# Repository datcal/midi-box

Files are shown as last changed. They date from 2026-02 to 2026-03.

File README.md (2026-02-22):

# MIDI Box

A DIY MIDI router and patchbay built on a Raspberry Pi 4. It connects all your synths, samplers, and sequencers — USB and DIN — and lets you control the routing from your phone or laptop via a web UI. You can also plug it into your Mac and Logic Pro sees every device as its own named MIDI port.

The whole thing runs headless in a box. A 5" touchscreen on the front shows a QR code to connect and a live routing overview.

---

## What it does

- **Routes MIDI** between up to 10 devices (6 USB + 4 five-pin DIN) with any-to-any routing
- **Web UI** — control routing, manage presets, monitor MIDI traffic, all from a browser
- **DAW mode** — plug into a Mac via USB-C and Logic Pro sees each synth as a named port
- **Standalone mode** — Pi handles everything internally, no Mac needed
- **Presets** — save and recall full routing configurations instantly
- **Clip launcher** — Ableton-style session view for triggering MIDI clips, quantized to the beat
- **MIDI file player** — play .mid files to any destination with tempo/loop control
- **MIDI monitor** — live scrolling view of all MIDI messages across all ports
- **Hotplug** — devices coming and going are detected automatically
- **WiFi hotspot** — Pi broadcasts its own network, no router needed

---

## Hardware

| # | Device | Type | Connection |
|---|---|---|---|
| 1 | Arturia KeyLab 88 MK2 | Controller | USB |
| 2 | Arturia KeyStep | Sequencer | USB |
| 3 | Behringer Model D | Mono synth | USB |
| 4 | Roland JP-08 | Polysynth | USB |
| 5 | Arturia MicroBrute | Mono synth | USB |
| 6 | Roland SP-404 MK2 | Sampler | USB |
| 7 | Korg MS-20 Mini | Mono synth | 5-Pin DIN |
| 8 | Korg Volca #1 | Synth | 5-Pin DIN |
| 9 | Korg Volca #2 | Synth | 5-Pin DIN |
| 10 | Korg Volca #3 | Synth | 5-Pin DIN |

**Pi hardware:**
- Raspberry Pi 4 (4GB)
- 5" DSI touchscreen (kiosk UI)
- 2× Waveshare powered USB hubs
- Custom MIDI I/O board (Pi native UARTs → 5-Pin DIN OUT)
- 5V 5A power supply (powers everything)

See [hardware/bom.md](hardware/bom.md) for the full bill of materials and [hardware/schematics/](hardware/schematics/) for circuit diagrams.

---

## How it's built

Two processes communicate over IPC:

```
Process 1 — MIDI Engine (src/main.py)
  Owns all hardware: USB MIDI via ALSA/rtmidi, Pi UARTs for DIN OUT, USB gadget
  Core routing loop: poll inputs → apply filters → send to outputs
  Handles commands from Flask via a shared queue

Process 2 — Web UI (src/ui_web.py)
  Flask app serving the browser UI and REST API
  Reads engine state every 200ms, sends commands via queue
  Never touches MIDI objects directly
```

The engine runs at ~1ms polling. The web UI refreshes at ~5Hz. They stay decoupled so a slow browser request never touches the MIDI loop.

Full architecture notes in [docs/software-arch.md](docs/software-arch.md).

---

## Running on a Mac (dev mode)

No hardware needed — runs with mock MIDI ports.

```bash
cd software
python3 -m venv .venv && source .venv/bin/activate
pip install -r requirements.txt
python3 src/main.py --mode standalone --platform mac --mock -v
```

Open [http://localhost:8080](http://localhost:8080).

Useful flags:
```
--list-devices     show detected MIDI ports
--list-presets     show saved presets
--preset NAME      load a preset on startup
--port PORT        change web UI port (default 8080)
```

---

## Deploying to a Raspberry Pi

Clone the repo onto the Pi and run the setup script once:

```bash
git clone https://github.com/datcal/midi-box ~/midi-box
cd ~/midi-box
sudo bash scripts/pi_setup.sh
```

This installs dependencies, sets up the systemd service, configures the WiFi hotspot, and adds the UART overlays for hardware MIDI. Reboot when it's done.

After reboot:
- WiFi network **MIDI-BOX** appears (password: `midibox123` — change it in Settings)
- Web UI at `http://192.168.4.1:8080`
- QR code on the touchscreen takes you straight there

The service starts on boot and restarts automatically if it crashes.

**Mac + Pi hybrid (DAW mode):**
Connect the Pi to your Mac via USB-C. The Pi's USB gadget presents each synth as a named MIDI port in Logic Pro. Change modes via the web UI or restart with `--mode daw`.

Software updates can be triggered from Settings → Software Update without SSHing in.

---

## Routing

Routes are point-to-point with optional per-route filters:

```json
{
  "from": "KeyLab 88 MK2",
  "to": "MS-20 Mini",
  "filter": {
    "channels": [1, 2],
    "message_types": ["note", "pitchwheel"],
    "velocity_min": 20,
    "remap_channel": 3
  }
}
```

Filter options: `channels`, `remap_channel`, `message_types` (`note`, `cc`, `program_change`, `pitchwheel`, `aftertouch`, `clock`, `sysex`), `velocity_min/max`, `cc_numbers`, `block_clock`, `block_sysex`.

Save any routing setup as a named preset and recall it instantly.

---

## Project layout

```
midi-box/
├── software/
│   ├── src/              Python source (14 modules)
│   ├── config/           App settings, device registry
│   ├── presets/          Saved routing presets (JSON)
│   └── web_ui/           Flask templates + vanilla JS/CSS
├── hardware/
│   ├── bom.md            Bill of materials
│   └── schematics/       MIDI I/O board circuit
├── docs/
│   ├── software-arch.md  Architecture decisions and latency notes
│   ├── gear-inventory.md MIDI specs for all 10 devices
│   └── build-phases.md   Build log
└── scripts/
    ├── pi_setup.sh       One-command Pi installer
    └── update.sh         OTA update helper (used by web UI)
```

---

## License

MIT — see [LICENSE](LICENSE).

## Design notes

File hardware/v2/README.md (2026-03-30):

# MIDI Box v2 — Integrated PCB Design

## Overview

Single custom PCB that replaces all discrete modules from v1 (Pi 4 + 2× Waveshare USB hubs + perfboard MIDI circuits + jumper wires). Everything on one board, designed in KiCad, manufactured and assembled in China (JLCPCB / PCBWay).

## What Changed from v1

| Aspect | v1 (Current) | v2 (This Design) |
|---|---|---|
| Compute | Raspberry Pi 4 full board | **CM4 module** on carrier (this PCB) |
| USB Hub | 2× Waveshare 4-port hubs | **On-board USB2514B** hub ICs (8 ports) |
| Power Input | 5V 5A barrel jack | **USB-C with PD** (STUSB4500 negotiates 5V/3A+) |
| MIDI OUT | Perfboard + jumper wires | **SMD resistors on PCB** + through-hole DIN-5 |
| Wiring | Dupont jumpers, USB cables | **PCB traces** — zero internal cables |
| Enclosure | 3D printed box for loose modules | 3D printed or CNC case **around single PCB** |

## Design Goals

1. **Single board** — CM4 carrier + USB hub + MIDI OUT + power, all on one PCB
2. **USB-C PD power** — standard charger input, no proprietary barrel jack
3. **8× USB-A downstream** — enough for 6 MIDI devices + 2 spare
4. **4× DIN-5 MIDI OUT** — same Pi UART-driven circuits as v1
5. **DSI connector** — 5" touchscreen ribbon passthrough
6. **DAW mode USB-C** — second USB-C port for CM4 USB gadget (Pi → Mac)
7. **Manufacturable** — 4-layer PCB, JLCPCB SMT assembly for SMD parts, hand-solder through-hole connectors
8. **CM4 + CM5 compatible** — same SO-DIMM connector pinout (verify mechanicals)

## Subsystems

| Subsystem | Key Components | Doc |
|---|---|-----|
| Compute | CM4 + Hirose DF40C-100DS connectors | [schematics.md](schematics.md) |
| USB Hub | 2× USB2514B (cascaded, 8 downstream) | [schematics.md](schematics.md) |
| USB-PD Power | STUSB4500 + USB-C connector | [power.md](power.md) |
| MIDI OUT | 4× UART → 220Ω → DIN-5 | [schematics.md](schematics.md) |
| All Components | Full BOM with LCSC part numbers | [bom.md](bom.md) |
| PCB Manufacturing | Layer stackup, fab specs, assembly notes | [pcb-spec.md](pcb-spec.md) |

## Board Size Estimate

~120mm × 100mm (4-layer, 1.6mm thickness). Final size depends on USB-A connector placement — 8 connectors in a row need ~110mm edge length.

## Software Compatibility

**No software changes needed.** The CM4 exposes the same GPIO, UART, USB, and DSI interfaces as the Pi 4. Same device tree overlays, same `/dev/ttyAMA*` paths, same ALSA MIDI stack. The `devices.yaml` and `midi_box.yaml` configs work as-is.

Only change: CM4 Lite (no eMMC) boots from SD card like Pi 4. CM4 with eMMC needs `rpiboot` to flash — update `scripts/inject_sdcard.sh` if using eMMC variant.

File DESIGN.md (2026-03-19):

# MIDI Box — AI Design Prompt

Use the prompt below to generate a new frontend design for this project. Copy-paste it into your AI design tool (v0, Bolt, Lovable, ChatGPT, etc.) and iterate from there.

---

## The Prompt

```
Design a modern, dark-themed web UI for a hardware MIDI router/patchbay called "MIDI Box".
This runs on a Raspberry Pi 4 and is accessed from a phone or laptop over WiFi.
The UI controls MIDI routing between 10 connected instruments (6 USB + 4 hardware DIN).

The design must be a single-page application with a sidebar navigation and a main content area.
Use vanilla HTML + CSS + JS (no frameworks, no build step).
Monospace font family (SF Mono / Fira Code / Consolas fallback).
Dark theme only — this is used in dim studios and on stage.

─────────────────────────────────────────
LAYOUT
─────────────────────────────────────────

Two-column layout:
- LEFT: Fixed sidebar (220px desktop, collapses to 60px icon-only on mobile)
- RIGHT: Scrollable main content area with page-based views

SIDEBAR contains:
- "MIDI BOX" branding header with accent color
- Mode badge (STANDALONE / DAW) — small pill, uppercase
- Live status row: pulsing dot animation + clock label (INT/EXT) + BPM display
- Warning banner when external MIDI clock is lost (yellow/orange)
- Navigation menu (11 items, icons + labels):
  1. Dashboard
  2. Routing
  3. Launcher
  4. Presets
  5. Record
  6. Player
  7. MIDI Monitor
  8. Logs
  9. USB Share
  10. System
  11. Settings
- Footer: large red PANIC button (sends all-notes-off) + device count

─────────────────────────────────────────
COLOR SYSTEM
─────────────────────────────────────────

Use CSS custom properties. Suggested palette (feel free to improve):

  --bg-primary:     deep dark navy      (main background)
  --bg-secondary:   slightly lighter     (sidebar, secondary panels)
  --bg-card:        card surfaces        (elevated cards)
  --bg-hover:       hover/active states
  --text-primary:   light gray           (#e0e0e0 range)
  --text-secondary: medium gray          (labels, hints)
  --text-muted:     dim gray             (disabled, timestamps)
  --accent:         teal/cyan            (primary action color — buttons, links, active states)
  --danger:         red                  (destructive actions, recording indicator)
  --warning:        orange/amber         (queued states, alerts)
  --success:        green                (connected, playing, success)
  --midi-in:        blue                 (MIDI input direction)
  --midi-out:       orange               (MIDI output direction)
  --midi-routed:    purple               (routed messages)
  --border:         subtle dark blue     (card borders, dividers)

─────────────────────────────────────────
PAGE 1: DASHBOARD
─────────────────────────────────────────

Header row with stat chips: device count, route count, total MIDI messages.

Clock widget (2-column card grid):
  - Clock Source card: INT/EXT badge + dropdown to select source device
  - Tempo card: large BPM number input (50px+ font) with −/+ stepper buttons

Connected Devices section:
  - "Rescan Devices" button
  - Warning banner if unconfigured devices detected
  - Responsive grid of device cards (min 240px each), each showing:
    - Device name (bold)
    - Port type badge (USB / DIN)
    - Direction badge (IN / OUT / BOTH)
    - Device type (Controller / Synth / Sampler)
    - Activity indicator dots: blue dot for IN, orange dot for OUT (with glow animation when active)
    - Message count (IN: X / OUT: Y)
    - "Configure" button opening a modal

─────────────────────────────────────────
PAGE 2: ROUTING (Patchbay)
─────────────────────────────────────────

This is the most important and visually striking page.

Mode tabs at top: "Perform" (keyboards → synths only) vs "Advanced" (all devices both sides).
Exclusive mode toggle (pill switch): one source connects to only one destination at a time.

Two-column patchbay layout:
  - LEFT column: Source devices (MIDI senders) — clickable boxes
  - RIGHT column: Destination devices (MIDI receivers) — clickable boxes
  - SVG overlay layer draws bezier curve connection lines between connected pairs
    - Active route: accent/teal colored line with arrow marker
    - Disabled route: gray dashed line
    - Hover preview: green line (will connect) or red line (will disconnect)

Device boxes:
  - Default: card background, subtle border
  - Selected (source): accent border + glow + accent background tint
  - Connected (destination): green border + subtle green background
  - Hover to connect: green border preview
  - Hover to disconnect: red border preview
  - Shows route count badge
  - Shows inline "Filter / Ch" button for connected routes

Below patchbay: Active Routes List
  - Each row: Source → Destination, filter summary text, action buttons (Filter, Enable/Disable toggle, Remove)

─────────────────────────────────────────
PAGE 3: LAUNCHER (Clip Session View)
─────────────────────────────────────────

Inspired by Ableton Live's session view.

Clock bar at top:
  - Clock source selector (Internal / device names)
  - BPM ± buttons and input (disabled when synced to external clock)
  - Quantum selector dropdown (Beat, Bar, 2 Bars, 4 Bars)
  - Time signature selector (4/4, 3/4, 6/8)
  - Beat visualization: "BAR N" label + 4 beat dots (12px circles that light up on active beat, glow animation)
  - Transport: green START button, red STOP button

Layer grid (horizontal rows):
  - Each row = one layer with: layer name, destination device, MIDI channel override
  - Clip slots in columns: 80×56px buttons with rounded corners
    - Empty: dashed border, dim "+" icon
    - Stopped: solid border, clip name label
    - Queued: pulsing orange border + background, warning color
    - Playing: glowing teal border + background, accent color
    - Hover reveals: × remove button (top-right), ↓ start-point marker (bottom-left)

Scene row at bottom: column-wide play buttons to trigger all clips in a column simultaneously.

Controls: Add Layer button, Upload .mid button, Stop All button.

─────────────────────────────────────────
PAGE 4: PRESETS
─────────────────────────────────────────

Simple list/grid of saved routing presets.
  - Each preset: name, click to load
  - Active preset: accent left border + tinted background
  - "Save Current" button opens a save dialog (text input for name)

─────────────────────────────────────────
PAGE 5: RECORD (Quick Recorder)
─────────────────────────────────────────

Clock bar: BPM display (read-only), quantize selector (Free, 1/16, 1/8, 1/4, Bar, 2 Bars, 4 Bars), beat dots.

Transport card:
  - State badge that changes color per state:
    - IDLE (muted), COUNT IN (purple, blinking), ● REC (red, blinking), ▶ PLAYING (green), STOPPED (gray)
  - Elapsed time display
  - Auto-play toggle
  - Buttons: RECORD (red, large), Stop, Play, Clear
  - Stats: event count, loop duration

Live Note Feed (scrollable, monospace):
  - Real-time list of captured MIDI events
  - Columns: Time, Source, Note (green), Velocity, Channel
  - Auto-scrolls during recording

Save section: text input for filename + "Save as .mid" button.

Saved recordings list: rows with name, duration, event count, Play/Download/Delete buttons.

─────────────────────────────────────────
PAGE 6: MIDI MONITOR
─────────────────────────────────────────

Controls: Pause/Resume, Clear, filter checkboxes (hide Clock, hide Active Sensing), message count.

Table with sticky header, 8 columns:
  - Time (HH:MM:SS.mmm)
  - Direction (color-coded: IN=blue, OUT=orange, ROUTED=purple)
  - Source device
  - Destination device
  - Message type (color-coded: NOTE=green, CC=orange, CLOCK=muted)
  - Channel
  - Data (velocity, CC value, etc.)
  - Raw hex bytes

Fast-scrolling, 500 message ring buffer. New messages appear at top.

─────────────────────────────────────────
PAGE 7: PLAYER (MIDI File Playback)
─────────────────────────────────────────

Clock bar: BPM ± and input, destination selector, loop toggle (pill switch), status badge, stop button.

Upload zone:
  - Large dashed-border drop area
  - Icon + "Drop .mid files here or tap to browse"
  - Progress bar overlay during upload

File browser:
  - Breadcrumb navigation for folders
  - Create Folder button
  - File list: folders (icon + name + item count), files (play button + name + duration + tracks)
  - Currently playing file highlighted with accent left border

─────────────────────────────────────────
PAGE 8: LOGS
─────────────────────────────────────────

Simple log viewer card.
  - Clear button
  - Scrollable monospace log area
  - Each entry: timestamp, log level (color-coded: INFO=blue, WARNING=orange, ERROR=red), logger, message

─────────────────────────────────────────
PAGE 9: SYSTEM
─────────────────────────────────────────

Stat cards (3-column grid):
  - CPU: percentage + animated progress bar
  - RAM: percentage + animated progress bar (color changes orange→red at thresholds)
  - Disk: percentage + animated progress bar

Info cards (3-column grid):
  - Temperature (°C)
  - Uptime (formatted)
  - Platform (Raspberry Pi / macOS)

Service control:
  - Status badge (RUNNING = green)
  - Red "Restart Service" button
  - Reconnection status during restart

─────────────────────────────────────────
PAGE 10: SETTINGS
─────────────────────────────────────────

Sections:
  1. Performance Mode toggle
  2. Network MIDI (RTP-MIDI): status badge, session list, rescan button
  3. Software Update: current version, latest version, check/install buttons, update log
  4. WiFi: two QR codes (WiFi join + URL), credentials display, change WiFi form (SSID + password)
  5. Export/Import: download state JSON, upload state JSON
  6. Reset to Defaults (red danger button)

─────────────────────────────────────────
PAGE 11: USB SHARE
─────────────────────────────────────────

  - VirtualHere server status badge + start/stop buttons
  - Warning banner when active (devices pause MIDI routing)
  - Connection instructions with numbered steps
  - Install section with setup button + log output
  - Server log viewer

─────────────────────────────────────────
SHARED COMPONENTS
─────────────────────────────────────────

Cards:
  - Background: card surface color, 1px border, 8px radius, subtle shadow
  - Card header: flex row, space-between, bold title + action buttons

Buttons:
  - Default: subtle border, transparent background, hover highlights
  - Accent: teal/cyan filled, white text
  - Danger: red-tinted background, red border, red text, fills red on hover
  - Small variant for inline actions

Badges/Pills:
  - Small uppercase labels with colored background tint + matching text + thin border
  - Used for: mode (STANDALONE), status (RUNNING), direction (IN/OUT), port type (USB/DIN)

Form inputs:
  - Dark background, subtle border, rounded corners
  - Select dropdowns styled consistently
  - Number inputs with stepper buttons where relevant

Modals:
  - Centered overlay with dark semi-transparent backdrop
  - Card-style modal box (400-500px width)
  - Form rows with labels

Info popovers:
  - Triggered by small circular "ⓘ" buttons
  - Two-section content: "Musician" (friendly) and "Developer" (technical)
  - Positioned within viewport, close on outside click

Toggle switches:
  - Pill-shaped toggle (34×19px track with sliding circle)
  - Off: gray track, On: accent colored track

─────────────────────────────────────────
RESPONSIVE DESIGN
─────────────────────────────────────────

Breakpoints:
  - Desktop (>768px): full sidebar, multi-column grids
  - Tablet/Mobile (≤768px): sidebar collapses to 60px icon-only, grids become single column, patchbay SVG lines hidden

Touch optimization (@media pointer: coarse):
  - Larger buttons (44px+ tap targets)
  - Increased padding on inputs and interactive elements
  - Larger beat dots (16px), clip slots (100px wide, 68px tall)
  - Bigger font sizes for BPM inputs and controls

─────────────────────────────────────────
ANIMATIONS
─────────────────────────────────────────

  - Live pulse: sidebar status dot pulses with scale + opacity (1.5s infinite)
  - Activity glow: device IN/OUT dots glow when receiving MIDI data
  - Clip queued: pulsing border animation (0.8s)
  - Recording blink: red badge blinks during recording (1s), faster during count-in (0.6s)
  - Progress bars: smooth width transitions (0.4s ease)
  - Beat dots: light up sequentially on each beat with subtle glow

─────────────────────────────────────────
DESIGN GOALS
─────────────────────────────────────────

  - Professional music production aesthetic — think Ableton Live, Native Instruments, or DAW plugin UIs
  - High contrast for readability in dark environments (studios, stages)
  - Information-dense but not cluttered — every pixel should serve a purpose
  - The routing patchbay should feel tactile and visual — it's the hero page
  - Real-time feel: activity dots, beat visualization, and state badges should feel alive
  - Touch-friendly: used on phone and Raspberry Pi 5" touchscreen
  - No external dependencies: no CDN fonts, no icon libraries, no CSS frameworks
  - Unicode characters for icons (or inline SVG)

─────────────────────────────────────────
TECHNICAL CONSTRAINTS
─────────────────────────────────────────

  - Output: single HTML file with embedded <style> and <script>, OR separate .html + .css + .js files
  - No build step, no npm, no framework — vanilla only
  - All pages are <div> sections toggled by JS (SPA, hash-based routing)
  - CSS custom properties for theming
  - Must work on: Chrome (desktop + Android), Safari (iOS), Chromium (Pi kiosk)
```

---

## How to Use This Prompt

1. **Copy** everything inside the code fence above
2. **Paste** into your AI design tool (v0.dev, Bolt.new, Lovable, ChatGPT Canvas, etc.)
3. **Iterate** — ask the AI to focus on specific pages ("now redesign just the routing patchbay")
4. **Extract** the HTML/CSS/JS and drop it into `software/web_ui/`

## Tips for Good Results

- Start with one page at a time rather than all 11 at once
- Ask for the **Routing patchbay** first — it's the most complex and visually important
- Then **Dashboard** + **Launcher** — the other two hero pages
- Ask for **just the CSS** if you want to keep the existing HTML structure
- Tell the AI which specific element you want changed ("make the sidebar more minimal", "redesign the device cards")

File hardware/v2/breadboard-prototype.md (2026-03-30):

# MIDI Box v2 — Breadboard Prototype (Same Components)

Test the v2 design on breadboards using the **exact same ICs and components** from [bom.md](bom.md). SMD parts go on adapter/breakout boards, then plug into the breadboard via 2.54mm pin headers.

---

## The Problem & Solution

SMD chips (QFN, SOT-23) can't plug into a breadboard. But you can solder them onto **adapter PCBs** that convert the SMD pads to standard 2.54mm DIP pins.

```
    SMD chip (QFN-36)          Adapter board              Breadboard
    ┌──────────┐          ┌──────────────────┐       ┌─────────────────┐
    │ ■■■■■■■■ │  solder  │ ■■■■■■■■         │  plug │ ○ ○ ○ ○ ○ ○ ○ ○│
    │ ■      ■ │ ───────→ │ ■      ■  ▌▌▌▌▌ │ ────→ │ ○ ○ ○ ○ ○ ○ ○ ○│
    │ ■■■■■■■■ │          │ ■■■■■■■■  ▌▌▌▌▌ │       │ ○ ○ ○ ○ ○ ○ ○ ○│
    └──────────┘          └──────────────────┘       └─────────────────┘
                           (pins on 2.54mm grid)
```

---

## Component-by-Component Plan

### Every v2 BOM item → how to put it on a breadboard:

| v2 Component | Package | Breadboard Method |
|---|---|---|
| **USB2514B** | QFN-36 | QFN-36 to DIP adapter + hand solder |
| **STUSB4500** | QFN-24 | QFN-24 to DIP adapter + hand solder |
| **AP2112K-3.3** (LDO) | SOT-23-5 | SOT-23 to DIP adapter + hand solder |
| **USBLC6-2SC6** (ESD) | SOT-23-6 | SOT-23 to DIP adapter + hand solder |
| **SS34 Schottky** | SMA | SMA to DIP adapter, OR use through-hole **1N5822** (same specs) |
| **24 MHz crystal** | 3215 SMD | Solder onto QFN adapter board next to USB2514B |
| **100nF caps** | 0402 | Use **through-hole 100nF ceramic** (same value, just bigger) |
| **10µF caps** | 0805 | Use **through-hole 10µF electrolytic** (same value) |
| **18pF caps** | 0402 | Use **through-hole 18pF ceramic** |
| **4.7µF cap** | 0805 | Use **through-hole 4.7µF ceramic/electrolytic** |
| **100µF cap** | 8×10mm electrolytic | Already through-hole — **use directly** |
| **220Ω resistors** | 0805 | Use **through-hole 220Ω 1/4W** (same value) |
| **1kΩ resistors** | 0402 | Use **through-hole 1kΩ 1/4W** |
| **1.5kΩ resistors** | 0402 | Use **through-hole 1.5kΩ 1/4W** |
| **5.1kΩ resistors** | 0402 | Use **through-hole 5.1kΩ 1/4W** |
| **10kΩ resistors** | 0402 | Use **through-hole 10kΩ 1/4W** |
| **500mA polyfuses** | 1206 | Use **through-hole 500mA polyfuse** (radial lead) |
| **LEDs** | 0805 | Use **5mm through-hole LEDs** (same colors) |
| **DIN-5 connectors** | Through-hole | **Use directly** — pins fit breadboard |
| **USB-A connectors** | Through-hole | **USB-A female breakout boards** (DIP) |
| **USB-C connectors** | SMD mid-mount | **USB-C female breakout boards** (DIP) |
| **DSI FPC connector** | SMD | Skip — test DSI on CM4 IO Board directly |
| **MicroSD slot** | SMD | Skip — CM4 IO Board has one built in |
| **CM4 + Hirose connectors** | SO-DIMM / 100-pin SMD | **Use CM4 IO Board** as stand-in |

`★ Insight ─────────────────────────────────────`
**Resistors and capacitors are value-defined, not package-defined.** A 220Ω resistor is 220Ω whether it's an 0805 SMD chip or a through-hole 1/4W axial. The circuit doesn't care about the physical size — only the electrical value matters. So for passives (R, C, L), you can freely use through-hole equivalents on a breadboard. The only components where the **exact same physical part** matters are the ICs — those have specific pinouts, internal logic, and configuration registers. That's why we use adapter boards for the ICs but through-hole substitutes for passives.
`─────────────────────────────────────────────────`

---

## Adapter Boards Shopping List

### QFN / SOT-23 to DIP Adapters

These are generic, gold-plated PCBs. Buy a variety pack — they're reusable.

| Adapter | For Which IC | Qty Needed | AliExpress Search | Amazon Search |
|---|---|---|---|---|
| **QFN-36 to DIP-36** (0.5mm pitch) | USB2514B | 2 | `"QFN36 to DIP36 adapter 0.5mm"` | `"QFN36 DIP adapter board"` |
| **QFN-24 to DIP-24** (0.5mm pitch) | STUSB4500 | 1 | `"QFN24 to DIP24 adapter 0.5mm"` | `"QFN24 DIP adapter board"` |
| **SOT-23-5/6 to DIP** | AP2112K, USBLC6 | 10 | `"SOT23 to DIP adapter board"` | `"SOT-23 breakout board"` |
| **SMA to DIP** | SS34 Schottky | 1 | `"SMA diode adapter DIP"` | — (or just use 1N5822 through-hole) |

**Recommended: buy a multi-pack adapter kit**

| Product | Price | What's Inside |
|---|---|---|
| **SMD to DIP adapter assortment kit** | ~$8–12 | AliExpress: `"SMD to DIP adapter board kit QFN SSOP SOT23"` — usually includes QFN-8/16/24/32/36/48, SSOP, SOT-23, SMA, all with pin headers |
| **Specific QFN-36 adapters (5-pack)** | ~$3 | AliExpress: `"QFN36 adapter board 0.5mm pitch"` |

> **Important:** Match the **pitch** (pad spacing) of the adapter to the IC. USB2514B is QFN-36 with **0.5mm pitch**. STUSB4500 is QFN-24 with **0.5mm pitch**. Most adapter kits include 0.5mm versions.

### Pin Headers

You'll solder 2.54mm pin headers onto each adapter board so they plug into the breadboard.

| Product | Qty | Price | Search |
|---|-----|---|---|
| **2.54mm male pin headers** (40-pin strips, breakable) | 5 strips | ~$1 | `"2.54mm pin header male 40 pin"` — you already have these if you've done any Arduino/Pi work |

---

## SMD ICs to Buy (Same as v2 BOM)

Order these from **LCSC.com** directly (minimum order ~$2 shipping). Same parts that go on the final PCB.

| IC | LCSC # | Package | Qty for Breadboard | Unit Price | Notes |
|----|---|---|---|---|---|
| USB2514B-I/M2 | C136518 | QFN-36 | 2 (+ 2 spare) | ~$2.50 | Order 4 — you'll want spares in case of soldering mistakes |
| STUSB4500QTR | C2678061 | QFN-24 | 1 (+ 1 spare) | ~$3.00 | Order 2 |
| AP2112K-3.3TRG1 | C51118 | SOT-23-5 | 1 (+ 2 spare) | ~$0.30 | Order 3 |
| USBLC6-2SC6 | C7519 | SOT-23-6 | 2 (+ 2 spare) | ~$0.25 | Only need 1-2 for testing, not all 9 |
| 24 MHz crystal (3215) | C32346 | 3215 SMD | 2 (+ 2 spare) | ~$0.20 | Solder next to USB2514B on adapter |

**LCSC order total: ~$15–20** (with spares and shipping)

> **Soldering QFN by hand:** You need flux paste, a fine-tip soldering iron (or hot air station), and a magnifier. QFN-36 at 0.5mm pitch is doable by hand but challenging. Search YouTube: `"hand solder QFN"` — drag soldering technique works. If you have a hot air rework station, that's even better. Practice on a spare adapter board first.

---

## Breadboard Connectors to Buy

| Product | Qty | Price | Source | Search |
|---|-----|---|---|---|
| **USB-C female breakout (DIP)** | 3 | ~$1 each | AliExpress | `"USB Type-C female breakout board DIP 2.54mm"` |
| **USB-A female breakout (DIP)** | 7 | ~$0.80 each | AliExpress | `"USB-A female breakout board DIP"` |
| **5-Pin DIN female connector** (PCB mount) | 4 | ~$1 each | AliExpress / Amazon | `"5 pin DIN female connector PCB mount"` — same ones as v2 BOM |
| **JST-XH 2-pin connectors** | 2 | ~$0.30 each | AliExpress | `"JST XH 2pin male PCB header"` — or just use bare wires for fans |

---

## Full Shopping List

### From LCSC.com (exact v2 BOM ICs)

| Item | LCSC # | Qty | Price |
|---|---|-----|---|
| USB2514B-I/M2 | C136518 | 4 | ~$10 |
| STUSB4500QTR | C2678061 | 2 | ~$6 |
| AP2112K-3.3TRG1 | C51118 | 3 | ~$1 |
| USBLC6-2SC6 | C7519 | 4 | ~$1 |
| 24 MHz crystal (3215) | C32346 | 4 | ~$1 |
| **LCSC subtotal** | | | **~$19 + $2 shipping** |

### From AliExpress (adapters + breakouts)

| Item | Qty | Price |
|---|-----|---|
| SMD to DIP adapter kit (QFN + SOT-23) | 1 kit | ~$10 |
| USB-C female breakout (DIP) | 3 | ~$3 |
| USB-A female breakout (DIP) | 7 | ~$6 |
| 5-Pin DIN female connectors | 4 | ~$4 |
| 2.54mm pin header strips | 5 | ~$1 |
| **AliExpress subtotal** | | **~$24** |

### From Amazon / Local Electronics Store (through-hole passives)

| Item | Qty | Price |
|---|-----|---|
| 220Ω resistor 1/4W | 20 (pack) | ~$1 |
| 1kΩ resistor 1/4W | 20 (pack) | ~$1 |
| 1.5kΩ resistor 1/4W | 10 (pack) | ~$1 |
| 5.1kΩ resistor 1/4W | 10 (pack) | ~$1 |
| 10kΩ resistor 1/4W | 10 (pack) | ~$1 |
| 100nF ceramic cap (through-hole) | 20 (pack) | ~$1 |
| 10µF electrolytic cap | 10 (pack) | ~$1 |
| 18pF ceramic cap (through-hole) | 10 (pack) | ~$1 |
| 4.7µF ceramic/electrolytic | 5 | ~$1 |
| 100µF electrolytic cap | 5 | ~$1 |
| 1N5822 Schottky diode (through-hole) | 5 | ~$1 |
| 500mA polyfuse (radial through-hole) | 10 | ~$2 |
| 5mm LEDs (green, blue, yellow assorted) | 10 | ~$1 |
| Full-size breadboard (830 pts) | 2 | ~$10 |
| Jumper wire kit (M-M, M-F) | 1 | ~$5 |
| **Local subtotal** | | **~$29** |

### From Pi Reseller (compute)

| Item | Qty | Price |
|---|-----|---|
| Raspberry Pi CM4 (2GB, WiFi, Lite) | 1 | ~$35 |
| CM4 IO Board (official Raspberry Pi) | 1 | ~$35 |
| **Pi subtotal** | | **~$70** |

### Tools You Need

| Tool | Price | Notes |
|---|---|---|
| Fine-tip soldering iron (or station) | ~$30+ | You probably have one from v1 |
| Solder flux paste (no-clean) | ~$5 | **Essential** for QFN soldering |
| Solder wick / desoldering braid | ~$3 | For fixing bridges |
| Magnifying glass / loupe (10×) | ~$5 | Inspect QFN solder joints |
| USB-C power meter (WITRN C5) | ~$20 | Test PD negotiation + monitor voltage/current |
| Multimeter | — | You have one |
| **Tools subtotal** | **~$33** (if you have soldering iron already: ~$3) |

---

### Total Cost

| Category | Cost |
|---|---|
| LCSC ICs (same parts as v2) | ~$21 |
| AliExpress adapters + breakouts | ~$24 |
| Through-hole passives + breadboard | ~$29 |
| CM4 + IO Board | ~$70 |
| Tools (flux, wick, power meter) | ~$28 |
| **Total** | **~$172** |

> **Note:** The CM4 + IO Board ($70) is not wasted money — the CM4 goes into your final v2 PCB, and the IO Board stays as a permanent debug tool. So the actual "testing overhead" cost is ~$102.

---

## Assembly: Solder ICs onto Adapter Boards

### USB2514B on QFN-36 Adapter (×2)

```
    QFN-36 Adapter Board (top view)
    ┌──────────────────────────────────────┐
    │                                      │
    │  Solder USB2514B (QFN-36) here       │
    │  ┌────────────┐                      │
    │  │ ■■■■■■■■■ │  Also solder nearby: │
    │  │ ■        ■ │  - Y1 (24 MHz xtal) │
    │  │ ■        ■ │  - 2× 18pF caps     │
    │  │ ■■■■■■■■■ │    (CY1a, CY1b)     │
    │  └────────────┘                      │
    │                                      │
    │  ▌▌▌▌▌▌▌▌▌  ← DIP pins (left)      │
    │  ▌▌▌▌▌▌▌▌▌  ← DIP pins (right)     │
    └──────────────────────────────────────┘
```

**Why solder the crystal on the adapter too:** The crystal and its load caps must be physically close (<10mm) to the IC. You can't run them through long breadboard jumper wires — the parasitic capacitance will prevent the oscillator from starting. Solder Y1 + 18pF caps directly on the adapter board, next to the USB2514B.

**QFN soldering steps:**
1. Apply flux paste to the adapter pads
2. Tin one corner pad with a small solder blob
3. Align the IC — tack one corner
4. Check alignment under magnifier
5. Drag-solder remaining pins (or use hot air)
6. Check for bridges with magnifier
7. Remove bridges with solder wick
8. Solder crystal and load caps on nearby pads
9. Solder 2.54mm pin headers on the DIP pads
10. Plug into breadboard

### STUSB4500 on QFN-24 Adapter (×1)

Same process as above, but QFN-24. No crystal needed — just the IC itself.

### AP2112K on SOT-23-5 Adapter (×1)

SOT-23 is much easier to solder than QFN — big pads, visible pins. Straightforward.

### USBLC6 on SOT-23-6 Adapter (×2)

Same as AP2112K — easy SOT-23 soldering. You only need 1-2 for breadboard testing (one on the upstream USB, one on a downstream port). The other 7 can be skipped for prototype.

---

## Breadboard Wiring (Exact v2 Circuit)

### Power Input Section

```
    USB-C breakout #1 (J3 — PD power input)
    ┌────────────┐
    │ VBUS ──────┼──→ STUSB4500 adapter VBUS_EN_SNK pin
    │ CC1 ───────┼──→ 5.1kΩ → GND  AND  STUSB4500 CC1 pin
    │ CC2 ───────┼──→ 5.1kΩ → GND  AND  STUSB4500 CC2 pin
    │ GND ───────┼──→ GND rail
    └────────────┘

    STUSB4500 adapter board (plugged into breadboard)
    ┌────────────────┐
    │ VBUS_EN_SNK ───┼──← USB-C VBUS
    │ CC1 ───────────┼──← USB-C CC1
    │ CC2 ───────────┼──← USB-C CC2
    │ VDD ───────────┼──← 3.3V rail (from LDO)
    │ ADDR ──────────┼──→ 10kΩ → GND
    │ SCL ───────────┼──→ CM4 GPIO 3 (I2C SCL) via IO Board
    │ SDA ───────────┼──→ CM4 GPIO 2 (I2C SDA) via IO Board
    │ POWER_OK ──────┼──→ 1kΩ → green LED → GND (PD status)
    │ GND ───────────┼──→ GND rail
    └────────────────┘

    STUSB4500 VBUS output → 1N5822 anode → cathode → VBUS_5V rail
                                                       │
                                                    100µF cap → GND

    VBUS_5V rail → AP2112K adapter IN → OUT → V3V3 rail
                                          │
                                       10µF cap → GND
```

### USB Hub Section

```
    CM4 IO Board USB-A port
    ──→ cut USB cable ──→ wires:
         red   (5V)  → not needed (hub powered from VBUS_5V rail)
         white (D-)  → USBLC6 adapter IO1 → USB2514B adapter #1 USBDM pin
         green (D+)  → USBLC6 adapter IO2 → USB2514B adapter #1 USBDP pin
         black (GND) → GND rail

    USB2514B Adapter #1 (root hub, plugged into breadboard)
    ┌────────────────────┐
    │ VDD33 ─────────────┼──← V3V3 rail + 100nF cap → GND
    │ VDDA33 ────────────┼──← V3V3 rail + 100nF cap → GND
    │ CRFILT ────────────┼──→ 10nF cap → GND
    │ USBDP ─────────────┼──← CM4 USB D+ (via USBLC6)
    │ USBDM ─────────────┼──← CM4 USB D- (via USBLC6)
    │ RESET_N ───────────┼──→ 10kΩ → V3V3
    │ CFG_SEL0 ──────────┼──→ GND (pin-strap mode)
    │ CFG_SEL1 ──────────┼──→ GND
    │ VBUS_DET ──────────┼──← VBUS_5V via 100kΩ/47kΩ divider
    │                    │
    │ DN1_DP ────────────┼──→ USB-A breakout #1 D+  (→ MIDI device 1)
    │ DN1_DM ────────────┼──→ USB-A breakout #1 D-
    │ DN2_DP ────────────┼──→ USB-A breakout #2 D+  (→ MIDI device 2)
    │ DN2_DM ────────────┼──→ USB-A breakout #2 D-
    │ DN3_DP ────────────┼──→ USB-A breakout #3 D+  (→ MIDI device 3)
    │ DN3_DM ────────────┼──→ USB-A breakout #3 D-
    │ DN4_DP ────────────┼──→ USB2514B adapter #2 USBDP (cascade)
    │ DN4_DM ────────────┼──→ USB2514B adapter #2 USBDM (cascade)
    │ GND ───────────────┼──→ GND rail
    └────────────────────┘

    USB2514B Adapter #2 (tier 2 hub, plugged into breadboard)
    ┌────────────────────┐
    │ (same power/config │
    │  wiring as #1)     │
    │                    │
    │ USBDP ─────────────┼──← Hub #1 DN4_DP (cascade)
    │ USBDM ─────────────┼──← Hub #1 DN4_DM
    │                    │
    │ DN1_DP ────────────┼──→ USB-A breakout #4 D+  (→ MIDI device 4)
    │ DN1_DM ────────────┼──→ USB-A breakout #4 D-
    │ DN2_DP ────────────┼──→ USB-A breakout #5 D+  (→ MIDI device 5)
    │ DN2_DM ────────────┼──→ USB-A breakout #5 D-
    │ DN3_DP ────────────┼──→ USB-A breakout #6 D+  (→ MIDI device 6)
    │ DN3_DM ────────────┼──→ USB-A breakout #6 D-
    │ DN4_DP ────────────┼──→ USB-A breakout #7 D+  (→ spare)
    │ DN4_DM ────────────┼──→ USB-A breakout #7 D-
    │ GND ───────────────┼──→ GND rail
    └────────────────────┘

    Each USB-A breakout:
    VBUS → VBUS_5V rail via 500mA polyfuse
    D+   → from hub DN port
    D-   → from hub DN port
    GND  → GND rail
```

### MIDI OUT Section

```
    MIDI OUT 1 (MS-20 Mini):
    VBUS_5V rail → 220Ω → DIN-5 (J5) Pin 4
    CM4 IO Board GPIO 14 (physical pin 8) → 220Ω → DIN-5 (J5) Pin 5
    DIN-5 (J5) Pin 2 → GND rail

    MIDI OUT 2 (Volca #1):
    VBUS_5V rail → 220Ω → DIN-5 (J6) Pin 4
    CM4 IO Board GPIO 4 (physical pin 7) → 220Ω → DIN-5 (J6) Pin 5
    DIN-5 (J6) Pin 2 → GND rail

    MIDI OUT 3 (Volca #2):
    VBUS_5V rail → 220Ω → DIN-5 (J7) Pin 4
    CM4 IO Board GPIO 8 (physical pin 24) → 220Ω → DIN-5 (J7) Pin 5
    DIN-5 (J7) Pin 2 → GND rail

    MIDI OUT 4 (Volca #3):
    VBUS_5V rail → 220Ω → DIN-5 (J8) Pin 4
    CM4 IO Board GPIO 12 (physical pin 32) → 220Ω → DIN-5 (J8) Pin 5
    DIN-5 (J8) Pin 2 → GND rail
```

### DAW Mode USB-C Section

```
    USB-C breakout #2 (J4 — DAW port)
    ┌────────────┐
    │ D+ ────────┼──→ CM4 IO Board USB OTG D+
    │ D- ────────┼──→ CM4 IO Board USB OTG D-
    │ CC1 ───────┼──→ 5.1kΩ → GND
    │ CC2 ───────┼──→ 5.1kΩ → GND
    │ VBUS ──────┼──→ not connected
    │ GND ───────┼──→ GND rail
    └────────────┘
```

### Status LEDs

```
    Power:          VBUS_5V → 1kΩ → green LED → GND
    PD status:      STUSB4500 POWER_OK → 1kΩ → blue LED → GND
    MIDI TX 1:      GPIO 14 line → 1kΩ → yellow LED → GND
    MIDI TX 2:      GPIO 4  line → 1kΩ → yellow LED → GND
    MIDI TX 3:      GPIO 8  line → 1kΩ → yellow LED → GND
    MIDI TX 4:      GPIO 12 line → 1kΩ → yellow LED → GND
```

---

## Physical Layout (3 Breadboards)

```
    ┌─ BREADBOARD 1: POWER ────────────────────────────────────────┐
    │                                                               │
    │  [USB-C brk]   [STUSB4500]   [1N5822]   [AP2112K]          │
    │   (J3, PD)      adapter      diode        adapter            │
    │                                                               │
    │  [100µF]  [10kΩ]  [5.1kΩ×2]  [100nF×2]  [10µF]  [LED grn] │
    │                                                               │
    │  VBUS_5V rail ━━━━━━━━━━━━━━━━━━━━━━━━━━━━━━━━━━━━━━━━━━━━  │
    │  GND rail ━━━━━━━━━━━━━━━━━━━━━━━━━━━━━━━━━━━━━━━━━━━━━━━━  │
    │  V3V3 rail ━━━━━━━━━━━━━━━━━━━━━━━━━━━━━━━━━━━━━━━━━━━━━━━  │
    └───────────────────────────────────────────────────────────────┘
          │ (bridge 5V, 3.3V, GND to BB2)
          ▼
    ┌─ BREADBOARD 2: USB HUB ──────────────────────────────────────┐
    │                                                               │
    │  [USB2514B #1]       [USB2514B #2]                           │
    │    adapter             adapter                                │
    │   (root hub)          (cascade)                               │
    │                                                               │
    │  [USBLC6]  [100nF×8]  [10µF×2]  [10kΩ×2]  [1.5kΩ×2]       │
    │                                                               │
    │  [USB-A brk1] [brk2] [brk3] [brk4] [brk5] [brk6] [brk7]   │
    │  + polyfuse    + pf   + pf   + pf   + pf   + pf   + pf      │
    │                                                               │
    │  [USB-C brk]  ← DAW port (J4) + 5.1kΩ×2                    │
    └───────────────────────────────────────────────────────────────┘
          │ (bridge 5V, GND to BB3)
          ▼
    ┌─ BREADBOARD 3: MIDI OUT + LEDS ──────────────────────────────┐
    │                                                               │
    │  [220Ω×2] → [DIN-5]   [220Ω×2] → [DIN-5]                   │
    │   MS-20 (J5)            Volca 1 (J6)                         │
    │                                                               │
    │  [220Ω×2] → [DIN-5]   [220Ω×2] → [DIN-5]                   │
    │   Volca 2 (J7)          Volca 3 (J8)                         │
    │                                                               │
    │  [1kΩ→LED] [1kΩ→LED] [1kΩ→LED] [1kΩ→LED]  ← MIDI TX LEDs  │
    │                                                               │
    │  [Fan header 1]  [Fan header 2]   ← 5V direct               │
    └───────────────────────────────────────────────────────────────┘

    CM4 IO Board (off-breadboard, on desk):
    ├── CM4 module plugged in
    ├── MicroSD inserted
    ├── DSI ribbon → 5" touchscreen
    ├── USB-A port → cut cable → BB2 hub upstream
    ├── GPIO 14 (pin 8)  → jumper wire → BB3 MIDI 1
    ├── GPIO 4  (pin 7)  → jumper wire → BB3 MIDI 2
    ├── GPIO 8  (pin 24) → jumper wire → BB3 MIDI 3
    ├── GPIO 12 (pin 32) → jumper wire → BB3 MIDI 4
    ├── GPIO 2  (pin 3)  → jumper wire → BB1 STUSB4500 SCL
    ├── GPIO 3  (pin 5)  → jumper wire → BB1 STUSB4500 SDA
    └── GND (pin 6)      → jumper wire → BB1 GND rail
```

---

## Important Warnings

### USB Signal Integrity on Breadboard

USB 2.0 data lines (D+/D-) are sensitive to capacitance and impedance. Breadboard wiring adds ~5–10pF per jumper wire. This matters:

| Scenario | Will It Work? | Why |
|---|---|-----|
| Hub upstream (CM4 → Hub IC, short wire) | **Yes** | Short run, Full Speed (12 Mbps) tolerant |
| Hub downstream (Hub IC → USB-A, short wire) | **Yes** | MIDI devices are Full Speed |
| Long jumper wires (>15cm) | **Maybe not** | Excess capacitance can cause enumeration failures |
| Hub cascade (Hub #1 → Hub #2, breadboard wire) | **Likely yes** | Keep wires <5cm, use twisted pair if possible |

**Tips:**
- Keep USB D+/D- jumper wires **as short as possible** (< 10cm)
- Twist D+ and D- wires together (reduces noise pickup)
- If a device doesn't enumerate, try a shorter wire first
- MIDI devices are very low bandwidth — they're forgiving

### Crystal Oscillator

The 24 MHz crystal **must** be soldered onto the adapter board next to the IC, not wired via breadboard. Breadboard parasitics will prevent the oscillator from starting. This is the one component that cannot be on the breadboard.

### Power Rails

- Use **both** power rails on each breadboard (top and bottom)
- Bridge them together at both ends of each board
- Add 100nF + 10µF decoupling at every adapter board's power pins
- Run 5V and GND wires between breadboards using thick (22AWG) jumper wires

---

## Test Sequence

Same tests as [testing-plan.md](testing-plan.md), but now with exact v2 components:

| # | Test | Pass Criteria |
|---|---|---|
| 1 | Plug PD charger into USB-C breakout | STUSB4500 POWER_OK LED on, multimeter reads 4.7–5.0V on VBUS_5V |
| 2 | Check 3.3V rail | Multimeter reads 3.3V on V3V3 rail |
| 3 | Boot CM4 on IO Board (powered from VBUS_5V) | CM4 boots, WiFi works, SSH works |
| 4 | USB2514B #1 enumerates | `lsusb` shows Microchip USB hub |
| 5 | USB2514B #2 enumerates (cascade) | `lsusb` shows two Microchip USB hubs |
| 6 | Plug MIDI device into each USB-A breakout | All 6 show in `aconnect -l` |
| 7 | Send MIDI to each DIN-5 port | Synths respond (MS-20, 3× Volca) |
| 8 | DAW mode via USB-C breakout #2 | Mac sees Pi as MIDI device |
| 9 | Run full midi-box software | Web UI works, routing works, presets load |
| 10 | 1-hour stress test | No crashes, no USB disconnects, voltage stable |
| 11 | Measure total current | < 4A (matches power.md budget) |

**If all 11 tests pass → order the final v2 PCB with confidence.**

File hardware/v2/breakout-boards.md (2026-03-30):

# MIDI Box v2 — SMD Breakout Boards for Breadboard Testing

Instead of buying generic off-the-shelf modules, design **small breakout PCBs** for each SMD IC. Solder the SMD parts on the breakout, bring pins out to 2.54mm headers, plug into breadboard.

This gives you **exact same circuits as the final v2 PCB** — just split across small boards connected by jumper wires.

---

## Why Custom Breakout PCBs

- You test the **exact same ICs** (USB2514B, STUSB4500) that go on the final board
- Catches datasheet wiring mistakes early (wrong pin, missing cap)
- Breakout PCBs are **tiny and cheap** — $2 for 5 boards at JLCPCB, 2-layer is fine
- You practice SMD soldering on small boards before committing to the big one
- Reusable — keep them as test fixtures even after the v2 PCB works

`★ Insight ─────────────────────────────────────`
**This is standard practice in hardware engineering.** Companies like Adafruit and SparkFun literally sell breakout boards for this exact reason — the STUSB4500 breakout from SparkFun is $12. But you can make your own in EasyEDA for $2 in quantity 5, with the exact same circuit you designed. If it works on the breakout, it works on the final PCB — the IC doesn't know what board it's on.
`─────────────────────────────────────────────────`

---

## Breakout Board Designs (4 boards)

### Board 1: USB Hub Breakout (USB2514B)

**Size:** ~30mm × 40mm, 2-layer

**SMD components ON the breakout:**
- 1× USB2514B-I/M2 (QFN-36) — `C136518`
- 1× 24 MHz crystal — `C32346`
- 2× 18pF cap (0402) — `C1808`
- 4× 100nF cap (0402) — `C1525`
- 1× 10µF cap (0805) — `C19702`
- 1× 1.5kΩ resistor (0402) — `C4026`

**Pin headers OUT (2.54mm, breadboard-compatible):**

```
    Left side (1×10 header):         Right side (1×10 header):
    ┌────────────────────┐
    │ USBUP_D+     DN1_D+ │
    │ USBUP_D-     DN1_D- │
    │ VDD (5V)     DN2_D+ │
    │ GND          DN2_D- │
    │ RESET_N      DN3_D+ │
    │ CFG_SEL0     DN3_D- │
    │ CFG_SEL1     DN4_D+ │
    │ VBUS_DET     DN4_D- │
    │ 3.3V IN      GND    │
    │ GND          GND    │
    └────────────────────┘
```

**Make 2 of these** — one for IC1 (root hub), one for IC2 (cascaded). On the breadboard, wire IC1 DN4 → IC2 upstream to cascade them.

**EasyEDA steps:**
1. New project: `usb-hub-breakout`
2. Place USB2514B (`C136518`), crystal, caps, resistor
3. Wire exactly as in [schematics.md](schematics.md) Section 2
4. Add 2× 1×10 male pin headers (search `C124378` — 1×10 2.54mm)
5. Route on 2-layer, no impedance control needed (traces are <15mm)
6. Board outline: 30×40mm

**JLCPCB order:**
- 2-layer, 5 pcs, 1.6mm, HASL — ~$2
- SMT assembly for SMD parts — ~$8
- Total: ~$10 for 5 boards (you need 2)

---

### Board 2: USB-PD Breakout (STUSB4500)

**Size:** ~20mm × 25mm, 2-layer

**SMD components ON the breakout:**
- 1× STUSB4500QTR (QFN-24) — `C2678061`
- 2× 5.1kΩ resistor (0402) — `C25905` (CC pull-downs)
- 1× 10kΩ resistor (0402) — `C25744` (ADDR)
- 1× 4.7µF cap (0805) — `C1779`
- 1× 100nF cap (0402) — `C1525`

**Connectors ON the breakout:**
- 1× USB-C 16-pin receptacle — `C2765186` (solder directly on breakout)

**Pin headers OUT:**

```
    1×6 header:
    ┌──────────┐
    │ VBUS_OUT │ → 5V from PD charger (after negotiation)
    │ GND      │
    │ POWER_OK │ → HIGH when PD contract established
    │ SCL      │ → I2C clock (for NVM programming)
    │ SDA      │ → I2C data
    │ 3.3V IN  │ → supply for STUSB4500 logic
    └──────────┘
```

**On breadboard:**
- Plug header into breadboard
- VBUS_OUT → 5V power rail
- Connect SCL/SDA to Pi GPIO 2/3 (for one-time NVM programming)
- 3.3V IN from AMS1117 module or another source

**EasyEDA steps:**
1. New project: `usb-pd-breakout`
2. Place STUSB4500 (`C2678061`), USB-C connector (`C2765186`), resistors, caps
3. Wire as in [power.md](power.md) STUSB4500 circuit section
4. Add 1×6 male pin header
5. Board outline: 20×25mm

---

### Board 3: USB-C Gadget Port Breakout (DAW Mode)

**Size:** ~15mm × 20mm, 2-layer

This one is super simple — just a USB-C connector with CC resistors, broken out to pins.

**SMD components ON the breakout:**
- 2× 5.1kΩ resistor (0402) — `C25905`

**Connectors ON the breakout:**
- 1× USB-C 16-pin receptacle — `C2765186`

**Pin headers OUT:**

```
    1×4 header:
    ┌──────┐
    │ D+   │ → to Pi USB OTG / CM4 gadget port
    │ D-   │
    │ VBUS │ → sense only (from Mac)
    │ GND  │
    └──────┘
```

**On breadboard:**
- Not actually needed for breadboard — just connect a USB-C cable from Pi to Mac
- But useful to validate the USB-C connector footprint and CC resistor values

---

### Board 4: MIDI OUT Breakout (×1, simple)

**Size:** ~25mm × 35mm, 2-layer

Optional — you could just do this on the breadboard with through-hole parts. But if you want to validate the exact SMD layout:

**SMD components ON the breakout:**
- 2× 220Ω resistor (0805) — `C17557`
- 1× yellow LED (0805) — `C2296` (optional)
- 1× 1kΩ resistor (0402) — `C11702` (optional, for LED)

**Connectors ON the breakout:**
- 1× DIN-5 female (through-hole) — hand solder

**Pin headers OUT:**

```
    1×3 header:
    ┌───────┐
    │ 5V    │ → power rail
    │ TX    │ → Pi GPIO UART TX
    │ GND   │ → ground
    └───────┘
```

**Make 4 of these** for all 4 MIDI ports — or just 1 and test each UART sequentially.

---

## Complete Breakout → Breadboard Wiring

```
    ┌───────────────────────────────────────────────────────────┐
    │                     BREADBOARD                            │
    │  [+5V rail] ━━━━━━━━━━━━━━━━━━━━━━━━━━━━━━━━━━━━━━━━━━  │
    │  [GND rail] ━━━━━━━━━━━━━━━━━━━━━━━━━━━━━━━━━━━━━━━━━━  │
    │                                                           │
    │  ┌──────────┐                                             │
    │  │ PD Board │ VBUS_OUT ──→ 5V rail                       │
    │  │ (Board 2)│ GND ──→ GND rail                           │
    │  │ USB-C IN │ 3.3V IN ←── AMS1117 out                    │
    │  └──────────┘                                             │
    │       │ (or skip PD board, use 5V bench supply directly)  │
    │                                                           │
    │  ┌──────────────┐  ┌──────────────┐                      │
    │  │ Hub Board #1 │  │ Hub Board #2 │                      │
    │  │  (Board 1a)  │  │  (Board 1b)  │                      │
    │  │              │  │              │                        │
    │  │ USBUP_D+/D- │  │ USBUP_D+/D- │                       │
    │  │  ↑ from Pi   │  │  ↑ from Hub1 │                      │
    │  │  USB port    │  │    DN4       │                       │
    │  │              │  │              │                        │
    │  │ DN1 ──→ USB-A breakout ──→ MIDI device 1              │
    │  │ DN2 ──→ USB-A breakout ──→ MIDI device 2              │
    │  │ DN3 ──→ USB-A breakout ──→ MIDI device 3              │
    │  │ DN4 ──→ Hub Board #2 upstream                         │
    │  │              │  │ DN1 ──→ USB-A breakout ──→ device 4 │
    │  └──────────────┘  │ DN2 ──→ USB-A breakout ──→ device 5 │
    │                     │ DN3 ──→ USB-A breakout ──→ device 6 │
    │                     │ DN4 ──→ USB-A breakout ──→ spare    │
    │                     └──────────────┘                      │
    │                                                           │
    │  MIDI OUT ports (Board 4 ×4, or through-hole on BB):     │
    │  ┌───────┐ ┌───────┐ ┌───────┐ ┌───────┐                │
    │  │MIDI 1 │ │MIDI 2 │ │MIDI 3 │ │MIDI 4 │                │
    │  │5V←rail│ │5V←rail│ │5V←rail│ │5V←rail│                │
    │  │TX←GP14│ │TX←GP4 │ │TX←GP8 │ │TX←GP12│                │
    │  │GND←rl │ │GND←rl │ │GND←rl │ │GND←rl │                │
    │  │[DIN5] │ │[DIN5] │ │[DIN5] │ │[DIN5] │                │
    │  └───────┘ └───────┘ └───────┘ └───────┘                │
    │                                                           │
    │  [+5V rail] ━━━━━━━━━━━━━━━━━━━━━━━━━━━━━━━━━━━━━━━━━━  │
    │  [GND rail] ━━━━━━━━━━━━━━━━━━━━━━━━━━━━━━━━━━━━━━━━━━  │
    └───────────────────────────────────────────────────────────┘

    Raspberry Pi 4 (off breadboard):
    ├── USB-A port → cut cable → Hub Board #1 upstream (D+, D-, 5V, GND)
    ├── GPIO 14 (pin 8)  → jumper → MIDI 1 TX
    ├── GPIO 4  (pin 7)  → jumper → MIDI 2 TX
    ├── GPIO 8  (pin 24) → jumper → MIDI 3 TX
    ├── GPIO 12 (pin 32) → jumper → MIDI 4 TX
    ├── 5V (pin 2) → jumper → 5V rail (if not using PD board)
    └── GND (pin 6) → jumper → GND rail
```

---

## Order Summary for Breakout Boards

Order all breakout PCBs in one JLCPCB order to save on shipping:

| Board | Qty to Order | 2-Layer PCB Cost | SMT Assembly | Components |
|---|---|---|---|---|
| USB Hub Breakout | 5 pcs (need 2) | ~$2 | ~$8 | ~$5 |
| USB-PD Breakout | 5 pcs (need 1) | ~$2 | ~$5 | ~$4 |
| USB-C DAW Breakout | 5 pcs (need 1) | ~$2 | ~$3 | ~$1 |
| MIDI OUT Breakout | 5 pcs (need 1–4) | ~$2 | ~$3 | ~$2 |
| **Total** | | **~$8** | **~$19** | **~$12** |

**Grand total: ~$39 + shipping (~$8) ≈ $47**

Plus breadboard + jumper wires + through-hole parts: ~$20

**Full breadboard prototype cost: ~$65–70**

---

## Build Order

| Phase | What to Do | Time |
|---|---|---|
| 1 | Design 4 breakout boards in EasyEDA (simple, 2-layer each) | 2–3 hours |
| 2 | Order from JLCPCB (SMT assembled) | 5 min + 7–14 day wait |
| 3 | Hand-solder pin headers + DIN-5 on breakouts | 30 min |
| 4 | Wire up breadboard | 1 hour |
| 5 | Boot Pi, run software, test all subsystems | 1–2 hours |
| 6 | Fix any issues, iterate | varies |
| 7 | **Green light → order the full v2 PCB** | |

---

## What This Validates That Off-the-Shelf Boards Don't

| Validation | Off-the-shelf module | Custom breakout |
|---|---|---|
| USB2514B pin-strap config works | N/A (different IC) | **Yes — same IC, same config** |
| STUSB4500 negotiates 5V PD | Maybe (SparkFun board) | **Yes — same IC, your NVM config** |
| USB-C CC resistor values correct | No | **Yes** |
| Crystal + load cap values correct | No | **Yes** |
| Decoupling cap placement sufficient | No | **Yes** |
| Your schematic has no wiring errors | **No** | **Yes — this is the main win** |

`★ Insight ─────────────────────────────────────`
**The real value of custom breakouts:** You're not just testing whether "a USB hub works" — you're testing whether **your specific USB2514B circuit, with your specific pin-strap configuration, your specific crystal, and your specific decoupling layout** works. If the breakout works, you can copy-paste that exact sub-circuit into the v2 PCB with near-certainty. If you used a generic module, you'd still have uncertainty about your own design.

**Bonus: soldering practice.** QFN-36 (USB2514B) is the hardest package in this design. If you can solder it successfully on a small breakout board, you'll have confidence in the full PCB assembly. Or if JLCPCB assembles it for you — you've validated their assembly quality on a cheap board before trusting them with the expensive one.
`─────────────────────────────────────────────────`

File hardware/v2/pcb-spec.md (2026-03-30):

# MIDI Box v2 — PCB Manufacturing Specification

## Fabrication Specs

Order from JLCPCB or PCBWay. These specs are compatible with both.

| Parameter | Value | Notes |
|---|---|---|
| **Layers** | 4 | Signal – GND – Power – Signal |
| **Board thickness** | 1.6mm | Standard |
| **Copper weight** | 1 oz (outer), 1 oz (inner) | 1 oz is fine for our currents |
| **Board dimensions** | ~120mm × 100mm | Final size TBD after layout |
| **Min trace width** | 0.15mm (6 mil) | USB diff pairs will be wider |
| **Min trace spacing** | 0.15mm (6 mil) | |
| **Min via drill** | 0.3mm | Standard via |
| **Surface finish** | **ENIG** (recommended) or HASL | ENIG for fine-pitch QFN pads |
| **Solder mask** | Green (cheapest) or black | |
| **Silkscreen** | White | Both sides |
| **Impedance control** | **Yes** — 90Ω differential for USB | Specify in JLCPCB order notes |
| **Castellated holes** | No | |
| **Panelization** | No (single board) | |

---

## 4-Layer Stackup

```
    Layer 1 (Top)     — Signal: USB data, MIDI TX, SD, component pads
    Layer 2 (Inner 1) — GND plane (solid, unbroken)
    Layer 3 (Inner 2) — Power plane (5V and 3.3V split)
    Layer 4 (Bottom)  — Signal: remaining traces, through-hole pads
```

### Why 4 Layers?

1. **USB 2.0 impedance** — 90Ω differential pairs need a solid reference plane directly below. With a 2-layer board, impedance control is nearly impossible.
2. **Power integrity** — solid 5V plane distributes current evenly to CM4, hub ICs, and USB ports without thick traces.
3. **EMI** — ground plane shields MIDI UART signals (31250 baud) from USB (480 MHz) crosstalk.
4. **Cost** — JLCPCB 4-layer is only ~$2 more than 2-layer for 5 boards. Negligible.

---

## Trace Width Guidelines

| Signal Type | Width | Spacing | Layer | Notes |
|---|---|---|---|---|
| USB 2.0 differential pairs | **0.18mm** (7 mil) | 0.18mm gap | Top | 90Ω differential impedance (check JLCPCB calculator) |
| DSI differential pairs | **0.1mm** (4 mil) | 0.15mm gap | Top | 100Ω differential — short traces only |
| MIDI TX (UART, 31250 baud) | 0.25mm (10 mil) | — | Top or Bottom | Low speed, no impedance requirement |
| SD card data | 0.2mm (8 mil) | — | Top | Keep traces <50mm, matched length |
| 5V power traces | 0.5mm+ (20 mil) | — | Top / Power plane | Use plane for main distribution |
| 3.3V power traces | 0.3mm (12 mil) | — | Power plane | Low current rail |
| I2C (SCL/SDA) | 0.2mm (8 mil) | — | Any | Short run to STUSB4500 only |
| General GPIO | 0.2mm (8 mil) | — | Any | LEDs, boot config |

---

## Layout Guidelines

### CM4 Connector Area
- Place J1 and J2 (Hirose 100-pin) at the center or one edge of the board
- Keep decoupling caps (C1–C5) within **5mm** of connector pins
- Route USB and DSI differential pairs on the top layer, directly over the GND plane
- MicroSD slot (J18) near CM4 — SD traces should be <30mm

### USB Hub ICs
- Place U2 (IC1) and U3 (IC2) near the CM4 USB output
- Crystal (Y1, Y2) within **10mm** of the IC, with ground guard ring
- Route downstream USB pairs as matched-length differential pairs
- Keep each D+/D- pair length-matched within **0.5mm**

### USB-A Connectors
- Place along one or two edges of the board (8 connectors)
- Option A: **8 in a row** on one edge (~110mm total width)
- Option B: **4 per edge** on two opposite edges
- Through-hole connectors — ensure clearance for plastic housing on the board edge
- ESD protection ICs (U4–U11) placed **as close as possible** to each connector

### MIDI DIN-5 Connectors
- Place along one edge, away from USB connectors
- Through-hole, spaced ~25mm center-to-center
- 220Ω resistors (0805 SMD) placed within 10mm of each DIN connector
- Route MIDI TX traces on bottom layer to avoid crossing USB pairs

### Power Input (USB-C PD)
- Place J3 (USB-C power) at a board edge — typically opposite from data connectors
- STUSB4500 (U13) within 15mm of J3
- Bulk cap C20 (100µF) close to J3
- Schottky D1 between J3 VBUS and the 5V rail

### DSI FPC Connector
- Place J17 at a board edge for easy ribbon cable routing to the display
- DSI differential pairs: short as possible, length-matched within pair

### Fan Headers
- Place J19, J20 at board edge or near mounting holes
- Connected directly to 5V and GND planes

---

## Mounting Holes

| Hole | Size | Purpose |
|---|---|---|
| H1–H4 | M3 (3.2mm drill) | PCB mounting to enclosure |
| | Pad: 6mm copper ring | Connect to GND plane for shielding |

Place at four corners, inset ~5mm from board edge. Match to enclosure standoff positions.

---

## Component Placement Map (Conceptual)

```
    ┌──────────────────────────────────────────────────────────┐
    │  [USB-C PD]  [USB-C DAW]          [Fan] [Fan]          │ ← Top edge
    │     J3           J4                J19   J20            │
    │                                                          │
    │  ┌──────────┐  ┌──────────┐                             │
    │  │ STUSB4500│  │  LDO     │                             │
    │  │  (U13)   │  │ (U14)    │                             │
    │  └──────────┘  └──────────┘                             │
    │                                                          │
    │  (H1)                                          (H2)     │
    │                                                          │
    │      ┌──────────────────────────────┐                   │
    │      │     CM4 Module (J1, J2)      │                   │
    │      │     (Hirose connectors)      │                   │
    │      └──────────────────────────────┘                   │
    │                    │                                     │
    │            ┌───────┴───────┐                             │
    │            │    [SD Card]  │                             │
    │            │     J18       │                             │
    │            └───────────────┘                             │
    │                                                          │
    │  ┌─────┐  ┌─────┐                                      │
    │  │USB  │  │USB  │      [DSI FPC]                        │
    │  │Hub  │  │Hub  │        J17                            │ ← Right edge
    │  │IC1  │  │IC2  │                                       │
    │  │(U2) │  │(U3) │                                       │
    │  └─────┘  └─────┘                                       │
    │                                                          │
    │  (H3)                                          (H4)     │
    │                                                          │
    │ [J9][J10][J11][J12][J13][J14][J15][J16]                │ ← Bottom edge: 8× USB-A
    │                                                          │
    │ [J5 DIN][J6 DIN][J7 DIN][J8 DIN]                       │ ← Bottom edge: 4× MIDI OUT
    └──────────────────────────────────────────────────────────┘
```

> This is a rough placement guide. Adjust based on actual footprint sizes and routing constraints. The key rule: **USB connectors and MIDI connectors on accessible edges, power input on a separate edge.**

---

## Assembly Notes

### JLCPCB SMT Assembly

| Assembly Type | Components |
|---|---|
| **SMT (top side)** | All SMD: resistors, caps, ICs (USB2514B, STUSB4500, LDO, ESD), LEDs, crystals |
| **Through-hole (hand solder)** | DIN-5 ×4, USB-A ×8, JST fan headers ×2, DSI FPC |

Order SMT assembly from JLCPCB for all SMD parts. Hand-solder the through-hole connectors yourself — they're all standard and easy to solder.

### BOM and CPL Files

When ordering from JLCPCB, export from KiCad:
1. **Gerber files** — all 4 copper layers + mask + silkscreen + drill
2. **BOM CSV** — columns: `Comment, Designator, Footprint, LCSC Part Number`
3. **CPL (Component Placement List)** — columns: `Designator, Mid X, Mid Y, Rotation, Layer`

Use the [KiCad JLCPCB plugin](https://github.com/Bouni/kicad-jlcpcb-tools) to auto-generate these.

---

## Design Rule Check (DRC) Settings

Set these in KiCad before running DRC:

| Rule | Value |
|---|---|
| Min clearance | 0.15mm |
| Min trace width | 0.15mm |
| Min via drill | 0.3mm |
| Min via annular ring | 0.13mm |
| Min hole-to-hole | 0.5mm |
| Board edge clearance | 0.3mm |
| Silk-to-pad clearance | 0.15mm |

---

## Pre-Order Checklist

Before submitting to JLCPCB:

- [ ] Run KiCad DRC — zero errors
- [ ] Run KiCad ERC (electrical rules check) — zero errors
- [ ] Verify all LCSC part numbers are in stock
- [ ] Check USB differential pair impedance with JLCPCB stackup calculator
- [ ] Verify CM4 connector footprint matches Hirose DF40C-100DS datasheet
- [ ] Confirm DIN-5 footprint pin assignment (pin 4 = source, pin 5 = sink)
- [ ] Check board outline fits inside enclosure design
- [ ] Verify mounting hole positions match enclosure standoffs
- [ ] Check all through-hole components have sufficient annular ring
- [ ] Generate and review 3D render in KiCad before ordering

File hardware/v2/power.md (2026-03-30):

# MIDI Box v2 — Power Distribution

## Power Input: USB-C with Power Delivery

Replaces the v1 barrel jack with a standard USB-C PD input. The STUSB4500 IC negotiates a power contract with the charger.

### PD Contract

| Parameter | Value |
|---|---|
| Requested voltage | **5V** |
| Requested current | **3A** (minimum) |
| Ideal charger | 5V/5A USB-C PD (25W) |
| Fallback | 5V/3A (standard USB-C) — enough for basic operation |

The STUSB4500 is configured via NVM (one-time programming over I2C) to request 5V @ 3A as PDO1. If the source can provide more (5A), the system will draw what it needs — PD is negotiated max, not forced draw.

> **Why not 9V/12V?** The CM4, USB hub ICs, and MIDI circuits all need 5V. Using a higher PD voltage would require a buck converter, adding cost and complexity. 5V direct is simpler and the whole system runs under 4A.

### STUSB4500 Circuit

```
                    USB-C Connector (J3)
                    ┌─────────────────┐
                    │ VBUS ───────────┼──→ D1 (Schottky) ──→ VBUS_5V rail
                    │ CC1 ────────────┼──→ R3 (5.1kΩ) ──→ GND
                    │ CC2 ────────────┼──→ R4 (5.1kΩ) ──→ GND
                    │ D+ (not used)   │    ├──→ STUSB4500 CC1 pin
                    │ D- (not used)   │    └──→ STUSB4500 CC2 pin
                    │ GND ────────────┼──→ GND
                    └─────────────────┘

                    ┌─────────────────┐
                    │   STUSB4500     │
                    │   (U13)         │
                    │                 │
           CC1  ───┤ CC1             │
           CC2  ───┤ CC2             │
          VBUS  ───┤ VBUS_EN_SNK     │── (VBUS sense)
                   │ VDD     ────────┤── 3.3V (from LDO)
                   │ ADDR    ────────┤── R5 (10kΩ) to GND (I2C addr = 0x28)
                   │ SCL     ────────┤── CM4 GPIO 2 (I2C1 SCL) — for NVM programming
                   │ SDA     ────────┤── CM4 GPIO 3 (I2C1 SDA) — for NVM programming
                   │ POWER_OK ───────┤── (optional: LED or CM4 GPIO for PD status)
                   │ GND     ────────┤── GND
                   └─────────────────┘

    Decoupling:
    VDD  ── C18 (4.7µF) ── GND
    VDD  ── C19 (100nF) ── GND
    VBUS ── C20 (100µF electrolytic) ── GND
```

### STUSB4500 NVM Configuration

The STUSB4500 stores its PD configuration in on-chip NVM. Program once via I2C before deployment:

| NVM Field | Value | Notes |
|---|---|---|
| PDO1 Voltage | 5V | Only voltage we need |
| PDO1 Current | 3.0A | Minimum acceptable |
| PDO2 | Disabled | We don't need 9V/12V/20V |
| PDO3 | Disabled | |
| SNK_UNCONS_POWER | 0 | Not an unconstrainted sink |
| REQ_SRC_CURRENT | 1 | Request source's max current |

Use ST's GUI tool or the `pystusb4500` Python library to program NVM over I2C.

---

## Power Distribution Tree

```
    USB-C PD (J3) ── D1 (Schottky) ──┬── VBUS_5V (main 5V rail)
                                      │
                 ┌────────────────────┼────────────────────────────────┐
                 │                    │                                │
            ┌────┴────┐          ┌────┴────┐                     ┌────┴────┐
            │ CM4 5V  │          │ USB Hub │                     │  Other  │
            │ (J1/J2) │          │  Power  │                     │         │
            └────┬────┘          └────┬────┘                     └────┬────┘
                 │                    │                                │
            ~2.0A max           ┌─────┼─────┐                    ├── MIDI OUT (50mA)
            (CM4 + screen)      │     │     │                    ├── Fans ×2 (400mA)
                                │     │     │                    ├── LEDs (20mA)
                           F1-F4  F5-F7  (polyfuses)            └── LDO → 3.3V (50mA)
                              │     │
                         USB ports USB ports
                         (150-200mA each)
```

---

## 5V Rail Budget

| Consumer | Current Draw | Notes |
|---|---|---|
| CM4 + WiFi | ~1.5A | CM4 draws less than full Pi 4 (no HDMI, no onboard USB hub) |
| 5" DSI touchscreen | ~0.3A | Via DSI connector, powered from CM4 5V |
| USB Hub ICs (U2, U3) | ~0.1A | Logic power only |
| USB devices (6× MIDI) | ~1.2A | ~200mA each worst case |
| 2× Cooling fans | ~0.4A | Always-on, direct from 5V rail |
| MIDI OUT (4× 220Ω circuits) | ~0.05A | ~8.6mA per active port |
| LDO (3.3V rail) | ~0.05A | STUSB4500 + hub IC logic |
| LEDs | ~0.02A | 6× LEDs @ ~3mA each |
| **Total** | **~3.6A** | |
| **Supply (PD 5V/5A)** | **5.0A** | **~1.4A headroom** |

> Same total as v1 — the load hasn't changed, just the packaging. The headroom is comfortable.

---

## 3.3V Rail

A small LDO (AP2112K-3.3) generates 3.3V from the 5V rail for:
- STUSB4500 VDD
- USB2514B VDD33 / VDDA33 (hub IC logic)
- Pull-up resistors

```
    VBUS_5V ── C22 (100nF) ──┬── AP2112K-3.3 (U14) ──┬── V3V3 (3.3V rail)
                              │     │                   │
                             GND   GND              C21 (10µF) ── GND
```

The AP2112K provides up to 600mA — we draw ~50mA on this rail. Massive headroom.

> **CM4 has its own internal 3.3V regulator** — do NOT power CM4 from this LDO. CM4 takes 5V only and regulates internally.

---

## Protection

### Reverse Polarity (D1)

```
    VBUS (from USB-C) ── D1 (SS34 Schottky, 3A) ── VBUS_5V
```

Forward voltage drop: ~0.3V at 3A. So VBUS_5V is ~4.7V under load. This is fine — CM4 input range is 4.75V–5.25V, and USB PD sources deliver 5.0V–5.25V.

If the 0.3V drop is a concern, replace D1 with an **ideal diode IC** (e.g., LTC4357) for <50mV drop. For prototype, the Schottky is fine.

### Per-Port Overcurrent (F1–F8)

Each USB-A downstream port has a 500mA polyfuse (resettable PTC fuse):

```
    VBUS_5V ── F1 (500mA polyfuse) ── J9 VBUS pin
    VBUS_5V ── F2 (500mA polyfuse) ── J10 VBUS pin
    ... (one per port)
```

If a connected device shorts or draws >500mA, the polyfuse trips and resets when the fault clears. No damage to the main rail or other devices.

### Input Bulk Capacitance

```
    VBUS_5V ── C20 (100µF electrolytic) ── GND     (main input filter)
              + additional 100nF ceramic near each IC
```

The 100µF cap handles inrush and load transients. Place it as close to the USB-C connector as possible.

---

## Thermal Considerations

| Component | Power Dissipation | Notes |
|---|---|---|
| D1 (Schottky) | ~1W at 3A | Gets warm — use SMA package with large pad, or thermal relief |
| AP2112K (LDO) | ~85mW | 50mA × (5V−3.3V) = negligible |
| USB2514B (×2) | ~200mW each | Normal operating range |
| Polyfuses | ~50mW each (normal) | Only heat up when tripping |

The Schottky diode is the only component that needs thermal attention. Give it a generous copper pour on the cathode pad. If using an ideal diode IC instead, thermal is a non-issue.

---

## Test Points

Add test points on the PCB for debugging:

| TP | Net | Purpose |
|----|-----|---|
| TP1 | VBUS_5V | Main 5V rail voltage |
| TP2 | V3V3 | 3.3V rail voltage |
| TP3 | GND | Ground reference |
| TP4 | POWER_OK | STUSB4500 PD negotiation status |

---

## Charger Recommendations

| Charger | Compatibility |
|---|---|
| Any USB-C PD charger (5V/3A+) | Full operation |
| USB-C 5V/1.5A (non-PD) | CM4 boots but USB devices may brownout |
| USB-A to USB-C cable | **Will not work** — no PD, only 500mA |
| Apple 20W/30W charger | Works (supports 5V/3A) |
| Anker 65W GaN charger | Works (supports 5V/3A PDO) |

Always use a cable rated for 3A+ (not a charge-only thin cable).

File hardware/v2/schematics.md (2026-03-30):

# MIDI Box v2 — Circuit Schematics

All circuits documented here as ASCII schematics for reference when drawing in KiCad. Organized by subsystem as hierarchical sheets.

---

## 1. CM4 Carrier Interface

The CM4 connects via two 100-pin Hirose DF40C connectors (J1, J2). Only the pins we actually use are listed below — leave others unconnected.

### Pinout (Signals We Use)

**Connector J1 (Primary):**

| Pin | Signal | Our Use |
|-----|---|---|
| 2, 6, 10, 14, 18, 22 | GND | Ground |
| 1, 3 | GND, VBAT | Not used (we don't need battery backup) |
| 4 | 5V_IN | **5V power to CM4** (from PD rail) |
| 5 | 5V_IN | **5V power to CM4** (parallel with pin 4) |
| 76 | GPIO 14 (UART0 TX) | **MIDI OUT → MS-20** |
| 80 | GPIO 4 (UART3 TX) | **MIDI OUT → Volca #1** |
| 82 | GPIO 8 (UART4 TX) | **MIDI OUT → Volca #2** |
| 84 | GPIO 12 (UART5 TX) | **MIDI OUT → Volca #3** |
| 87 | GPIO 0 (ID_SD) | EEPROM (leave floating or pull up) |
| 88 | GPIO 1 (ID_SC) | EEPROM (leave floating or pull up) |

**Connector J2 (Secondary):**

| Pin | Signal | Our Use |
|-----|---|---|
| 1–4 | USB D-, D+, D-, D+ | **USB 2.0 to hub IC (upstream)** |
| 5–8 | USB2 (secondary port) | **USB gadget (DAW mode)** → J4 USB-C |
| 30–45 | DSI signals | **DSI passthrough** → J17 FPC |
| 74 | SD_CLK | MicroSD |
| 76 | SD_CMD | MicroSD |
| 78–84 | SD_DAT0–3 | MicroSD |

### CM4 Decoupling

```
    5V_IN (pins 4,5) ──┬── C1 (100nF) ──┐
                        ├── C2 (100nF) ──┤
                        ├── C3 (100nF) ──┤── GND
                        ├── C4 (100nF) ──┤
                        └── C5 (10µF) ───┘
```

Place all decoupling caps within 5mm of the CM4 connector pins.

### CM4 Boot Configuration

```
    nRPIBOOT (J1 pin 91) ──── 10kΩ pull-up to 3.3V
                               │
                            [Jumper to GND]  ← close to force USB boot (eMMC programming)
                                               leave open for normal SD/eMMC boot
```

### EEPROM (Optional)

For CM4 carrier boards, a small I2C EEPROM (CAT24C32) on GPIO 0/1 can store board identity. This is optional — skip it for prototype.

---

## 2. USB Hub — USB2514B Cascade

Two USB2514B ICs provide 7 downstream ports. IC1 upstream connects to CM4 USB, IC1 port 4 cascades to IC2 upstream.

### Block Diagram

```
    CM4 USB Host (J2 pins 1-2)
         │
         ▼
    ┌──────────┐
    │ USB2514B │ (IC1 — Root Hub)
    │   (U2)   │
    ├──────────┤
    │ Port 1 ──┼──→ J9  (USB-A #1)
    │ Port 2 ──┼──→ J10 (USB-A #2)
    │ Port 3 ──┼──→ J11 (USB-A #3)
    │ Port 4 ──┼──→ [cascade to IC2 upstream]
    └──────────┘
         │ (Port 4)
         ▼
    ┌──────────┐
    │ USB2514B │ (IC2 — Tier 2 Hub)
    │   (U3)   │
    ├──────────┤
    │ Port 1 ──┼──→ J12 (USB-A #4)
    │ Port 2 ──┼──→ J13 (USB-A #5)
    │ Port 3 ──┼──→ J14 (USB-A #6)
    │ Port 4 ──┼──→ J15 (USB-A #7)
    └──────────┘
```

**Total: 7 downstream USB-A ports.** (6 for MIDI devices + 1 spare.) Add J16 as 8th port from CM4's second USB host if needed, or use USB2517 single-chip 7-port alternative.

### USB2514B Circuit (Per IC)

```
                          +3.3V
                            │
                     ┌──────┴──────┐
                     │  USB2514B   │
                     │             │
    USBUP_D- ───────┤ USBDM       │
    USBUP_D+ ───────┤ USBDP       │
                     │             │
                     │ DN1_DM ─────┤──→ Port 1 D-
                     │ DN1_DP ─────┤──→ Port 1 D+
                     │ DN2_DM ─────┤──→ Port 2 D-
                     │ DN2_DP ─────┤──→ Port 2 D+
                     │ DN3_DM ─────┤──→ Port 3 D-
                     │ DN3_DP ─────┤──→ Port 3 D+
                     │ DN4_DM ─────┤──→ Port 4 D-
                     │ DN4_DP ─────┤──→ Port 4 D+
                     │             │
                     │ XTAL1 ──────┤──── Y1 (24 MHz) ──┤
                     │ XTAL2 ──────┤────────────────────┤
                     │             │    C16 (18pF)  C17 (18pF)
                     │             │      │            │
                     │ VBUS_DET ───┤── 5V (via divider) │
                     │ RESET_N ────┤── 10kΩ to 3.3V    GND
                     │ CFG_SEL0 ───┤── GND (pin-strap config)
                     │ CFG_SEL1 ───┤── GND
                     └─────────────┘
                          │
                         GND

    Decoupling per IC:
    VDD33  ── C (100nF) ── GND    (×2, near VDD pins)
    VDDA33 ── C (100nF) ── GND
    CRFILT ── C (10nF)  ── GND    (internal PLL filter)
```

### USB2514B Configuration

Using pin-strap (non-SMBus) mode — CFG_SEL0/1 both tied to GND. Default config:
- All 4 ports enabled
- Self-powered mode
- Gang overcurrent reporting
- No need for EEPROM or SMBus

---

## 3. USB ESD Protection

One USBLC6-2SC6 per USB port, placed close to the connector.

```
    USB-A Connector                  To Hub IC
         │                               │
    D- ──┤──┬── USBLC6 ──┬──────────── D-
    D+ ──┤──┤   (ESD)    ├──────────── D+
         │  │             │
    VBUS ┤  └── GND ──── GND
    GND ─┤
         │
      [Polyfuse F1]── VBUS → hub VBUS_DET / power
```

---

## 4. MIDI OUT Circuits (×4)

Identical to v1 design. Pi UART TX → 220Ω active-drive → DIN-5 connector. No optocoupler on output side (only receiving devices have optocouplers).

### Single MIDI OUT Port

```
              +5V Rail
                │
              [R_src] 220Ω (e.g., R8)
                │
           DIN-5 Pin 4 (Source) ────────┐
                                        │
                                   [MIDI Cable]
                                   [to receiver]
                                   [optocoupler]
                                        │
           DIN-5 Pin 5 (Sink) ──────────┘
                │
              [R_snk] 220Ω (e.g., R9)
                │
           CM4 GPIO TX (3.3V logic)
           (e.g., GPIO 14 for UART0)

    DIN-5 Pin 2 ── GND (cable shield, optional)
    DIN-5 Pin 1, 3 ── NC (not connected)
```

### All 4 Ports Wiring

```
    +5V ──┬── R8  (220Ω) ── J5 Pin 4 ──┐    J5 Pin 5 ── R9  (220Ω) ── GPIO 14 (UART0)
          │                              │
          ├── R10 (220Ω) ── J6 Pin 4 ──┐│    J6 Pin 5 ── R11 (220Ω) ── GPIO 4  (UART3)
          │                              ││
          ├── R12 (220Ω) ── J7 Pin 4 ──┐││   J7 Pin 5 ── R13 (220Ω) ── GPIO 8  (UART4)
          │                              │││
          └── R14 (220Ω) ── J8 Pin 4 ──┐│││  J8 Pin 5 ── R15 (220Ω) ── GPIO 12 (UART5)
                                        ││││
                               (to external receivers via MIDI cables)
```

### MIDI TX Activity LEDs (Optional)

```
    GPIO TX ──→ R_snk (220Ω) ──→ DIN Pin 5
                  │
                  ├──→ R16 (1kΩ) ──→ LED (yellow) ──→ GND
                  │
    (LED lights when TX is LOW = transmitting data)
```

Note: LED taps off the TX line. When TX goes LOW (sending MIDI byte), current flows through both the MIDI port AND the LED. The 1kΩ limits LED current to ~3mA — dim but visible. This is a quick-and-dirty indicator; for brighter LEDs, use a transistor buffer off a spare GPIO.

---

## 5. DSI Display Passthrough

Straight passthrough from CM4 DSI pins to a 15-pin FPC connector (J17). No active components needed.

```
    CM4 J2 DSI pins ──── [traces, controlled impedance] ──── J17 (15-pin FPC)
                                                                │
                                                           [FPC ribbon cable]
                                                                │
                                                          5" DSI Touchscreen
```

DSI differential pairs need 100Ω impedance matching. Keep traces short and equal length (within 0.5mm per pair). See [pcb-spec.md](pcb-spec.md) for layout rules.

---

## 6. MicroSD Card Slot

CM4 Lite has no eMMC — boots from MicroSD. Direct connection to CM4 SD interface pins.

```
    CM4 J2 ──── SD_CLK  ──── J18 (MicroSD) CLK
                SD_CMD  ──── J18 CMD
                SD_DAT0 ──── J18 DAT0
                SD_DAT1 ──── J18 DAT1
                SD_DAT2 ──── J18 DAT2
                SD_DAT3 ──── J18 DAT3
                             J18 VDD ── 3.3V
                             J18 VSS ── GND

    Decoupling: 100nF + 10µF near J18 VDD pin
```

---

## 7. Net Names Reference

For use when drawing the KiCad schematic:

| Net Name | Description |
|---|---|
| `VBUS_5V` | USB-C PD input, main 5V rail |
| `V3V3` | 3.3V regulated rail (from LDO) |
| `USB_UP_DP`, `USB_UP_DM` | CM4 → Hub IC1 upstream |
| `USB_GAD_DP`, `USB_GAD_DM` | CM4 USB OTG → DAW USB-C |
| `HUB1_DN1_DP` ... `HUB1_DN4_DP` | Hub IC1 downstream ports |
| `HUB2_DN1_DP` ... `HUB2_DN4_DP` | Hub IC2 downstream ports |
| `MIDI_TX0` | GPIO 14 → MIDI OUT J5 |
| `MIDI_TX1` | GPIO 4 → MIDI OUT J6 |
| `MIDI_TX2` | GPIO 8 → MIDI OUT J7 |
| `MIDI_TX3` | GPIO 12 → MIDI OUT J8 |
| `DSI_CLK_P/N`, `DSI_D0_P/N` ... | DSI differential pairs |
| `SD_CLK`, `SD_CMD`, `SD_DAT0-3` | MicroSD interface |

---

## KiCad Hierarchical Sheet Organization

```
midi-box-v2.kicad_sch (root)
    ├── power.kicad_sch        — USB-C PD, LDO, bulk caps, polyfuses
    ├── cm4.kicad_sch          — CM4 connectors, decoupling, boot config, SD slot
    ├── usb_hub.kicad_sch      — USB2514B ×2, crystals, cascade wiring
    ├── usb_ports.kicad_sch    — 8× USB-A connectors, ESD, polyfuses
    ├── midi_out.kicad_sch     — 4× UART → resistor → DIN-5
    └── connectors.kicad_sch   — DSI FPC, fan headers, LEDs, mounting holes
```

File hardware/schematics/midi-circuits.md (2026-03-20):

# MIDI I/O Circuit Schematics

## MIDI Electrical Specification

- MIDI uses **31250 baud** serial, 8-N-1
- Current loop: 5mA through optocoupler in receiving device
- All 4 DIN ports are **MIDI OUT only** — no MIDI IN circuits needed
- Pi native hardware UARTs drive the circuits directly (no SC16IS752 bridge chips)

---

## MIDI OUT Circuit (Active Drive)

One circuit per port × 4. Pi GPIO TX pin drives it directly at 3.3V logic — no level shifter needed.

```
    Schematic (one per port):

         +5V Rail                          Pi UART TX
            │                              (GPIO, 3.3V logic)
           [R1]  220Ω                          │
            │                                 [R2]  220Ω
            │                                  │
        DIN-5 Pin 4 (Source)            DIN-5 Pin 5 (Sink)
            │                                  │
            │          ┌──────────────┐        │
            └──────────┤  MIDI Cable  ├────────┘
                       │ (to receiver │
                       │ optocoupler) │
                       └──────────────┘

    DIN-5 Pin 2 ─── Shield / Ground (optional, cable shield)
    DIN-5 Pin 1, 3 ─── Not connected
```

```
    Current flow when transmitting (TX = LOW):

    +5V ──→ R1 (220Ω) ──→ Pin 4 ──→ [receiver optocoupler] ──→ Pin 5 ──→ R2 (220Ω) ──→ TX (LOW = GND)

    Loop current: (5V - ~1.2V opto drop) / (220Ω + 220Ω) ≈ 8.6 mA — within MIDI spec
```

### How it works

| TX State | What happens |
|---|---|
| **HIGH** (idle, 3.3V) | No significant voltage difference across the loop — no current flows |
| **LOW** (data, ~0V) | TX pin sinks to GND → current flows through the loop → optocoupler activates |

### 3.3V GPIO note

Pi GPIO outputs 3.3V when HIGH. Since current only flows when TX is LOW (sinking to GND), the 3.3V idle level doesn't affect MIDI signal integrity. The driving force is always the +5V rail, not the GPIO output voltage.

---

## Pi UART → MIDI OUT Wiring

```
                        ┌─────────────────────┐
                        │    Raspberry Pi 4   │
                        │                     │
                        │ GPIO 14 (UART0 TX) ─┼──── MIDI OUT → MS-20 Mini
                        │ GPIO 4  (UART3 TX) ─┼──── MIDI OUT → Volca #1
                        │ GPIO 8  (UART4 TX) ─┼──── MIDI OUT → Volca #2
                        │ GPIO 12 (UART5 TX) ─┼──── MIDI OUT → Volca #3
                        │                     │
                        │ GPIO 2/4 (5V) ──────┼──── Buck converter 5V in
                        │ GPIO 6   (GND) ─────┼──── Buck converter GND
                        │                     │
                        │ DSI connector ──────┼──── 5" Touchscreen (display + touch)
                        └─────────────────────┘
```

Required in `/boot/firmware/config.txt`:
```
dtoverlay=disable-bt    # frees UART0 (GPIO 14) from Bluetooth
dtoverlay=uart3         # GPIO 4  TX
dtoverlay=uart4         # GPIO 8  TX
dtoverlay=uart5         # GPIO 12 TX
```

Device nodes (pyserial):
```
/dev/ttyAMA0  →  MS-20 Mini   (UART0, GPIO 14)
/dev/ttyAMA2  →  Volca #1     (UART3, GPIO 4)
/dev/ttyAMA3  →  Volca #2     (UART4, GPIO 8)
/dev/ttyAMA4  →  Volca #3     (UART5, GPIO 12)
```

---

## MIDI OUT Circuit × 4 — Perfboard Layout

```
    ┌──────────────────────────────────────────┐
    │  [Pi Header]                             │
    │                                          │
    │  ┌─────┐  ┌─────┐  ┌─────┐  ┌─────┐   │
    │  │DIN 1│  │DIN 2│  │DIN 3│  │DIN 4│   │
    │  │OUT  │  │OUT  │  │OUT  │  │OUT  │   │
    │  └─────┘  └─────┘  └─────┘  └─────┘   │
    │  MS-20    Volca1   Volca2   Volca3     │
    │                                          │
    │  [220Ω]×8    [+5V rail]   [GND rail]   │
    └──────────────────────────────────────────┘
```

---

## Power Distribution on MIDI Board

```
    5V Input (from Pi GPIO 5V pin or buck converter) ──── MIDI OUT circuits (220Ω drivers)
```

No 3.3V regulator needed — the Pi GPIO TX pins are the only 3.3V logic, and they connect directly.
No optocouplers, no crystal oscillators, no I2C UART bridge chips.

---

## Cooling Fans

2× MakerHawk 5V DC brushless fans wired directly to the 5V rail — always-on, no GPIO control needed.

```
    +5V Rail ──→ Fan + (red wire)
    GND Rail ──→ Fan - (black wire)
```

No MOSFETs, no GPIO pins used. Fans run whenever the box is powered.

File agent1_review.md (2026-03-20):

# MIDI Box Code Review — Agent 1

Review of all 20 Python files in `software/src/`. Organized by severity.

---

## BUGS

### 1. ClipLauncher double-sends MIDI clock — duplicate 0xF8 to all outputs

**File:** `software/src/clip_launcher.py:166`

`_on_clock_tick` sends MIDI clock via `_emit_midi_clock()` when source is internal. But `ClockManager._advance_tick()` already calls `_midi_clock_callback` (which is `_send_clock_to_outputs`) at the same 4-tick interval. Every internal tick produces **two** 0xF8 messages to every output device — double-clocking all connected synths.

```python
# clip_launcher.py:166 — this block should be removed entirely
if cm_source == "internal" and tick % CLOCK_EMIT_INTERVAL == 0:
    self._emit_midi_clock()  # DUPLICATE — ClockManager already does this
```

**Fix:** Delete lines 163-167 in `clip_launcher.py`. ClockManager already handles clock output. Also remove the now-dead `_emit_midi_clock` method (lines 193-202) and the `_output_devices_callback` field.

---

### 2. MidiFilter inconsistency: `"transport"` not in documented `message_types` spec

**File:** `software/src/midi_filter.py:69`

Transport messages (start/stop/continue) are filtered by checking `"transport" not in self.message_types`, but CLAUDE.md documents the valid message_types as `"start"`, `"stop"`, `"continue"` (individually). If a user sets `message_types: ["start"]`, this code blocks it because `"transport"` is not in the list — there's no way to allow just `start` without also allowing `stop` and `continue`.

```python
# midi_filter.py:69 — checks for undocumented "transport" category
if self.message_types and "transport" not in self.message_types:
    return None
```

**Fix:** Check individual types instead:

```python
if self.message_types and message.type not in self.message_types:
    return None
```

---

### 3. Router `_record_activity` is not thread-safe — dict mutation from multiple threads

**File:** `software/src/router.py:196-200`

`_record_activity` does a check-then-set on `self._activity` without locking. Called from rtmidi's callback thread (USB MIDI), hw_midi read thread, and the main loop (gadget). Two threads could both see the key missing and create duplicate `PortActivity` objects, losing counts.

```python
def _record_activity(self, port_name: str, msg_type: str, is_input: bool):
    key = f"{'in' if is_input else 'out'}:{port_name}"
    if key not in self._activity:       # Thread A reads: not present
        self._activity[key] = PortActivity()  # Thread B also writes here
    self._activity[key].record(msg_type)
```

**Fix:** Use `defaultdict(PortActivity)` or pre-initialize entries under lock:

```python
from collections import defaultdict

# In __init__:
self._activity: dict[str, PortActivity] = defaultdict(PortActivity)

# Then _record_activity simplifies to:
def _record_activity(self, port_name: str, msg_type: str, is_input: bool):
    key = f"{'in' if is_input else 'out'}:{port_name}"
    self._activity[key].record(msg_type)
```

---

### 4. Looper `stop_recording` during overdub doesn't check `overdubbing` state for unsubscribe

**File:** `software/src/midi_looper.py:322-323`

When `stop_recording` is called for a `recording` slot, the code checks if any other slots still need the clock subscription. But it only checks for `("count_in", "recording")`, not `"overdubbing"`. If slot 0 is overdubbing and slot 1 finishes recording, the clock subscription gets removed — slot 0's overdub loses tick updates.

```python
# midi_looper.py:322
if not any(s.state in ("count_in", "recording") for s in self.slots):
    self._unsubscribe_from_clock()
# Missing: "overdubbing" — if another slot is overdubbing, it needs ticks too
```

**Fix:** Include `"overdubbing"` in the state check:

```python
if not any(s.state in ("count_in", "recording", "overdubbing") for s in self.slots):
    self._unsubscribe_from_clock()
```

---

### 5. Flask API endpoints crash on missing JSON keys

**File:** `software/src/ui_web.py:274-275`, `software/src/ui_web.py:283-285`

Several POST endpoints access `data["from"]` and `data["to"]` without `.get()`. If `request.json` is missing these keys, Flask returns an unhandled 500 error instead of a clean 400.

```python
# ui_web.py:274 — KeyError if "from" missing
result = _cmd("route.add", {
    "from": data["from"],  # KeyError crash
    "to": data["to"],      # KeyError crash
```

**Fix:** Add validation:

```python
@app.route("/api/routes", methods=["POST"])
def api_routes_add():
    data = request.json
    if not data or "from" not in data or "to" not in data:
        return jsonify({"ok": False, "error": "missing 'from' and 'to' fields"}), 400
    result = _cmd("route.add", {
        "from": data["from"],
        "to": data["to"],
        "filter": data.get("filter", {}),
        "name": data.get("name", ""),
    })
    return jsonify({"ok": result.get("ok", False), "route": result.get("route", "")})
```

Apply the same pattern to `api_routes_remove` and `api_routes_toggle`.

---

## RISKS

### 6. IPC shared state read-modify-write race on `wifi_config`

**File:** `software/src/ui_web.py:158-161`

The network update endpoint reads the shared state dict, modifies the copy, and writes it back. If two requests arrive concurrently (or the engine writes `wifi_config` at the same time), one update is silently lost. The multiprocessing Manager dict is not atomic for read-modify-write.

```python
wifi = dict(bridge.state.get("wifi_config", {}))  # read
wifi["ssid"] = ssid                                # modify
bridge.state["wifi_config"] = wifi                  # write (not atomic)
```

**Impact:** Low — WiFi config changes are rare and single-user. But technically a race.

**Fix:** Route WiFi config changes through the IPC command queue like other mutations, so the engine process handles them atomically.

---

### 7. `_update_shared_state` parses MIDI files from disk 10x/sec — IPC bottleneck

**File:** `software/src/main.py:1105`, `software/src/main.py:1112`

Every 100ms, the engine serializes all devices, routes, launcher status, player file list, looper status, etc. into the Manager dict. The `list_files()` calls in particular do `mido.MidiFile(str(f))` for every `.mid` file on disk — on each state push.

```python
# main.py:1105 — parses every MIDI file on disk, 10x/sec
status["files"] = self.launcher.list_files()  # opens and parses all .mid files
# main.py:1112 — same for player
"files": self.player.list_files(),
```

**Fix:** Cache file listings and only refresh when files change (upload/delete/rename):

```python
# In ClipLauncher and MidiPlayer, add:
self._files_cache = None
self._files_dirty = True

def invalidate_file_cache(self):
    self._files_dirty = True

def list_files(self, ...):
    if self._files_dirty or self._files_cache is None:
        self._files_cache = self._scan_files(...)
        self._files_dirty = False
    return self._files_cache
```

Call `invalidate_file_cache()` after upload/delete/rename operations.

---

### 8. Recorder count-in race: state set to `"recording"` from background thread without lock

**File:** `software/src/quick_recorder.py:248`

`_count_in_worker` runs in a background thread and sets `self._state = "recording"` without holding `self._lock`. Meanwhile, `toggle()` checks `self._state` without a lock too. If the user presses Record exactly as the count-in completes, both paths could execute simultaneously.

```python
# quick_recorder.py:248 — no lock
self._state = "recording"
self._record_start = time.monotonic()
```

**Impact:** Could result in a double-start or recording starting with stale `_record_start`. The timing window is narrow but real with a foot pedal.

**Fix:** Guard state transitions with `self._lock`:

```python
def _count_in_worker(self) -> None:
    triggered = self._count_in_event.wait(timeout=30.0)
    with self._lock:
        if not triggered or self._state != "count_in":
            if self._state == "count_in":
                self._state = "idle"
            return
        self._state = "recording"
        self._record_start = time.monotonic()
        self._record_start_tick = self._tick
```

---

### 9. Player `_play_loop` doesn't respect `_paused` during `time.sleep` for message timing

**File:** `software/src/midi_player.py:402-403`

When `time.sleep(msg.time / self._tempo_factor)` is sleeping for a long gap between messages (common in MIDI files with rests), `pause()` won't take effect until the sleep finishes. For a whole-note rest at 60 BPM, that's a 4-second delay before pause responds.

```python
# midi_player.py:402 — non-interruptible sleep
if msg.time > 0:
    time.sleep(msg.time / self._tempo_factor)  # blocks pause for duration
```

**Fix:** Use a `threading.Event` for stop/pause and `.wait()` instead of `sleep()` — same pattern used by the looper and recorder:

```python
# In __init__:
self._stop_event = threading.Event()

# In _play_loop:
if msg.time > 0:
    delay = msg.time / self._tempo_factor
    if self._stop_event.wait(delay):
        return  # stopped

# Handle pause separately with a tighter loop:
while self._paused and self._running:
    if self._stop_event.wait(0.05):
        return

# In stop():
self._stop_event.set()
```

---

### 10. Hotplug monitor `known_ports` can go stale if `rescan()` is called concurrently

**File:** `software/src/alsa_midi.py:188-223`

`_hotplug_loop` reads `known_ports` from `self.ports` under lock initially, but then the variable is updated without synchronization. If `rescan()` is called from another thread (via the `device.rescan` IPC command), `known_ports` could become stale and trigger false connect/disconnect events.

**Fix:** Re-read `self.ports` under lock at the top of each hotplug iteration instead of relying on the local `known_ports` variable:

```python
while self._running:
    try:
        with self._lock:
            known_ports = set(self.ports.keys())
        current_ports = set(self.scan_devices())
        # ... rest of detection logic
```

---

### 11. `SECRET_KEY` is hardcoded

**File:** `software/src/ui_web.py:67`

```python
app.config["SECRET_KEY"] = "midi-box-dev"
```

Flask uses this for session signing. Since there are no user sessions or CSRF tokens in this app, impact is nil — but if Flask sessions are ever added, this is an immediate vulnerability.

**Fix:** Generate a random key at startup:

```python
import os
app.config["SECRET_KEY"] = os.urandom(24).hex()
```

---

## IMPROVEMENTS

### 12. Bare `except: pass` silently swallows errors in ClockManager tick subscribers

**File:** `software/src/clock_manager.py:347-348`

```python
for sub in list(self._tick_subs):
    try:
        sub(tick, beat, bar, True)
    except Exception:
        pass  # a crashing subscriber is silently ignored forever
```

Same pattern at lines 112-114, 241-243, 341-342. If a subscriber throws repeatedly, there's no log, no error count, nothing.

**Fix:** Log at DEBUG level at minimum:

```python
except Exception as e:
    logger.debug("Tick subscriber error: %s", e)
```

---

### 13. State is saved to disk on every single route/preset/config change

**File:** `software/src/state.py:105-109`

Every `set_preset()`, `set_routes()`, `set_clock()`, `set_device_override()`, `set_launcher_state()`, etc. calls `self.save()` immediately. During startup restore or bulk operations, this can write the state file dozens of times in rapid succession. Each save also copies the current file to a backup first.

**Fix:** Add a dirty flag and debounce saves:

```python
import threading

class StateManager:
    def __init__(self, ...):
        ...
        self._save_timer = None
        self._save_lock = threading.Lock()

    def _schedule_save(self, delay=1.0):
        """Debounce saves — write at most once per second."""
        with self._save_lock:
            if self._save_timer:
                self._save_timer.cancel()
            self._save_timer = threading.Timer(delay, self.save)
            self._save_timer.daemon = True
            self._save_timer.start()

    def set_routes(self, routes):
        self.state["routes"] = routes
        self._schedule_save()

    # ... same for other setters
```

Keep the explicit `save()` call in `_save_state()` (shutdown) to flush immediately.

---

### 14. `updater._detect_update_type` runs `git show` on tags that may not be fetched locally

**File:** `software/src/updater.py:109-114`

`git show {latest_tag}:scripts/pi_setup.sh` will fail if the tag hasn't been fetched yet (only `ls-remote` was called, not `fetch`). The function falls back to `"simple"`, which is safe, but the detection is basically always wrong for new remote tags.

**Fix:** Run `git fetch --tags origin` before the `git show` comparison, or use `git diff` against the remote ref directly:

```python
subprocess.run(
    ["git", "fetch", "--tags", "origin"],
    capture_output=True, timeout=30, cwd=str(_REPO_ROOT),
)
```

---

### 15. Dead `_emit_midi_clock` method in ClipLauncher (related to Bug #1)

**File:** `software/src/clip_launcher.py:193-202`

`_emit_midi_clock` and `_output_devices_callback` are dead code once Bug #1 is fixed. ClockManager handles all clock output. These can be removed along with the duplicate clock emission.

**Fix:** After fixing Bug #1, delete:
- `_emit_midi_clock` method (lines 193-202)
- `self._output_devices_callback` field (line 73)
- The assignment in `main.py:146`: `self.launcher._output_devices_callback = self._get_output_device_names`

---

### 16. Recorder `_to_midi_file` uses hardcoded 120 BPM tempo instead of actual recording BPM

**File:** `software/src/quick_recorder.py:459`

```python
track.append(mido.MetaMessage("set_tempo", tempo=DEFAULT_TEMPO, time=0))
# DEFAULT_TEMPO = 500_000 = 120 BPM, regardless of actual ClockManager BPM
```

The saved `.mid` file always claims 120 BPM regardless of the actual tempo during recording. Since the recorder stores real-time offsets (seconds) and converts to ticks using 120 BPM math, the timing is preserved — but the tempo metadata in the file is wrong, which affects how other DAWs display the file.

**Fix:** Use the actual BPM from ClockManager:

```python
def _to_midi_file(self, events: list) -> mido.MidiFile:
    bpm = self._clock_manager.bpm if self._clock_manager else 120.0
    tempo = int(60_000_000 / bpm)  # microseconds per beat
    mid = mido.MidiFile(type=0, ticks_per_beat=TICKS_PER_BEAT)
    track = mido.MidiTrack()
    mid.tracks.append(track)
    track.append(mido.MetaMessage("set_tempo", tempo=tempo, time=0))
    # ... also update tick conversion to use actual tempo:
    ticks = int(offset_sec * TICKS_PER_BEAT * 1_000_000 / tempo)
```

---

## Priority Summary

| # | Severity | Issue | Impact |
|---|---|---|---|
| 1 | **BUG** | Double clock output | All synths receive 2x tempo |
| 2 | **BUG** | Filter transport mismatch | Filtering doesn't work as documented |
| 5 | **BUG** | Flask KeyError crashes | API returns 500 on bad input |
| 3 | **BUG** | Activity tracking race | Lost message counts (cosmetic) |
| 4 | **BUG** | Looper unsubscribe miss | Overdub loses ticks if another slot stops |
| 7 | **RISK** | File parsing 10x/sec | Unnecessary CPU/disk I/O |
| 9 | **RISK** | Player pause latency | Pause unresponsive for seconds |
| 8 | **RISK** | Recorder state race | Double-start on fast pedal press |
| 13 | **IMPROVE** | Excessive disk writes | State file written dozens of times on changes |
| 12 | **IMPROVE** | Silent subscriber errors | Bugs hidden by bare except:pass |

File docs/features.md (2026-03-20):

# Feature Backlog

## Planned — Next Version

### Analog Sync Output (3.5mm Clock Out)

**Why:** Korg Volcas, Pocket Operators, and other analog gear sync via pulse signals on 3.5mm jacks, not MIDI clock. Currently requires daisy-chaining from KeyStep sync out.

**What:**
- Generate analog sync pulses from a Pi GPIO pin
- Pulse rate derived from ClockManager BPM (1 pulse per step, configurable PPQ)
- 3.3V GPIO → 5V level shifter → 3.5mm mono jack
- Sync start/stop follows transport state
- Configurable in web UI (enable/disable, PPQ: 1, 2, 4, 24)

**Hardware:** 1x GPIO pin, 1x 3.3V→5V level shifter (or transistor), 1x 3.5mm mono jack on enclosure

---

### Analog Sync Input (3.5mm Clock In)

**Why:** Accept clock from Eurorack modular systems, drum machines, or other analog gear that output pulse-based sync signals.

**What:**
- Read analog sync pulses on a Pi GPIO pin (interrupt-driven)
- Detect BPM from pulse interval
- Register as a clock source in ClockManager (like external MIDI clock devices)
- 5V→3.3V voltage divider or level shifter for GPIO protection
- Selectable as clock source in web UI alongside MIDI devices and internal

**Hardware:** 1x GPIO pin (input), voltage divider (2 resistors) or level shifter, 1x 3.5mm mono jack on enclosure

---

## Ideas / Future

- CV/Gate output for Eurorack (would need DAC or PWM + filter)
- Multiple sync out jacks (independent rates per jack)
- DIN sync (older Roland/Korg standard) via same 3.5mm jacks
- PWM fan speed control via GPIO 18/13 + MOSFET (fans currently always-on; could ramp speed based on CPU temp)

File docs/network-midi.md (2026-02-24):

# Network MIDI (RTP-MIDI) — MIDI Box Guide

## What Is Network MIDI?

RTP-MIDI (also called Apple MIDI or Network MIDI) lets you send and receive MIDI over a standard WiFi or Ethernet network using UDP. The MIDI Box Pi appears as a MIDI device on your local network — no USB cable needed.

**Protocol:** RFC 6295 over UDP ports 5004 and 5005
**Discovery:** Bonjour/mDNS (automatic) or manual IP entry
**Latency:** Typically 1–5 ms on a local WiFi network

---

## What MIDI Data Can Be Sent?

Everything in MIDI 1.0:

| Category | Messages |
|---|---|
| Notes | Note On, Note Off, Aftertouch (poly & channel) |
| Controllers | Control Change (CC 0–127), Pitch Bend |
| Program | Program Change, Bank Select |
| System | SysEx, Clock (0xF8), Start/Stop/Continue |
| Sync | MIDI Beat Clock (full transport sync) |

The MIDI Box routes all of this bidirectionally — what comes in via Network MIDI goes through the normal routing table to your hardware synths, and vice versa.

---

## Platform Setup

### macOS

1. Open **Audio MIDI Setup** (`/Applications/Utilities/Audio MIDI Setup.app`)
2. Go to **Window → MIDI Studio** (or press Cmd+2)
3. Double-click the **Network** icon
4. Under "My Sessions", click **+** to create a session (or use the existing one)
5. Under "Directory", you should see **MIDI Box** appear automatically via Bonjour
6. Select it and click **Connect**

The MIDI Box now appears as a MIDI device in any macOS app (Logic Pro, Ableton, GarageBand, etc.).

> **If MIDI Box does not appear automatically:** Click **+** under Directory, enter the Pi's IP address (shown in the Settings page) and port 5004.

> **Bonjour requirement:** Install `zeroconf` on the Pi (`pip install zeroconf`) for automatic discovery. Without it you must add the IP manually.

### iOS / iPadOS

1. Install a Core MIDI app that supports Network MIDI. Recommended free options:
   - **midimittr** (free, just for connecting)
   - **MIDI Network** (built into some DAW apps like Cubasis)
   - **AUM** — audio mixer with full Core MIDI support
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

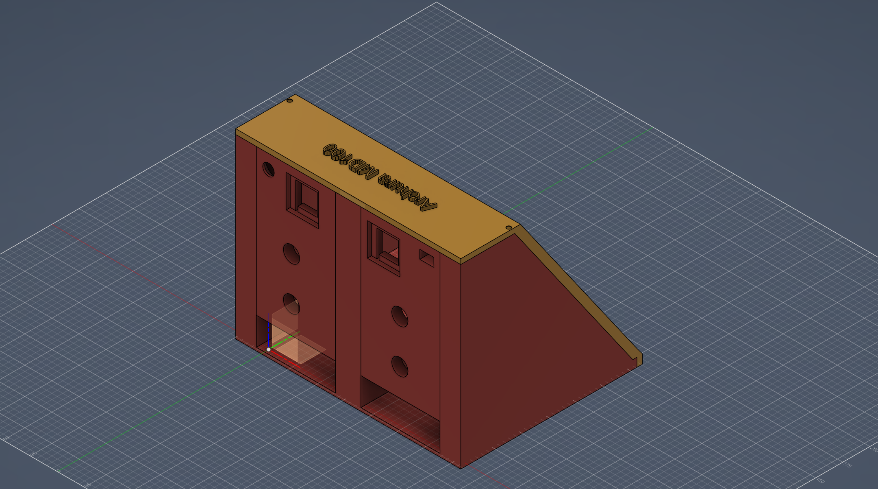
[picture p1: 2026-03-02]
enclosure/midi-box-v1.3 home.png

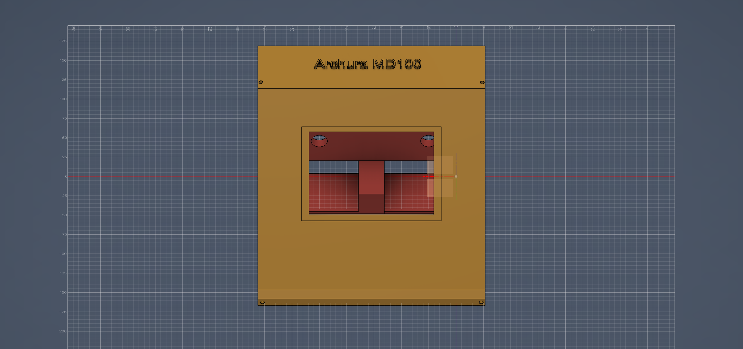
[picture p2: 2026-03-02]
enclosure/midi-box-v1.3 v23 front.png

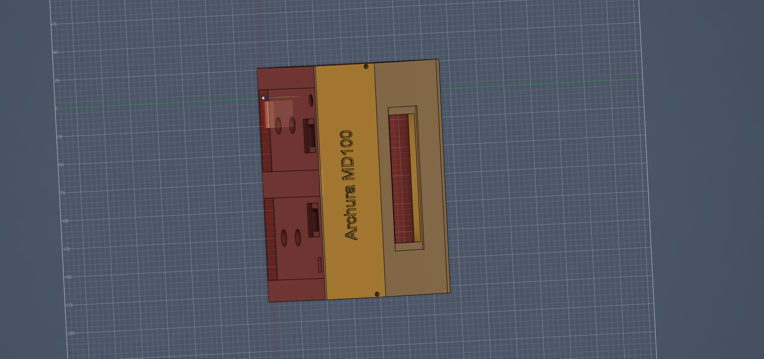
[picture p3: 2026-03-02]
enclosure/midi-box-v1.3 v23 top.png

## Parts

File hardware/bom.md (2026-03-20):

# Bill of Materials

## Core Components

| Component | Qty | Purpose | Notes |
|---|-----|---|---|
| Raspberry Pi 4 Model B (2GB+) | 1 | Main processor / router brain | 4GB recommended for web UI |
| MicroSD Card 16GB+ | 1 | OS + software storage | Class 10 / A1 minimum |
| Waveshare Industrial USB HUB (4× USB 2.0) | 2 | Connect 6 USB MIDI devices (3 per hub) | 5V powered, industrial grade, compact |
| 5V 5A Power Supply (barrel jack) | 1 | Single power input for whole box | 5V directly powers Pi (GPIO pins) + both hubs — no buck converter needed |
| USB-C to USB-A cable | 1 | Connect Pi USB-C to Mac | For DAW mode (gadget mode) — USB-C port dedicated to this |

## Display

| Component | Qty | Purpose | Notes |
|---|-----|---|---|
| 5" DSI Touchscreen 800×480 IPS Capacitive | 1 | Local UI — QR code, routing, launcher | Third-party DSI screen (800×480, 5-point touch). DSI ribbon to Pi. Most work plug-and-play on Pi OS Bookworm; some need a manufacturer-specific dtoverlay — check product wiki. |

## MIDI DIN I/O Components

4× MIDI OUT ports only (MS-20 Mini + 3× Volca). All driven by Pi native hardware UARTs — no external UART bridge chips needed.

| Component | Qty | Purpose | Notes |
|---|-----|---|---|
| 5-Pin DIN Female Connector (PCB mount) | 4 | MIDI OUT ports | One per device (MS-20, Volca ×3) |
| 220 ohm Resistor (1/4W) | 8 | MIDI OUT current drive | 2 per port (active-drive circuit) |

## Cooling

| Component | Qty | Purpose | Notes |
|---|-----|---|---|
| MakerHawk Raspberry Pi DC Brushless Fan (2-pack) | 1 | Enclosure cooling | 5V always-on, wired directly to 5V rail + GND |

## User Interface Components

| Component | Qty | Purpose | Notes |
|---|-----|---|---|
| SPDT Toggle Switch | 1 | Manual mode override | Panel mount |

## Enclosure & Assembly

| Component | Qty | Purpose | Notes |
|---|-----|---|---|
| 3D Printed Enclosure | 1 | Housing | PLA or PETG, custom design |
| M3 Brass Heat-Set Inserts | 12 | Secure panels to enclosure | Press-in with soldering iron |
| M3x8mm Screws | 12 | Panel mounting | |
| M2.5 Standoffs (11mm) | 4 | Mount Pi inside enclosure | |
| M2.5 Screws | 8 | Secure Pi to standoffs | |
| Rubber Feet (adhesive) | 4 | Non-slip base | |

## Cables (Internal)

| Component | Qty | Purpose | Notes |
|---|-----|---|---|
| Dupont Jumper Wires (F-F) | 20 | GPIO connections | 20cm |
| USB-A to USB-A cables | 6 | Connect USB MIDI devices to hubs | Short 30cm cables to save space |
| DSI Ribbon Cable | 1 | Pi → 5" touchscreen | Usually included with screen; verify before ordering |

## Port Allocation Plan

### Pi Native UARTs (MIDI OUT — enabled via device tree overlays)

| UART | GPIO (TX) | Device Node | Assigned To |
|---|---|---|---|
| UART0 | GPIO 14 | /dev/ttyAMA0 | Korg MS-20 Mini |
| UART3 | GPIO 4 | /dev/ttyAMA2 | Korg Volca #1 |
| UART4 | GPIO 8 | /dev/ttyAMA3 | Korg Volca #2 |
| UART5 | GPIO 12 | /dev/ttyAMA4 | Korg Volca #3 |

Required in `/boot/firmware/config.txt`:
```
dtoverlay=disable-bt    # frees UART0 (GPIO 14) from Bluetooth
dtoverlay=uart3         # enables UART3 on GPIO 4/5
dtoverlay=uart4         # enables UART4 on GPIO 8/9
dtoverlay=uart5         # enables UART5 on GPIO 12/13
```

### I2C Bus (GPIO 2/3)

| Device | Address | Purpose |
|---|---|---|
| 5" Touchscreen (touch controller) | 0x38 | Touch input (auto via DSI) |

### Reserved GPIO (other)

| GPIO | Purpose |
|---|---|
| 2 / 3 | I2C SDA / SCL |
| 4 | UART3 TX → Volca #1 |
| 8 | UART4 TX → Volca #2 |
| 12 | UART5 TX → Volca #3 |
| 14 | UART0 TX → MS-20 Mini |

## Power Budget

Single **5V 5A barrel jack** powers everything directly — no buck converter. Pi is powered via GPIO 5V pins (USB-C port kept free for DAW mode / Mac connection).

```
[5V 5A barrel jack]
        │
        ├──→ Raspberry Pi 4 (GPIO 5V pins — USB-C kept free for DAW mode)
        ├──→ Waveshare USB Hub #1 (5V input, 3 MIDI devices)
        └──→ Waveshare USB Hub #2 (5V input, 3 MIDI devices)
```

### 5V Draw

| Component | Current draw | Notes |
|---|---|---|
| Pi 4 + 5" touchscreen | ~2.0A | Pi ~1.7A + screen ~0.3A |
| Waveshare Hub #1 (3 USB MIDI devices) | ~0.6A | MIDI devices ~150–200mA each |
| Waveshare Hub #2 (3 USB MIDI devices) | ~0.6A | MIDI devices ~150–200mA each |
| 2× Cooling fans | ~0.4A | ~0.2A each |
| **Realistic total** | **~3.6A** | |
| **Supply capacity** | **5.0A** | ~1.4A headroom |

> The Waveshare hubs draw their own power from the 5V rail. No charging ports, no idle load — purely USB MIDI instrument connections.

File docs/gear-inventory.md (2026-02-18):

# Gear Inventory & MIDI Capabilities

## 1. Arturia KeyLab 88 MK2

- **Role:** Primary 88-key controller
- **USB MIDI:** Yes (class-compliant)
- **5-Pin MIDI OUT:** Yes
- **5-Pin MIDI IN:** No
- **MIDI Channels:** All (configurable)
- **Features:** Aftertouch, pitch/mod wheels, 9 faders, 9 knobs, 16 pads, DAW integration
- **Connection to MIDI Box:** USB
- **Notes:** Main keyboard controller. Can split zones to send different channels to different synths.

## 2. Arturia KeyStep

- **Role:** Small controller + step sequencer + arpeggiator
- **USB MIDI:** Yes (class-compliant)
- **5-Pin MIDI IN:** Yes
- **5-Pin MIDI OUT:** Yes
- **MIDI Channels:** 1-16 (configurable)
- **Features:** 32-step sequencer, arpeggiator, MIDI/CV/Gate outputs
- **Connection to MIDI Box:** USB
- **Notes:** Great for sequencing the Volcas and MS-20. Can also output CV/Gate directly to MS-20 and Model D (separate from MIDI box).

## 3. Korg MS-20 Mini

- **Role:** Semi-modular analog synth
- **USB MIDI:** No
- **5-Pin MIDI IN:** Yes
- **5-Pin MIDI OUT:** No
- **MIDI Channels:** Receives on 1 channel (configurable via MIDI)
- **Features:** Note on/off, pitch bend. Limited MIDI implementation.
- **Connection to MIDI Box:** 5-Pin DIN OUT from box → MS-20 MIDI IN
- **Notes:** Only responds to note on/off and pitch bend. No CC control via MIDI. Use CV/Gate patch cables for more control.

## 4. Behringer Model D

- **Role:** Mono analog synth (Minimoog clone)
- **USB MIDI:** Yes (class-compliant)
- **5-Pin MIDI IN:** Yes
- **5-Pin MIDI OUT:** No
- **MIDI Channels:** Configurable
- **Features:** Note on/off, pitch bend, some CC (filter cutoff, etc.)
- **Connection to MIDI Box:** USB
- **Notes:** Has both USB and 5-pin MIDI IN. Using USB saves a DIN port on the box. Also has CV/Gate inputs.

## 5. Roland JP-08 (Boutique)

- **Role:** Digital polysynth (Jupiter-8 recreation)
- **USB MIDI:** Yes (class-compliant)
- **5-Pin MIDI IN/OUT:** Yes (via DK-01 dock or breakout cable)
- **MIDI Channels:** Configurable
- **Features:** Full MIDI CC implementation, program change, sysex for patch dumps
- **Connection to MIDI Box:** USB
- **Notes:** Very responsive to CC. Can automate many parameters from DAW or controller.

## 6. Arturia MicroBrute

- **Role:** Mono analog synth with patch bay
- **USB MIDI:** Yes (class-compliant)
- **5-Pin MIDI IN:** Yes
- **5-Pin MIDI OUT:** No
- **MIDI Channels:** Configurable
- **Features:** Note on/off, pitch bend, mod wheel, some CC
- **Connection to MIDI Box:** USB
- **Notes:** Has its own mini patch bay for CV modulation. MIDI is basic but functional.

## 7. Korg Volca (x3)

- **Role:** Compact synths/drum machines
- **USB MIDI:** No
- **5-Pin MIDI IN:** Yes
- **5-Pin MIDI OUT:** No (sync out only on some models)
- **MIDI Channels:** Configurable per unit
- **Features:** Note on/off, some CC (varies by model)
- **Connection to MIDI Box:** 5-Pin DIN OUT from box → each Volca MIDI IN
- **Notes:** Each Volca should be on its own MIDI channel. The sync out can chain Volcas together for tempo sync without using MIDI.

**Recommended channel assignment:**
| Volca | MIDI Channel |
|---|---|
| Volca #1 | Channel 4 |
| Volca #2 | Channel 5 |
| Volca #3 | Channel 6 |

## 8. Roland SP-404 MK2

- **Role:** Sampler / performance tool / effects
- **USB MIDI:** Yes (class-compliant)
- **5-Pin MIDI IN:** Yes
- **5-Pin MIDI OUT:** Yes
- **MIDI Channels:** Configurable
- **Features:** Note on/off (pad triggers), program change, CC, MIDI clock
- **Connection to MIDI Box:** USB
- **Notes:** Can act as both a MIDI controller (pads → trigger synths) and a sound module (receive MIDI to trigger samples). Very versatile in a live setup.

---

## Connection Summary

### Via USB (6 devices)
```
USB Hub Port 1 ← Arturia KeyLab 88 MK2
USB Hub Port 2 ← Arturia KeyStep
USB Hub Port 3 ← Behringer Model D
USB Hub Port 4 ← Roland JP-08
USB Hub Port 5 ← Arturia MicroBrute
USB Hub Port 6 ← Roland SP-404 MK2
```

### Via 5-Pin DIN (4 devices)
```
MIDI Box DIN OUT 1 → Korg MS-20 Mini (MIDI IN)
MIDI Box DIN OUT 2 → Korg Volca #1 (MIDI IN)
MIDI Box DIN OUT 3 → Korg Volca #2 (MIDI IN)
MIDI Box DIN OUT 4 → Korg Volca #3 (MIDI IN)
```

### Spare Ports
```
MIDI Box DIN 5 → Spare (IN/OUT)
MIDI Box DIN 6 → Spare (IN/OUT)
```

---

## Suggested Default MIDI Channel Map

| Channel | Device | Role |
|---|---|---|
| 1 | MS-20 Mini | Lead / bass |
| 2 | Behringer Model D | Bass |
| 3 | Roland JP-08 | Pads / poly |
| 4 | Volca #1 | Depends on model |
| 5 | Volca #2 | Depends on model |
| 6 | Volca #3 | Depends on model |
| 7 | MicroBrute | Lead / acid |
| 10 | SP-404 MK2 | Samples / drums |
| 1-16 | KeyLab 88 MK2 | Controller (sends) |
| 1-16 | KeyStep | Sequencer (sends) |

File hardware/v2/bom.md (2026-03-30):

# MIDI Box v2 — Bill of Materials

All parts selected for JLCPCB SMT assembly availability. LCSC part numbers included where possible. Check stock before ordering — substitute with pin-compatible alternatives if out of stock.

---

## Compute Module

| Ref | Component | Qty | Package | LCSC / Source | Notes |
|-----|---|-----|---|---|---|
| U1 | Raspberry Pi CM4 (2GB+ RAM, WiFi) | 1 | SO-DIMM module | RPi reseller | CM4 Lite (no eMMC) recommended — boots from SD like Pi 4 |
| J1, J2 | Hirose DF40C-100DS-0.4V (CM4 connector) | 2 | SMD 100-pin | C506281 | One per CM4 board-to-board connector (2 needed) |
| C1–C4 | 100nF ceramic capacitor | 4 | 0402 | C1525 | CM4 decoupling (place near connector pins) |
| C5 | 10µF ceramic capacitor | 1 | 0805 | C19702 | CM4 bulk decoupling |

---

## USB Hub (8 Downstream Ports)

Two USB2514B ICs cascaded: IC1 is root hub (1 upstream from CM4 + 3 downstream + 1 to IC2). IC2 provides 4 more downstream. Total = 7 usable ports (expand to 8 with third IC or use USB2517 for 7-port single chip).

**Option A: 2× USB2514B (4-port hub IC) — cascaded**

| Ref | Component | Qty | Package | LCSC / Source | Notes |
|-----|---|-----|---|---|---|
| U2, U3 | USB2514B-I/M2 (Microchip) | 2 | QFN-36 | C136518 | 4-port USB 2.0 hub, cascaded |
| Y1, Y2 | 24 MHz crystal (18pF load) | 2 | 3215 SMD | C32346 | One per hub IC |
| C6–C13 | 100nF ceramic capacitor | 8 | 0402 | C1525 | Decoupling — 4 per hub IC |
| C14, C15 | 10µF ceramic capacitor | 2 | 0805 | C19702 | Bulk cap per hub IC |
| C16, C17 | 18pF ceramic capacitor | 4 | 0402 | C1808 | Crystal load caps (2 per crystal) |
| R1, R2 | 1.5kΩ resistor | 2 | 0402 | C4026 | USB upstream pull-up (1 per hub) |

**Option B: 1× USB2517 (7-port hub IC) — single chip**

| Ref | Component | Qty | Package | LCSC / Source | Notes |
|-----|---|-----|---|---|---|
| U2 | USB2517-JZX (Microchip) | 1 | QFN-48 | C2155909 | 7-port USB 2.0 hub, single IC |
| Y1 | 24 MHz crystal (18pF load) | 1 | 3215 SMD | C32346 | |
| C6–C9 | 100nF ceramic capacitor | 4 | 0402 | C1525 | Decoupling |
| C10 | 10µF ceramic capacitor | 1 | 0805 | C19702 | Bulk cap |
| C11, C12 | 18pF ceramic capacitor | 2 | 0402 | C1808 | Crystal load caps |
| R1 | 1.5kΩ resistor | 1 | 0402 | C4026 | Upstream pull-up |

> **Recommendation:** Option B (USB2517) if you want simplicity. Option A (2× USB2514B) if USB2517 is out of stock or you want 8 ports exactly.

---

## USB ESD Protection

| Ref | Component | Qty | Package | LCSC / Source | Notes |
|-----|---|-----|---|---|---|
| U4–U11 | USBLC6-2SC6 (ST) | 8 | SOT-23-6 | C7519 | One per USB downstream port — protects D+/D- |
| U12 | USBLC6-2SC6 (ST) | 1 | SOT-23-6 | C7519 | USB upstream (CM4 side) |

---

## USB-C Power Delivery (Input)

| Ref | Component | Qty | Package | LCSC / Source | Notes |
|-----|---|-----|---|---|---|
| U13 | STUSB4500QTR (ST) | 1 | QFN-24 | C2678061 | USB-PD sink controller — negotiates 5V/3A from PD source |
| J3 | USB-C 16-pin receptacle (power + CC) | 1 | SMD mid-mount | C2765186 | Power input connector |
| R3, R4 | 5.1kΩ resistor | 2 | 0402 | C25905 | CC1/CC2 pull-down (required for USB-C) |
| R5 | 10kΩ resistor | 1 | 0402 | C25744 | STUSB4500 ADDR pin |
| C18 | 4.7µF ceramic capacitor | 1 | 0805 | C1779 | STUSB4500 VDD decoupling |
| C19 | 100nF ceramic capacitor | 1 | 0402 | C1525 | STUSB4500 decoupling |
| C20 | 100µF electrolytic capacitor | 1 | 8×10mm | C72505 | VBUS bulk cap (input side) |

---

## USB-C DAW Port (CM4 USB Gadget)

| Ref | Component | Qty | Package | LCSC / Source | Notes |
|-----|---|-----|---|---|---|
| J4 | USB-C 16-pin receptacle | 1 | SMD mid-mount | C2765186 | Connects CM4 USB 2.0 OTG to Mac |
| R6, R7 | 5.1kΩ resistor | 2 | 0402 | C25905 | CC1/CC2 pull-down |

---

## MIDI OUT (4× DIN-5 Ports)

Same active-drive circuit as v1 — Pi UART TX pins through 220Ω resistors to DIN-5 connectors. SMD resistors now.

| Ref | Component | Qty | Package | LCSC / Source | Notes |
|-----|---|-----|---|---|---|
| R8–R15 | 220Ω resistor | 8 | 0805 | C17557 | 2 per MIDI port (source + sink drive) |
| J5–J8 | 5-Pin DIN female connector (PCB mount) | 4 | Through-hole | — (Mouser/Digikey) | CUI SDS-50J or equivalent. Not available on LCSC — hand solder |

### MIDI OUT Port Assignments

| Port | UART | CM4 GPIO (TX) | Device |
|---|---|---|---|
| J5 | UART0 | GPIO 14 | Korg MS-20 Mini |
| J6 | UART3 | GPIO 4 | Korg Volca #1 |
| J7 | UART4 | GPIO 8 | Korg Volca #2 |
| J8 | UART5 | GPIO 12 | Korg Volca #3 |

---

## USB Downstream Connectors

| Ref | Component | Qty | Package | LCSC / Source | Notes |
|-----|---|-----|---|---|---|
| J9–J16 | USB-A female connector (single, horizontal) | 8 | Through-hole | C46407 | Standard USB-A receptacle. Through-hole for mechanical strength |

---

## Display & Misc Connectors

| Ref | Component | Qty | Package | LCSC / Source | Notes |
|-----|---|-----|---|---|---|
| J17 | DSI 15-pin FPC connector (1mm pitch) | 1 | SMD | C262652 | 5" touchscreen ribbon passthrough |
| J18 | MicroSD card slot | 1 | SMD push-push | C585350 | CM4 Lite boot media |
| J19 | 2-pin JST-XH header (fan) | 2 | Through-hole | C158012 | 5V fan connectors (always-on) |
| J20 | 2-pin JST-XH header (fan) | — | — | — | (second fan, same part as J19) |

---

## Power Regulation & Distribution

| Ref | Component | Qty | Package | LCSC / Source | Notes |
|-----|---|-----|---|---|---|
| U14 | AP2112K-3.3 (3.3V LDO, 600mA) | 1 | SOT-23-5 | C51118 | 3.3V rail for STUSB4500 + hub IC logic |
| C21 | 10µF ceramic capacitor | 1 | 0805 | C19702 | LDO output cap |
| C22 | 100nF ceramic capacitor | 1 | 0402 | C1525 | LDO input cap |
| F1–F8 | 500mA polyfuse (resettable) | 8 | 1206 | C70069 | Per USB downstream port — overcurrent protection |
| D1 | SS34 Schottky diode (3A, 40V) | 1 | SMA | C8678 | Reverse polarity protection on VBUS |

---

## Status LEDs

| Ref | Component | Qty | Package | LCSC / Source | Notes |
|-----|---|-----|---|---|---|
| LED1 | Green LED (power) | 1 | 0805 | C2297 | Power indicator |
| LED2 | Blue LED (activity) | 1 | 0805 | C72041 | CM4 GPIO-driven activity |
| LED3–LED6 | Yellow LED (MIDI TX) | 4 | 0805 | C2296 | One per MIDI OUT port — optional, GPIO driven |
| R16 | 1kΩ resistor (LED current limit) | 6 | 0402 | C11702 | One per LED (~3mA at 3.3V) |

---

## Passive Totals Summary

| Part | Value | Package | Total Qty |
|---|---|---|---|
| Ceramic capacitor | 100nF | 0402 | ~16 |
| Ceramic capacitor | 10µF | 0805 | ~4 |
| Ceramic capacitor | 18pF | 0402 | 2–4 |
| Ceramic capacitor | 4.7µF | 0805 | 1 |
| Electrolytic capacitor | 100µF | 8×10mm | 1 |
| Resistor | 220Ω | 0805 | 8 |
| Resistor | 1kΩ | 0402 | 6 |
| Resistor | 1.5kΩ | 0402 | 1–2 |
| Resistor | 5.1kΩ | 0402 | 4 |
| Resistor | 10kΩ | 0402 | 1 |

---

## Sourcing Notes

- **SMD parts (resistors, caps, ICs, LEDs):** All from LCSC — JLCPCB's in-house parts supplier. Use "basic parts" where possible (cheaper assembly fee).
- **Through-hole connectors (DIN-5, USB-A):** JLCPCB supports mixed assembly but at extra cost. Consider hand-soldering these — they're easy and there are only 12 connectors.
- **CM4 module:** Buy directly from RPi approved resellers (Pimoroni, The Pi Hut, Adafruit). Not available on LCSC.
- **5" DSI touchscreen:** Same as v1 — separate purchase, connects via FPC ribbon.

---

## Cost Estimate (per unit, prototype qty 5)

| Item | Estimated Cost |
|---|---|
| PCB fabrication (4-layer, 5 pcs) | ~$15 |
| SMT assembly (SMD parts) | ~$30–50 |
| LCSC components (SMD) | ~$15–25 |
| Through-hole connectors (DIN-5, USB-A) | ~$10–15 |
| CM4 module (2GB WiFi) | ~$35–45 |
| USB-C PD charger (5V/3A+) | ~$10–15 |
| **Total per unit** | **~$115–150** |

> v1 cost with Pi 4 + 2× Waveshare hubs + perfboard: ~$140–170. v2 is comparable or cheaper, and far more reliable.

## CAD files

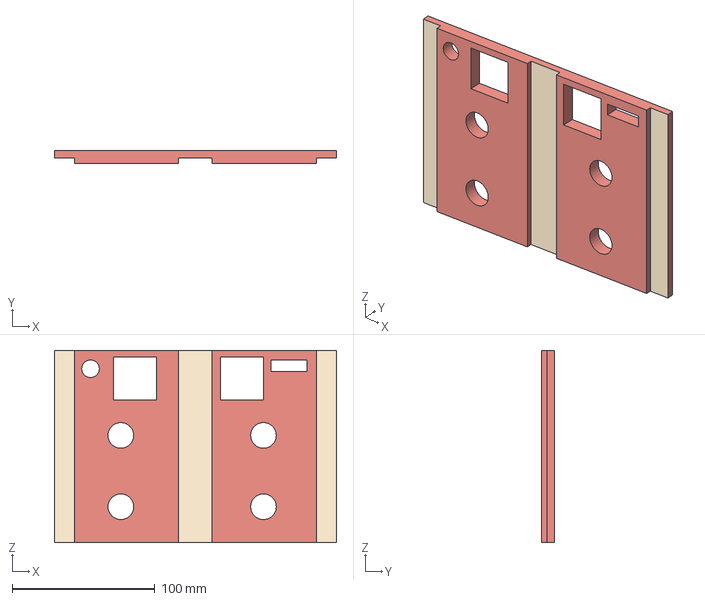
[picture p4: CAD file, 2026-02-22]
enclosure/printer_export/midi-box-v1.3_back.3mf
197.7 x 8.82 x 134.8 mm

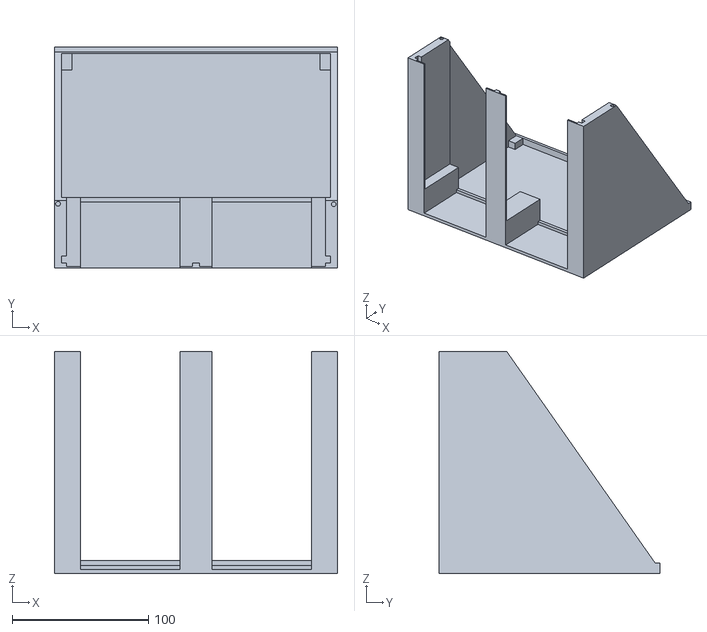
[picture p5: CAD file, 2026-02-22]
enclosure/printer_export/midi-box-v1.3-bottom.stl
207.8 x 162.6 x 163.4

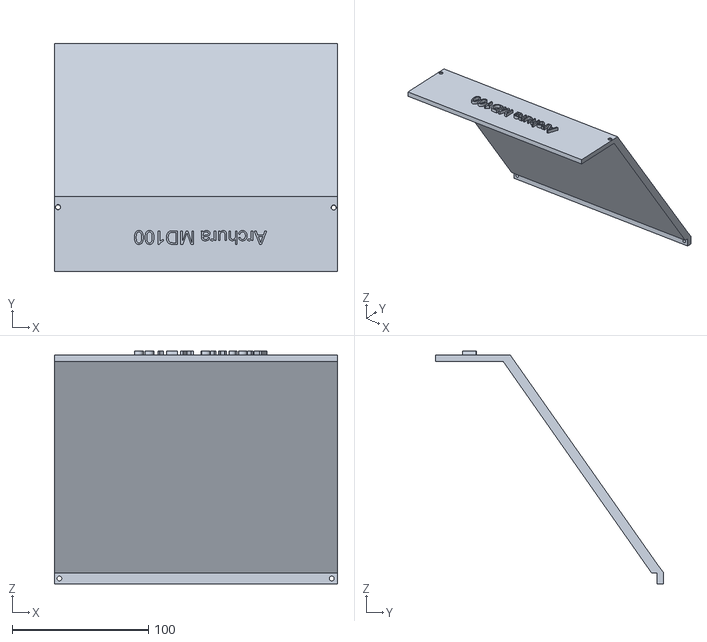
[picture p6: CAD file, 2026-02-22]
enclosure/printer_export/midi-box-v1.3-top.stl
207.8 x 167.6 x 171.0

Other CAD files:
enclosure/midi-box-v1.3.f3d
enclosure/printer_export/midi-box-v1.3-back.stl

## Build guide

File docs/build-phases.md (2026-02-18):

# Build Phases Guide

## Phase 1 — Proof of Concept: USB MIDI Routing on Pi

**Goal:** Get the Pi routing MIDI between USB devices.

**What you need:**
- Raspberry Pi 4 with Raspberry Pi OS Lite installed
- Powered 7-port USB hub
- 2-3 USB MIDI devices to test with (e.g., KeyLab + Model D)

**Steps:**

1. Flash Raspberry Pi OS Lite (Bookworm) to MicroSD
2. Boot and configure:
   ```bash
   sudo apt update && sudo apt upgrade -y
   sudo apt install -y python3-pip python3-venv git alsa-utils
   ```
3. Connect USB hub and plug in a couple MIDI devices
4. Verify devices are seen:
   ```bash
   aconnect -l          # List ALSA MIDI ports
   amidi -l             # List raw MIDI ports
   ```
5. Test basic routing with aconnect:
   ```bash
   # Connect KeyLab output to Model D input
   aconnect 20:0 24:0
   ```
6. Play notes on KeyLab — Model D should respond
7. Install Python environment:
   ```bash
   python3 -m venv /opt/midi-box/venv
   source /opt/midi-box/venv/bin/activate
   pip install mido python-rtmidi
   ```
8. Write a basic Python routing script and test

**Success criteria:** Play KeyLab, hear Model D. Route KeyStep to JP-08. Any USB device to any USB device.

**Estimated time:** 1-2 hours

---

## Phase 2 — USB Gadget Mode: Pi as MIDI Interface for Mac

**Goal:** Mac/Logic Pro sees the Pi as a multi-port MIDI device over USB-C.

**What you need:**
- USB-C cable connecting Pi to Mac

**Power options (choose one):**

- **Option A (try first):** Power from Mac via the same USB-C cable. Works if your USB hub
  is self-powered (has its own wall adapter), since the Pi only draws ~600-800mA by itself.
  If you see a lightning bolt icon or instability, switch to Option B.
- **Option B (most reliable):** Feed 5V to Pi GPIO header pins 2(+) and 6(GND) from a
  separate 5V 3A regulated power supply. No fuse on GPIO — use regulated supply only.

**Steps:**

1. Enable dwc2 overlay:
   ```bash
   # Add to /boot/firmware/config.txt
   dtoverlay=dwc2

   # Add to /etc/modules
   dwc2
   libcomposite
   ```
2. Create the USB gadget setup script:
   ```bash
   #!/bin/bash
   # /opt/midi-box/config/gadget_config.sh

   GADGET_DIR=/sys/kernel/config/usb_gadget/midi-box

   mkdir -p $GADGET_DIR
   cd $GADGET_DIR

   # Device descriptor
   echo 0x1d6b > idVendor   # Linux Foundation
   echo 0x0104 > idProduct  # Multifunction Composite Gadget
   echo 0x0100 > bcdDevice
   echo 0x0200 > bcdUSB

   mkdir -p strings/0x409
   echo "MIDIBox" > strings/0x409/manufacturer
   echo "MIDI Box Router" > strings/0x409/product
   echo "000001" > strings/0x409/serialnumber

   # MIDI function
   mkdir -p functions/midi.usb0
   echo 10 > functions/midi.usb0/in_ports   # 10 ports TO host (Mac)
   echo 10 > functions/midi.usb0/out_ports  # 10 ports FROM host (Mac)

   # Configuration
   mkdir -p configs/c.1/strings/0x409
   echo "MIDI Config" > configs/c.1/strings/0x409/configuration
   echo 500 > configs/c.1/MaxPower

   ln -s functions/midi.usb0 configs/c.1/

   # Enable
   UDC=$(ls /sys/class/udc | head -1)
   echo $UDC > UDC
   ```
3. Run the script and connect Pi to Mac:
   ```bash
   sudo bash /opt/midi-box/config/gadget_config.sh
   ```
4. On Mac, open Audio MIDI Setup → MIDI Studio
5. You should see "MIDI Box Router" with 10 IN + 10 OUT ports
6. Test in Logic Pro: create a track, select MIDI Box port, verify signal flow

**Important:** Power the Pi via GPIO 5V+GND pins (pins 2+6) using a separate 5V supply. The USB-C port is occupied by the Mac connection.

**Success criteria:** Logic Pro shows 10 MIDI Box ports. Sending MIDI from Logic reaches the Pi.

**Estimated time:** 2-3 hours

---

## Phase 3 — Custom 5-Pin MIDI I/O Board

**Goal:** Build the hardware MIDI board for MS-20 and Volcas.

**What you need:**
- All components from the BOM (SC16IS752, 6N138, DIN connectors, etc.)
- Soldering station, perfboard, wire

**Steps:**

1. Enable SC16IS752 in Pi device tree:
   ```bash
   # Add to /boot/firmware/config.txt
   dtoverlay=sc16is752-i2c,int_pin=24,addr=0x48
   dtoverlay=sc16is752-i2c,int_pin=25,addr=0x49
   ```
2. Verify I2C devices detected:
   ```bash
   sudo i2cdetect -y 1
   # Should show 0x48 and 0x49
   ```
3. Build MIDI OUT circuits first (simpler, no optocoupler):
   - Wire SC16IS752 TX → 220ohm → DIN pin 5
   - Wire +5V → 220ohm → DIN pin 4
4. Test MIDI OUT:
   ```python
   import serial
   ser = serial.Serial('/dev/ttySC0', 31250)
   ser.write(bytes([0x90, 60, 100]))  # Note On, middle C, velocity 100
   ser.write(bytes([0x80, 60, 0]))    # Note Off
   ```
5. Connect to MS-20 Mini and verify it plays
6. Build remaining MIDI OUT ports for Volcas
7. Build MIDI IN circuits (with 6N138 optocouplers) for spare ports
8. Test all ports

**Build order:**
1. Solder SC16IS752 chips and crystal/caps
2. Wire I2C connections to Pi header
3. Build one MIDI OUT circuit, test it
4. Replicate for remaining OUT ports
5. Build MIDI IN circuits for spare ports

**Success criteria:** Send MIDI note from Pi → MS-20 plays. Same for each Volca.

**Estimated time:** 4-6 hours (soldering + testing)

---

## Phase 4 — Routing Engine with Dual Mode

**Goal:** Unified software that handles USB + hardware + gadget routing.

**Steps:**

1. Implement `device_registry.py` — maps USB IDs and serial ports to device names
2. Implement `alsa_midi.py` — enumerate and open USB MIDI ports
3. Implement `hw_midi.py` — open SC16IS752 serial ports at 31250 baud
4. Implement `router.py` — the core routing table
   - Read from all input ports (threaded)
   - Look up route in routing table
   - Forward to destination port(s)
   - Apply filters (channel, message type)
5. Implement `gadget.py` — bridge ALSA gadget ports to routing engine
6. Implement `preset_manager.py` — load JSON presets into routing table
7. Implement `main.py` — detect mode, initialize everything, start routing
8. Test scenarios:
   - Standalone: KeyLab → Model D (USB to USB)
   - Standalone: KeyStep → Volca (USB to 5-pin)
   - DAW mode: Logic → JP-08 (gadget to USB)
   - DAW mode: Logic → MS-20 (gadget to 5-pin)
   - Merge: KeyLab + KeyStep → Model D

**Success criteria:** All routing scenarios work. Preset switching works. Mode detection works.

**Estimated time:** 6-10 hours (coding + testing)

---

## Phase 5 — OLED/Encoder UI + Mode Switching

**Goal:** Standalone control without needing a computer or phone.

**Steps:**

1. Wire OLED (I2C) and rotary encoder (GPIO) to Pi
2. Implement `ui_oled.py`:
   - Boot screen with MIDI Box logo
   - Main screen: current preset name + activity dots
   - Menu: preset list, scroll with encoder, select with push
   - Status: show connected devices, active routes
3. Implement mode indicator LEDs
4. Test: change presets from encoder, see routing change in real-time

**UI Flow:**
```
Boot → [MIDI Box v1.0] → Main Screen
                              │
                         Push encoder
                              │
                         ┌────┴────┐
                         │  Menu   │
                         │         │
                         │ > Presets│ → scroll through presets → push to load
                         │   Devices│ → show connected devices
                         │   Status │ → show active routes + MIDI activity
                         │   Mode   │ → Standalone / DAW toggle
                         │   Info   │ → IP address, version
                         └─────────┘
```

**Estimated time:** 3-4 hours

---

## Phase 6 — 3D Printed Enclosure

**Goal:** Professional-looking box that holds everything.

**Design considerations:**
- Front panel: OLED window, rotary encoder hole, mode switch, activity LEDs
- Rear panel: 12x DIN connector holes (6 IN + 6 OUT), USB hub ports, USB-C (to Mac), power jack
- Internal: Pi mounting posts, MIDI board mounting, USB hub mounting
- Ventilation: slots or holes for airflow
- Size estimate: approximately 250mm x 180mm x 60mm

**Steps:**
1. Measure all components (Pi, USB hub, MIDI board, DIN connectors)
2. Design in Fusion 360, FreeCAD, or TinkerCAD
3. Print test fit pieces first (just corners and connector cutouts)
4. Print full enclosure
5. Install brass heat-set inserts
6. Mount everything, route cables

**Tips:**
- Print DIN connector panel separately — easier to iterate
- Use panel-mount DIN connectors, not PCB-mount (more flexible)
- Label all ports on the enclosure (embossed or printed labels)
- Leave extra space — cables inside take more room than you think

**Estimated time:** 8-12 hours (design + printing + assembly)

---

## Phase 7 — Web UI, Presets & Polish

**Goal:** Easy configuration from any device on the network.

**Steps:**
1. Set up Pi as WiFi access point OR connect to home network
2. Implement Flask web UI:
   - Visual patch matrix (grid: inputs on Y axis, outputs on X axis)
   - Click to create/remove routes
   - Drag to set channel filtering
   - Preset save/load/rename
   - Device status page
3. Create useful default presets:
   - "Live Keys" — KeyLab controls all synths
   - "Sequencer" — KeyStep drives Volcas + MS-20
   - "Recording" — Everything to Logic
   - "SP-404 Live" — SP-404 centered setup
   - "All Through" — Everything connected to everything
4. Final testing and polish
5. Write usage notes for yourself

**Estimated time:** 4-6 hours

---

## Total Estimated Build Time

| Phase | Time |
|---|---|
| Phase 1: USB MIDI PoC | 1-2 hours |
| Phase 2: USB Gadget | 2-3 hours |
| Phase 3: Hardware MIDI Board | 4-6 hours |
| Phase 4: Routing Engine | 6-10 hours |
| Phase 5: OLED/Encoder UI | 3-4 hours |
| Phase 6: Enclosure | 8-12 hours |
| Phase 7: Web UI & Polish | 4-6 hours |
| **Total** | **28-43 hours** |

Spread across weekends, this is a 3-5 weekend project.

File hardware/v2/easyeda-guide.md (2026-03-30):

# MIDI Box v2 — EasyEDA Pro Step-by-Step Build Guide

Complete walkthrough for drawing the schematic and PCB in EasyEDA Pro, using LCSC parts, and ordering from JLCPCB.

---

## 0. Setup

### Create Project

1. Go to **https://pro.easyeda.com** → Sign in (same account as JLCPCB/LCSC)
2. **File → New → Project** → Name: `midi-box-v2`
3. **File → New → Schematic** — this creates your first schematic sheet
4. Right-click the project in the left panel → **New → Schematic** — repeat to create **6 sheets total**:

| Sheet Name | Contents |
|---|---|
| `01_Power` | USB-C PD input, Schottky, LDO, bulk caps |
| `02_CM4` | CM4 connectors, decoupling, boot config, SD slot |
| `03_USB_Hub` | USB2514B ×2, crystals, cascade |
| `04_USB_Ports` | 8× USB-A connectors, ESD, polyfuses |
| `05_MIDI_OUT` | 4× UART → 220Ω → DIN-5 |
| `06_Connectors` | DSI FPC, fan headers, LEDs, mounting holes |

### EasyEDA Pro Settings

- **Design → Design Rules** → set min clearance 0.15mm, min trace 0.15mm
- **Units**: mm
- **Grid**: 0.5mm for placement, 0.25mm for routing

---

## 1. Sheet: 01_Power (USB-C PD + Regulation)

### Step 1.1 — Place USB-C Power Connector (J3)

1. **Place → Component** (or press `P`)
2. In the search bar, type LCSC number: **`C2765186`**
3. Click the part → **Place** → drop it on the sheet
4. Label it `J3` — this is your USB-C PD power input

### Step 1.2 — Place STUSB4500 (U13)

1. Search: **`C2678061`**
2. Place → label `U13`
3. If out of stock: search `STUSB4500` and pick any available QFN-24 variant

### Step 1.3 — Place CC Resistors

1. Search: **`C25905`** (5.1kΩ 0402)
2. Place two copies → label `R3`, `R4`
3. Wire:
   - `R3` → J3 CC1 pin → R3 → GND
   - `R4` → J3 CC2 pin → R4 → GND
   - Also connect CC1/CC2 to STUSB4500 CC1/CC2 pins

### Step 1.4 — Place STUSB4500 Support Components

| Search | Label | Wire to |
|---|---|---|
| `C25744` (10kΩ 0402) | R5 | STUSB4500 ADDR → R5 → GND |
| `C1779` (4.7µF 0805) | C18 | STUSB4500 VDD → C18 → GND |
| `C1525` (100nF 0402) | C19 | STUSB4500 VDD → C19 → GND |

### Step 1.5 — Place Schottky Diode (D1)

1. Search: **`C8678`** (SS34)
2. Place → label `D1`
3. Wire: J3 VBUS → D1 anode → D1 cathode → net `VBUS_5V`

### Step 1.6 — Place Bulk Capacitor

1. Search: **`C72505`** (100µF electrolytic)
2. Place → label `C20`
3. Wire: `VBUS_5V` → C20 + → C20 - → GND

### Step 1.7 — Place 3.3V LDO (U14)

1. Search: **`C51118`** (AP2112K-3.3)
2. Place → label `U14`
3. Wire:
   - VIN → `VBUS_5V`
   - VOUT → net `V3V3`
   - GND → GND
   - EN → VIN (always enabled)

### Step 1.8 — Place LDO Caps

| Search | Label | Wire to |
|---|---|---|
| `C1525` (100nF) | C22 | U14 VIN → C22 → GND |
| `C19702` (10µF) | C21 | U14 VOUT → C21 → GND |

### Step 1.9 — Add Power Flags & Net Labels

1. **Place → Net Label** → type `VBUS_5V` → attach to the 5V rail output
2. **Place → Net Label** → type `V3V3` → attach to LDO output
3. **Place → Power Port** → `GND` on all ground connections
4. Add a **net label** `PD_POWER_OK` on STUSB4500 POWER_OK pin (for optional LED)
5. Add net labels `I2C_SCL` and `I2C_SDA` on STUSB4500 SCL/SDA pins (for NVM programming)

### Wiring Diagram for This Sheet

```
    J3 (USB-C) VBUS ──→ D1 (SS34) ──→ VBUS_5V ──┬── C20 (100µF) ── GND
                                                   ├── C22 (100nF) ── GND
    J3 CC1 ──→ R3 (5.1k) ──→ GND                 │
    J3 CC1 ──→ U13 (STUSB4500) CC1                ├── U14 (AP2112K) VIN
    J3 CC2 ──→ R4 (5.1k) ──→ GND                 │         │
    J3 CC2 ──→ U13 CC2                            │      VOUT ──→ V3V3
                                                   │         │
    U13 VDD ──→ V3V3                               │      C21 (10µF) ── GND
    U13 ADDR ──→ R5 (10k) ──→ GND                 │
    U13 SCL ──→ I2C_SCL                            │
    U13 SDA ──→ I2C_SDA                            │
    U13 VBUS_EN_SNK ──→ VBUS_5V                    │
    U13 POWER_OK ──→ PD_POWER_OK                   │
```

---

## 2. Sheet: 02_CM4 (Compute Module 4 Carrier)

### Step 2.1 — Place CM4 Connectors (J1, J2)

1. Search: **`C506281`** (Hirose DF40C-100DS-0.4V)
2. Place two copies → label `J1`, `J2`

> **Important:** EasyEDA may show this as a generic 100-pin connector. That's fine — you'll assign nets to specific pins. If the exact Hirose part isn't available, search `DF40C-100` or manually create a 2×100-pin symbol.

### Step 2.2 — Wire Power Pins

On J1:
- Pins 4, 5 → net `VBUS_5V` (5V power input to CM4)
- Pins 2, 6, 10, 14, 18, 22 → `GND`

### Step 2.3 — Wire UART (MIDI) Pins

On J1:
- Pin 76 → net label `MIDI_TX0` (GPIO 14, UART0)
- Pin 80 → net label `MIDI_TX1` (GPIO 4, UART3)
- Pin 82 → net label `MIDI_TX2` (GPIO 8, UART4)
- Pin 84 → net label `MIDI_TX3` (GPIO 12, UART5)

### Step 2.4 — Wire USB Pins

On J2:
- Pins 1, 2 → net labels `USB_UP_DM`, `USB_UP_DP` (to hub IC upstream)
- Pins 5, 6 → net labels `USB_GAD_DM`, `USB_GAD_DP` (to DAW USB-C)

### Step 2.5 — Wire DSI Pins

On J2:
- Pins 30–45 → net labels `DSI_CLK_P`, `DSI_CLK_N`, `DSI_D0_P`, `DSI_D0_N`, `DSI_D1_P`, `DSI_D1_N`

> Check the official CM4 datasheet for exact DSI pin numbers. The Raspberry Pi Foundation provides a reference carrier schematic.

### Step 2.6 — Wire SD Card Pins

On J2:
- Pin 74 → `SD_CLK`
- Pin 76 → `SD_CMD`
- Pins 78–84 → `SD_DAT0`, `SD_DAT1`, `SD_DAT2`, `SD_DAT3`

### Step 2.7 — Place MicroSD Slot (J18)

1. Search: **`C585350`**
2. Place → label `J18`
3. Wire SD_CLK/CMD/DAT0-3 from net labels to J18 pins
4. J18 VDD → `V3V3`, J18 VSS → `GND`

### Step 2.8 — Place CM4 Decoupling

| Search | Label | Placement |
|---|---|---|
| `C1525` (100nF) ×4 | C1, C2, C3, C4 | Near J1 pins 4/5, across to GND |
| `C19702` (10µF) ×1 | C5 | Near J1 5V pins |

### Step 2.9 — Boot Config

1. Place a 10kΩ resistor (`C25744`) from nRPIBOOT (J1 pin 91) to V3V3 — label `R_BOOT`
2. Place a 2-pin header next to it — short pins = USB boot, open = normal boot

### Step 2.10 — I2C Lines

- Wire J1 GPIO 2 → net `I2C_SCL` (connects to STUSB4500 on power sheet)
- Wire J1 GPIO 3 → net `I2C_SDA`

---

## 3. Sheet: 03_USB_Hub (USB2514B ×2 Cascade)

### Step 3.1 — Place Hub IC1 (U2)

1. Search: **`C136518`** (USB2514B-I/M2)
2. Place → label `U2`

### Step 3.2 — Place Crystal for U2

1. Search: **`C32346`** (24 MHz crystal)
2. Place → label `Y1`
3. Search: **`C1808`** (18pF 0402) — place two → label `CY1a`, `CY1b`
4. Wire:
   - U2 XTAL1 → Y1 pin 1 → CY1a → GND
   - U2 XTAL2 → Y1 pin 2 → CY1b → GND

### Step 3.3 — Wire U2 Upstream

- U2 USBDP → net `USB_UP_DP` (from CM4 sheet)
- U2 USBDM → net `USB_UP_DM`

### Step 3.4 — Wire U2 Downstream Ports 1–3

- U2 DN1_DP → net `HUB1_DN1_DP`
- U2 DN1_DM → net `HUB1_DN1_DM`
- U2 DN2_DP → net `HUB1_DN2_DP`
- U2 DN2_DM → net `HUB1_DN2_DM`
- U2 DN3_DP → net `HUB1_DN3_DP`
- U2 DN3_DM → net `HUB1_DN3_DM`

### Step 3.5 — Wire U2 Port 4 → U3 Cascade

- U2 DN4_DP → net `HUB_CASCADE_DP`
- U2 DN4_DM → net `HUB_CASCADE_DM`

### Step 3.6 — Place Hub IC2 (U3) + Crystal

1. Same parts: `C136518` → U3, `C32346` → Y2, `C1808` ×2 → CY2a, CY2b
2. Wire crystal same way as U2

### Step 3.7 — Wire U3 Upstream (Cascade)

- U3 USBDP → net `HUB_CASCADE_DP`
- U3 USBDM → net `HUB_CASCADE_DM`

### Step 3.8 — Wire U3 Downstream Ports 1–4

- U3 DN1_DP/DM → `HUB2_DN1_DP/DM`
- U3 DN2_DP/DM → `HUB2_DN2_DP/DM`
- U3 DN3_DP/DM → `HUB2_DN3_DP/DM`
- U3 DN4_DP/DM → `HUB2_DN4_DP/DM`

### Step 3.9 — Hub IC Config Pins (Both U2 and U3)

For each hub IC:
- VDD33 → `V3V3` + C (100nF `C1525`) → GND
- VDDA33 → `V3V3` + C (100nF) → GND
- CRFILT → C (10nF) → GND
- RESET_N → 10kΩ (`C25744`) → `V3V3`
- CFG_SEL0 → GND
- CFG_SEL1 → GND
- VBUS_DET → `VBUS_5V` via 100kΩ/47kΩ divider (check datasheet)
- PRTPWR1–4 → (leave NC or connect to polyfuse enable — optional)
- Upstream pull-up: 1.5kΩ (`C4026`) from D+ to `V3V3`

### Step 3.10 — Decoupling

Place per hub IC:
- 4× `C1525` (100nF) near VDD pins
- 1× `C19702` (10µF) bulk cap

---

## 4. Sheet: 04_USB_Ports (8× USB-A + ESD + Polyfuses)

### Step 4.1 — Place 7× USB-A Connectors

1. Search: **`C46407`** (USB-A female)
2. Place 7 copies → label `J9` through `J15`

> 7 ports from the hub ICs. If you want an 8th (J16), connect it to the CM4's second USB host port directly — useful for a spare or debug port.

### Step 4.2 — Place ESD Protection (One Per Port)

1. Search: **`C7519`** (USBLC6-2SC6)
2. Place 7 copies → label `U4` through `U10`
3. For each port:
   - USBLC6 IO1 → connector D+
   - USBLC6 IO2 → connector D-
   - USBLC6 VBUS → VBUS_5V
   - USBLC6 GND → GND

Also place one more (U12) on the CM4 upstream USB lines.

### Step 4.3 — Place Polyfuses (One Per Port)

1. Search: **`C70069`** (500mA resettable fuse, 1206)
2. Place 7 copies → label `F1` through `F7`
3. Wire: `VBUS_5V` → F1 → J9 VBUS pin (repeat for each port)

### Step 4.4 — Wire Data Lines

For ports from Hub IC1 (J9–J11):
- J9 D+ → `HUB1_DN1_DP`, J9 D- → `HUB1_DN1_DM`
- J10 D+ → `HUB1_DN2_DP`, J10 D- → `HUB1_DN2_DM`
- J11 D+ → `HUB1_DN3_DP`, J11 D- → `HUB1_DN3_DM`

For ports from Hub IC2 (J12–J15):
- J12 D+ → `HUB2_DN1_DP`, J12 D- → `HUB2_DN1_DM`
- J13 D+ → `HUB2_DN2_DP`, J13 D- → `HUB2_DN2_DM`
- J14 D+ → `HUB2_DN3_DP`, J14 D- → `HUB2_DN3_DM`
- J15 D+ → `HUB2_DN4_DP`, J15 D- → `HUB2_DN4_DM`

### Step 4.5 — DAW Mode USB-C (J4)

1. Search: **`C2765186`** (USB-C 16-pin) → label `J4`
2. Search: **`C25905`** (5.1kΩ) → place 2 → label `R6`, `R7`
3. Wire:
   - J4 D+ → `USB_GAD_DP` (to CM4 OTG port)
   - J4 D- → `USB_GAD_DM`
   - J4 CC1 → R6 → GND
   - J4 CC2 → R7 → GND
   - J4 VBUS → leave NC (Mac provides power, but we don't use it)
   - J4 GND → GND

---

## 5. Sheet: 05_MIDI_OUT (4× DIN-5 Ports)

### Step 5.1 — Place DIN-5 Connectors

DIN-5 connectors are usually **not on LCSC**. Two options:

**Option A:** Search `DIN 5` in EasyEDA's library — there may be community footprints. Use a 5-pin generic connector symbol and assign the CUI SDS-50J footprint later.

**Option B:** Create a custom 5-pin symbol:
1. **File → New → Symbol** → name: `DIN5_MIDI_OUT`
2. Add 5 pins: Pin1 (NC), Pin2 (GND), Pin3 (NC), Pin4 (Source), Pin5 (Sink)
3. Save → use this symbol 4 times

Place 4 connectors → label `J5`, `J6`, `J7`, `J8`

### Step 5.2 — Place 220Ω Resistors

1. Search: **`C17557`** (220Ω 0805)
2. Place 8 copies → label `R8` through `R15`

### Step 5.3 — Wire Each MIDI Port

**Port J5 (MS-20 Mini, UART0):**
```
VBUS_5V → R8 (220Ω) → J5 Pin 4
MIDI_TX0 → R9 (220Ω) → J5 Pin 5
J5 Pin 2 → GND
```

**Port J6 (Volca #1, UART3):**
```
VBUS_5V → R10 (220Ω) → J6 Pin 4
MIDI_TX1 → R11 (220Ω) → J6 Pin 5
J6 Pin 2 → GND
```

**Port J7 (Volca #2, UART4):**
```
VBUS_5V → R12 (220Ω) → J7 Pin 4
MIDI_TX2 → R13 (220Ω) → J7 Pin 5
J7 Pin 2 → GND
```

**Port J8 (Volca #3, UART5):**
```
VBUS_5V → R14 (220Ω) → J8 Pin 4
MIDI_TX3 → R15 (220Ω) → J8 Pin 5
J8 Pin 2 → GND
```

### Step 5.4 — Add Silkscreen Labels

Use **Place → Text** to label each DIN connector on the schematic:
- J5: `MS-20`
- J6: `VOLCA 1`
- J7: `VOLCA 2`
- J8: `VOLCA 3`

---

## 6. Sheet: 06_Connectors (DSI, Fans, LEDs)

### Step 6.1 — DSI FPC Connector (J17)

1. Search: **`C262652`** (15-pin FPC 1mm pitch)
2. Place → label `J17`
3. Wire DSI net labels from CM4 sheet:
   - `DSI_CLK_P`, `DSI_CLK_N`
   - `DSI_D0_P`, `DSI_D0_N`
   - `DSI_D1_P`, `DSI_D1_N`
   - Power pins: VDD → `VBUS_5V`, GND → `GND`

### Step 6.2 — Fan Headers (J19, J20)

1. Search: **`C158012`** (2-pin JST-XH)
2. Place 2 copies → label `J19`, `J20`
3. Wire: Pin 1 → `VBUS_5V`, Pin 2 → `GND` (always-on fans)

### Step 6.3 — Power LED (LED1)

1. Search: **`C2297`** (green 0805 LED) → label `LED1`
2. Search: **`C11702`** (1kΩ 0402) → label `R16`
3. Wire: `VBUS_5V` → R16 → LED1 anode → LED1 cathode → GND

### Step 6.4 — Activity LED (LED2)

1. Search: **`C72041`** (blue 0805 LED) → label `LED2`
2. Place another 1kΩ resistor → label `R17`
3. Wire: CM4 GPIO (pick a spare, e.g., GPIO 25) → R17 → LED2 → GND
4. Add net label `ACT_LED` on the GPIO side

### Step 6.5 — MIDI TX LEDs (LED3–LED6, Optional)

1. Search: **`C2296`** (yellow 0805 LED) → place 4 → label `LED3`–`LED6`
2. Place 4× 1kΩ resistors → `R18`–`R21`
3. Wire each between the MIDI_TX net and GND:
   - `MIDI_TX0` → R18 → LED3 → GND
   - `MIDI_TX1` → R19 → LED4 → GND
   - `MIDI_TX2` → R20 → LED5 → GND
   - `MIDI_TX3` → R21 → LED6 → GND

> Note: these LEDs share the TX line with the MIDI resistors. They'll blink when data is sent. Dim but functional.

### Step 6.6 — Mounting Holes

1. Search `mounting hole` in EasyEDA library → select M3 (3.2mm)
2. Place 4 copies → label `H1`–`H4`
3. Connect pad to GND (ground-referenced mounting)

---

## 7. Convert Schematic → PCB

### Step 7.1 — Run ERC

1. **Design → Electrical Rules Check (ERC)**
2. Fix all errors. Common issues:
   - Unconnected pins → add "no connect" flags (×) on unused CM4 pins
   - Power flag missing → ensure at least one power port symbol per net
   - Net name conflicts → rename duplicates

### Step 7.2 — Generate PCB

1. **Design → Update/Convert Schematic to PCB**
2. EasyEDA creates a new PCB document with all footprints in a pile
3. All nets (wires) are shown as ratsnest lines

---

## 8. PCB Layout

### Step 8.1 — Board Setup

1. **Design → Board Options**:
   - Layers: **4** (if available in EasyEDA Pro; otherwise use 2-layer and widen USB traces)
   - Units: mm
   - Grid: 0.5mm placement, 0.25mm routing
2. Draw board outline: **~120mm × 100mm** rectangle on the Board Outline layer

### Step 8.2 — Place Connectors First (Edge Components)

These define your board edges:

| Edge | Components |
|---|---|
| **Top** | J3 (USB-C power), J4 (USB-C DAW), J19/J20 (fans) |
| **Bottom** | J9–J15 (USB-A ×7), J5–J8 (DIN-5 ×4) |
| **Right** | J17 (DSI FPC) |
| **Left** | J18 (MicroSD) — or near CM4 |

### Step 8.3 — Place CM4 Connectors

1. Place J1, J2 in the **center** of the board
2. The CM4 module will sit on top — keep a clearance zone above (no tall components under CM4)
3. Place decoupling caps C1–C5 **within 5mm** of J1 power pins

### Step 8.4 — Place ICs Near Their Connections

1. U2, U3 (USB hub ICs) → between CM4 and USB-A connectors
2. U13 (STUSB4500) → near J3 (USB-C power)
3. U14 (LDO) → near U13
4. U4–U10 (ESD) → as close as possible to each USB-A connector

### Step 8.5 — Place Passives

- Decoupling caps: **within 5mm** of the IC they serve
- Crystal: **within 10mm** of hub IC, with GND guard ring
- MIDI resistors: **within 10mm** of DIN-5 connectors
- Polyfuses: between 5V plane and each USB-A VBUS

### Step 8.6 — Route Critical Traces First

**Priority order:**

1. **USB differential pairs** (D+/D-):
   - Route as paired traces (use EasyEDA's differential pair tool if available)
   - Width: 0.18mm, gap: 0.18mm (90Ω differential)
   - Keep on top layer, over GND plane
   - No vias in differential pairs if possible
   - Length-match each pair within 0.5mm

2. **DSI differential pairs**:
   - Same rules as USB but 100Ω impedance
   - Keep traces as short as possible (<30mm)

3. **SD card traces**:
   - Length-match CLK/CMD/DAT lines within 5mm
   - Keep under 50mm total length

4. **MIDI TX traces** (low priority):
   - 31250 baud — no impedance requirement
   - Route on bottom layer to separate from USB
   - Any width 0.2mm+ is fine

5. **Power traces**:
   - Use copper pours / planes for VBUS_5V and GND
   - 5V traces to CM4 should be wide (0.5mm+) or use plane

### Step 8.7 — Copper Pours

1. **GND plane** on Layer 2 (inner 1): solid fill, no splits
2. **VBUS_5V plane** on Layer 3 (inner 2): fill most of the board
3. **V3V3 island** on Layer 3: small area near hub ICs and LDO
4. Top/bottom: add GND copper pours in empty areas (stitched with vias)

### Step 8.8 — Add Silkscreen

- Label each USB-A port: `USB1` through `USB7`
- Label each DIN-5: `MIDI 1 (MS-20)`, `MIDI 2 (V1)`, `MIDI 3 (V2)`, `MIDI 4 (V3)`
- Label USB-C connectors: `5V PD IN`, `DAW (Mac)`
- Add board name: `MIDI-BOX v2`
- Add your name / date / revision

---

## 9. Design Rule Check & Review

1. **Design → DRC** — fix all errors
2. **3D View** (Alt+3) — check:
   - CM4 module clears components below it
   - DIN-5 connectors don't collide with USB-A connectors
   - USB-C connectors are flush with board edge
   - Mounting holes are accessible

---

## 10. Order from JLCPCB

### Step 10.1 — Generate Manufacturing Files

EasyEDA Pro has a **one-click JLCPCB export**:

1. **Fabrication → One-click Order PCB/SMT at JLCPCB**
2. This auto-generates: Gerber, BOM, and CPL (pick-and-place) files
3. Review the BOM — ensure all LCSC part numbers are populated
4. Remove through-hole parts from SMT BOM (you'll hand-solder those)

### Step 10.2 — JLCPCB Order Settings

| Setting | Value |
|---|---|
| Layers | 4 |
| PCB Qty | 5 (minimum) |
| Thickness | 1.6mm |
| Surface Finish | ENIG (for QFN pads) |
| Copper Weight | 1 oz |
| Impedance Control | Yes — specify 90Ω diff for USB pairs |
| SMT Assembly | Yes (top side) |
| Assembly Side | Top |
| Tooling Holes | Added by JLCPCB |

### Step 10.3 — Review Before Paying

- Check the JLCPCB Gerber viewer — all layers look correct
- Verify BOM quantities match your design
- Check for any "part out of stock" warnings — swap LCSC numbers if needed
- Estimated lead time: ~7–10 days fabrication + 5–7 days shipping

---

## 11. After Boards Arrive

### Hand-Solder Through-Hole Parts

| Part | Count | Difficulty |
|---|---|---|
| DIN-5 connectors (J5–J8) | 4 | Easy |
| USB-A connectors (J9–J15) | 7 | Easy |
| JST-XH fan headers (J19, J20) | 2 | Easy |
| 100µF electrolytic cap (C20) | 1 | Easy |
| **Total hand-solder** | **14 parts** | ~20 min |

### Plug In CM4

1. Align CM4 module on J1/J2 connectors
2. Press down firmly until it clicks
3. Insert MicroSD with flashed Pi OS

### Test Sequence

| Step | Test | Expected Result |
|---|---|---|
| 1 | Plug USB-C PD charger into J3 | Power LED (LED1) lights up |
| 2 | Measure VBUS_5V at TP1 | 4.7–5.0V |
| 3 | Measure V3V3 at TP2 | 3.3V |
| 4 | Insert MicroSD, power on | CM4 boots, activity LED blinks |
| 5 | Connect to WiFi hotspot | Web UI loads at :8080 |
| 6 | Plug USB MIDI device into J9 | Device appears in `aconnect -l` |
| 7 | Connect DIN cable to J5 | Send MIDI note, MS-20 responds |
| 8 | Connect Mac to J4 (DAW port) | Pi appears as USB MIDI device in Logic |

---

## Quick Reference: All LCSC Part Numbers

Copy-paste these into EasyEDA search:

```
C506281   — Hirose DF40C-100DS (CM4 connector) ×2
C136518   — USB2514B-I/M2 (USB hub IC) ×2
C32346    — 24 MHz crystal ×2
C7519     — USBLC6-2SC6 (USB ESD) ×9
C2678061  — STUSB4500QTR (PD sink) ×1
C2765186  — USB-C 16-pin receptacle ×2
C51118    — AP2112K-3.3 (3.3V LDO) ×1
C8678     — SS34 Schottky diode ×1
C70069    — 500mA polyfuse ×8
C46407    — USB-A female connector ×7
C262652   — 15-pin FPC connector ×1
C585350   — MicroSD card slot ×1
C158012   — JST-XH 2-pin header ×2
C1525     — 100nF 0402 capacitor ×16
C19702    — 10µF 0805 capacitor ×4
C1808     — 18pF 0402 capacitor ×4
C1779     — 4.7µF 0805 capacitor ×1
C72505    — 100µF electrolytic capacitor ×1
C17557    — 220Ω 0805 resistor ×8
C11702    — 1kΩ 0402 resistor ×6
C4026     — 1.5kΩ 0402 resistor ×2
C25905    — 5.1kΩ 0402 resistor ×4
C25744    — 10kΩ 0402 resistor ×1
C2297     — Green LED 0805 ×1
C72041    — Blue LED 0805 ×1
C2296     — Yellow LED 0805 ×4
```

> **Before ordering:** Search each number in LCSC to verify stock. Parts go out of stock often — substitute with same value/package alternatives.

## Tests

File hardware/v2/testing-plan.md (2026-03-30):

# MIDI Box v2 — Complete Testing Plan

Test every v2 subsystem before ordering the final PCB. Three test methods combined:

- **Breadboard** — exact same ICs on QFN-to-DIP adapters + through-hole passives (same values). See [breadboard-prototype.md](breadboard-prototype.md) for full wiring guide.
- **Off-the-shelf boards** — CM4 IO Board, USB power meter, USB-C breakouts from AliExpress/Amazon
- **Custom breakout PCBs** — optional, order from JLCPCB if you want a cleaner test setup than bare adapters

---

## Risk Map: What Needs Testing

Since v1 already works, the **only unknowns** in v2 are:

| Subsystem | New in v2? | Risk | Why |
|---|---|---|-----|
| MIDI OUT circuits | No — same circuit | **None** | Already proven in v1 |
| USB MIDI devices | No — same devices | **None** | Already proven in v1 |
| Software | No — no changes | **None** | Already proven in v1 |
| CM4 as carrier module | **Yes** | **Medium** | Different form factor, Hirose connectors, need to verify GPIO/UART/USB routing |
| USB2514B hub IC | **Yes** | **Medium** | New IC, pin-strap config, crystal, cascade wiring |
| STUSB4500 USB-PD | **Yes** | **Low** | Commodity IC, well-documented, but NVM programming is new |
| USB-C connectors | **Yes** | **Low** | CC resistor values, footprint correctness |
| Power distribution | **Partly** | **Low** | Same budget as v1, just different delivery (PD vs barrel) |
| 4-layer PCB routing | **Yes** | **Low** | USB impedance, DSI — handled by fab house |

**Testing priority: CM4 carrier > USB hub > USB-PD > everything else.**

---

## Test Strategy Per Subsystem

### 1. CM4 Carrier — Buy Off-the-Shelf CM4 IO Board

**Don't build this yourself.** The official Raspberry Pi CM4 IO Board ($35) is the gold standard carrier. Buy one, plug in your CM4, and verify everything works before designing your own carrier.

**What to buy:**

| Product | Price | Where | Search Term |
|---|---|---|---|
| **Raspberry Pi CM4 IO Board** (official) | ~$35 | Amazon / Pimoroni / The Pi Hut | `"CM4 IO Board"` |
| **Raspberry Pi CM4** (2GB WiFi, Lite) | ~$35 | Same resellers | `"CM4 Lite 2GB WiFi"` |
| MicroSD card (for CM4 Lite) | ~$8 | Amazon | You have one already |

**What this tests:**

| Test | How | Expected Result |
|---|-----|---|
| CM4 boots from MicroSD | Flash same Pi OS image as your Pi 4 | Boots, WiFi works |
| GPIO UARTs work | Enable UART overlays, connect MIDI OUT circuit | Same as Pi 4 — `/dev/ttyAMA0,2,3,4` |
| USB host works | Plug USB MIDI device into IO board USB | Shows in `lsusb` and `aconnect -l` |
| USB gadget works | Connect IO board USB-C to Mac | Pi appears as MIDI device |
| DSI works | Connect 5" touchscreen to IO board DSI | Display works |
| Full software works | Run `python3 src/main.py` | Web UI loads, routing works |
| I2C works | `i2cdetect -y 1` | Bus functional (for STUSB4500 later) |

`★ Insight ─────────────────────────────────────`
**Why this is the most important test:** If your software runs identically on the CM4 IO Board as it does on the Pi 4, then CM4 compatibility is validated. Everything else (USB hub, PD, MIDI) are just peripheral circuits wired to the same GPIO/USB pins. The CM4 IO Board proves that the CM4 module itself works for your use case — and it costs less than one failed PCB revision.
`─────────────────────────────────────────────────`

> **Keep the CM4 IO Board permanently.** Even after your v2 PCB works, it's invaluable for debugging — if something breaks on v2, swap the CM4 to the IO Board to isolate whether it's a CM4 issue or a carrier board issue.

---

### 2. USB Hub (USB2514B) — Off-the-Shelf + Custom Breakout

**Phase A: Off-the-shelf USB2514B board (validate IC works)**

| Product | Price | Where | Search Term |
|---|---|---|---|
| **USB2514B evaluation/breakout board** | ~$5–10 | AliExpress | `"USB2514B module"` or `"USB2514 hub board"` |
| **Generic 7-port USB 2.0 hub board** (bare PCB) | ~$3–5 | AliExpress | `"USB 2.0 7 port hub module PCB"` or `"FE1.1s 7 port hub"` |

> Many cheap AliExpress hub boards use GL850G or FE1.1s instead of USB2514B. That's fine for Phase A — you're testing whether the Pi can handle 7 downstream ports and 6 MIDI devices simultaneously. If you can find a USB2514B-based board, even better.

**Test with off-the-shelf board:**

| Test | How | Expected Result |
|---|-----|---|
| Hub enumerates | Plug hub into CM4 IO Board USB | `lsusb` shows hub + all devices |
| 6 MIDI devices work | Plug all 6 USB MIDI devices | All show in `aconnect -l` |
| Simultaneous routing | Route KeyLab → 3 destinations | No dropped notes, no latency increase |
| Sustained load | Run for 1 hour with active routing | No USB disconnects |

**Phase B: Custom breakout PCB (validate YOUR circuit)**

Only do this if you want to test the exact USB2514B pin-strap configuration and crystal circuit from your v2 design. See [breakout-boards.md](breakout-boards.md) Board 1.

Order from JLCPCB: ~$10 for 5 boards with SMT assembly. Plug into breadboard, wire to CM4 IO Board USB port.

**Test with custom breakout:**

| Test | How | Expected Result |
|---|-----|---|
| IC enumerates with pin-strap config | Plug into CM4 USB | Shows as hub in `lsusb` (VID/PID = Microchip) |
| All 4 downstream ports work | Plug USB device into each port | All 4 enumerate |
| Cascade works | Wire Board 1a DN4 → Board 1b upstream | 7 total ports visible |
| Self-powered mode correct | Check `lsusb -v` output | `Self Powered: yes` |

---

### 3. USB-PD Power (STUSB4500) — Buy SparkFun Board

**Don't make a breakout for this. SparkFun already sells one.**

| Product | Price | Where | Search Term |
|---|---|---|---|
| **SparkFun STUSB4500 Breakout** (DEV-15801) | ~$12 | Amazon / SparkFun | `"SparkFun STUSB4500"` or `"STUSB4500 breakout"` |
| **Generic STUSB4500 module** | ~$5–8 | AliExpress | `"STUSB4500 PD sink module"` or `"USB-C PD trigger STUSB4500"` |
| **WITRN USB-C PD trigger board** | ~$5 | AliExpress | `"USB-C PD trigger board 5V"` — various ICs, some use STUSB4500 |

The SparkFun board is pin-for-pin what you need: STUSB4500 + USB-C connector + CC resistors + header pins. It even has a Qwiic I2C connector for easy NVM programming.

**Test with SparkFun board:**

| Test | How | Expected Result |
|---|-----|---|
| PD negotiation works | Plug any USB-C PD charger | POWER_OK LED on, VBUS outputs 5V |
| 5V @ 3A delivery | Connect to CM4 IO Board + USB hub + MIDI | Stable 5V under full load |
| NVM programming | Use `pystusb4500` Python lib over I2C from Pi | Set PDO1 = 5V/3A, verify with `i2cget` |
| Fallback (non-PD charger) | Plug non-PD USB-C charger | Still outputs 5V (at lower current) |
| Measure voltage drop | Multimeter on VBUS output under load | 4.7V–5.1V |

**NVM programming test (run on Pi/CM4):**

```bash
pip install pystusb4500
python3 -c "
from stusb4500 import STUSB4500
pd = STUSB4500(bus=1)
pd.set_pdo(1, voltage=5.0, current=3.0)
pd.write_nvm()
print('NVM programmed: 5V @ 3A')
print(pd.read_pdo(1))
"
```

`★ Insight ─────────────────────────────────────`
**Why buy instead of build for PD:** The STUSB4500 circuit is simple (IC + 3 resistors + 2 caps + USB-C connector), but the USB-C connector footprint is fiddly and the QFN-24 package is hard to hand-solder. SparkFun's $12 board saves you a custom breakout PCB run AND lets you test NVM programming immediately. Once validated, you copy the exact same circuit to your v2 PCB — the IC doesn't care what board it's on.
`─────────────────────────────────────────────────`

---

### 4. USB-C Connectors (DAW Mode) — Breadboard Test

The DAW mode USB-C port just needs D+, D-, CC1, CC2, and GND. Test with a cheap USB-C breakout.

| Product | Price | Where | Search Term |
|---|---|---|---|
| **USB-C female breakout board** (DIP) | ~$1–2 | AliExpress / Amazon | `"USB Type-C female breakout board DIP"` |

These are tiny boards with a USB-C receptacle broken out to 2.54mm pins. Perfect for breadboard.

**Breadboard wiring:**

```
USB-C breakout:
    CC1 → 5.1kΩ → GND    (breadboard resistor)
    CC2 → 5.1kΩ → GND    (breadboard resistor)
    D+  → CM4 IO Board USB OTG D+  (or Pi 4 USB-C data pin)
    D-  → CM4 IO Board USB OTG D-
    GND → GND
    VBUS → not connected (Mac provides, we don't use it)
```

**Test:**

| Test | How | Expected Result |
|---|-----|---|
| Mac detects USB device | Plug USB-C cable from breakout to Mac | Pi appears in System Information > USB |
| MIDI gadget works | Enable gadget mode, open Logic Pro | MIDI Box shows as MIDI interface |
| Bidirectional MIDI | Send note from Logic → Pi → hardware synth | Sound plays |

---

### 5. MIDI OUT Circuits — Breadboard (Already Done in v1)

You've already proven this circuit works. But test it one more time with the CM4 (on the IO Board) to confirm the UARTs are identical.

**Breadboard (same as v1):**

```
Per port:
    5V → 220Ω (through-hole) → DIN-5 Pin 4
    CM4 GPIO TX → 220Ω (through-hole) → DIN-5 Pin 5
    DIN-5 Pin 2 → GND
```

**Test: send MIDI from CM4 to each synth — should work identically to Pi 4.**

---

### 6. DSI Display — Direct Test on CM4 IO Board

The CM4 IO Board has a DSI connector. Just plug in your existing 5" touchscreen.

| Test | How | Expected Result |
|---|-----|---|
| Display works | Connect DSI ribbon to IO Board | Screen displays desktop/kiosk |
| Touch works | Tap screen | Touch input registered |
| Kiosk mode | Boot with `midi-box-kiosk.service` | Shows `/display` page |

No breadboard or breakout needed — the IO Board tests this directly.

---

### 7. Power Distribution — Load Test on Breadboard

Test total system power draw with all components connected. Use the SparkFun STUSB4500 board as the power source.

```
    USB-C PD Charger (5V/3A+)
        │
    SparkFun STUSB4500 board → VBUS_OUT
        │
        ├──→ CM4 IO Board (5V in)
        ├──→ USB Hub board (5V in)
        ├──→ MIDI OUT circuits (5V in, via breadboard)
        └──→ Fans (5V in)

    Measure with USB power meter between charger and board.
```

| Test | How | Expected Result |
|---|-----|---|
| Idle current | Pi booted, no MIDI activity | ~1.5–2.0A |
| Full load | 6 USB devices + 4 MIDI ports active + fans | ~3.0–3.6A |
| No brownout | Play MIDI intensively for 30 min | Voltage stays above 4.75V |
| Charger compatibility | Test with 3 different PD chargers | All work |

**Recommended USB power meter:**

| Product | Price | Where | Search Term |
|---|---|---|---|
| **WITRN C5 / C4** USB-C power meter | ~$15–25 | AliExpress / Amazon | `"WITRN C5 USB-C power meter"` or `"USB-C PD tester"` |
| **ChargerLAB KM003C** | ~$40 | Amazon | Premium option, shows PD negotiation details |

`★ Insight ─────────────────────────────────────`
**A USB power meter is essential for this project.** It shows real-time voltage, current, and PD negotiation status. When you plug your PD charger into the STUSB4500, you can see exactly what voltage/current was negotiated. When testing under load, you can see if voltage drops below 4.75V (which would cause CM4 instability). It's $15 and you'll use it forever. Get the WITRN C5 — it decodes PD packets and shows them on screen.
`─────────────────────────────────────────────────`

---

## Complete Shopping List

### Off-the-Shelf Boards

| # | Product | Price | Source | Purpose |
|---|---|---|---|---|
| 1 | **Raspberry Pi CM4** (2GB, WiFi, Lite) | ~$35 | Pi reseller | The actual compute module for v2 |
| 2 | **Raspberry Pi CM4 IO Board** | ~$35 | Pi reseller / Amazon | Test CM4 carrier functions |
| 3 | **SparkFun STUSB4500 Breakout** | ~$12 | Amazon / SparkFun | Test USB-PD power input |
| 4 | **USB 2.0 hub module board** (7-port) | ~$5 | AliExpress | Test multi-port USB hub with MIDI devices |
| 5 | **USB-C female breakout** (DIP, 2.54mm) | ~$2 | AliExpress | Test DAW mode USB-C connector |
| 6 | **USB-A female breakout** (DIP) ×4 | ~$4 | AliExpress | Connect USB MIDI devices on breadboard |
| 7 | **WITRN C5 USB-C power meter** | ~$20 | AliExpress / Amazon | Measure voltage/current/PD status |
| | **Subtotal** | **~$113** | | |

### Breadboard Supplies

| # | Product | Qty | Price | Notes |
|---|---|-----|---|---|
| 8 | Full-size breadboard (830 pts) | 2 | ~$10 | You may already have these |
| 9 | Jumper wire kit (M-M, M-F, F-F) | 1 | ~$5 | |
| 10 | 220Ω resistors (through-hole) | 8 | ~$0.50 | MIDI OUT circuits |
| 11 | 5.1kΩ resistors (through-hole) | 4 | ~$0.50 | USB-C CC pull-downs |
| 12 | 1kΩ resistors (through-hole) | 6 | ~$0.50 | LEDs |
| 13 | 5-Pin DIN connectors (PCB mount) | 4 | ~$4 | MIDI OUT — may already have from v1 |
| 14 | 5mm LEDs (assorted) | 6 | ~$1 | Status indicators |
| 15 | 100nF + 10µF capacitors (through-hole) | 10 | ~$1 | Decoupling |
| | **Subtotal** | | **~$22** | |

### Optional: Custom Breakout PCB (USB2514B)

Only if you want to validate your exact hub circuit before the final PCB.

| # | Product | Qty | Price | Notes |
|---|---|-----|---|---|
| 16 | USB2514B breakout PCB (JLCPCB, 2-layer, SMT assembled) | 5 | ~$15 | Tests exact circuit from v2 schematic |
| 17 | 2.54mm pin headers (to solder on breakouts) | 4 | ~$1 | |
| | **Subtotal** | | **~$16** | |

---

### Total Cost Summary

| Path | Cost | What You Validate |
|---|---|---|
| **Off-the-shelf boards only** | ~$135 | CM4 compatibility, PD power, USB hub capacity, DAW mode, full software |
| **+ breadboard MIDI circuits** | ~$157 | + MIDI OUT with CM4 UARTs (re-validates v1 circuit) |
| **+ custom USB2514B breakout** | ~$173 | + exact hub IC circuit from v2 design |

> **Recommendation:** Start with just the off-the-shelf boards ($135). That validates 90% of the design. Add the custom hub breakout only if you want extra confidence before the final PCB order.

---

## Testing Timeline

```
    WEEK 1 ─── Order everything
    │
    ├── Order CM4 + IO Board (Amazon / Pi reseller — 2-3 day shipping)
    ├── Order SparkFun STUSB4500 (Amazon — 2-3 day shipping)
    ├── Order USB-C power meter (Amazon — 2-3 day shipping)
    ├── Order AliExpress parts (hub board, breakouts, connectors — 7-14 day shipping)
    └── (Optional) Order USB2514B breakout PCB from JLCPCB (7-14 days)

    WEEK 2 ─── Test Phase 1 (CM4 + existing parts)
    │
    │   Amazon deliveries arrive (~day 3-4)
    │
    ├── Day 1: Flash MicroSD, boot CM4 on IO Board
    │          Verify: WiFi, SSH, GPIO, I2C, DSI touchscreen
    │
    ├── Day 1: Connect v1 Waveshare USB hubs to IO Board USB
    │          Verify: all 6 USB MIDI devices enumerate
    │
    ├── Day 1: Connect v1 MIDI OUT perfboard to CM4 GPIOs
    │          Verify: UART0/3/4/5 work identically to Pi 4
    │
    ├── Day 1: Run full midi-box software on CM4
    │          Verify: web UI, routing, presets, clock, everything
    │
    ├── Day 2: Test DAW mode (USB gadget) on CM4
    │          Connect IO Board USB-C to Mac
    │          Verify: gadget mode works on CM4
    │
    └── Day 2: Test STUSB4500 breakout (SparkFun)
               Program NVM for 5V/3A
               Power CM4 IO Board from STUSB4500 VBUS output
               Verify: stable 5V under load, measure with power meter

    ✅ CHECKPOINT: CM4 + PD power validated. If anything fails, debug here —
       don't proceed until this works.

    WEEK 3 ─── Test Phase 2 (New USB hub + breadboard)
    │
    │   AliExpress deliveries arrive (~day 10-14)
    │
    ├── Day 1: Wire breadboard MIDI OUT circuits
    │          Connect to CM4 IO Board GPIOs
    │          Verify: same results as perfboard (proves circuit, not just v1 board)
    │
    ├── Day 2: Connect off-the-shelf USB hub board to CM4
    │          Wire USB-A breakouts for each MIDI device
    │          Verify: all 6 devices work through hub board
    │
    ├── Day 2: Full integration test
    │          Power: STUSB4500 → CM4 IO Board
    │          USB: hub board → 6 MIDI devices
    │          MIDI: breadboard circuits → 4 DIN synths
    │          DAW: USB-C breakout → Mac
    │          Verify: everything works together, run for 1 hour
    │
    └── Day 3: Power stress test
               Measure total current draw with power meter
               Test with 3 different PD chargers
               Verify: no brownouts over 30 minutes

    ✅ CHECKPOINT: Full system validated with off-the-shelf parts.
       If the USB2514B breakout arrived, test it now.

    WEEK 3-4 ─── Test Phase 3 (Optional: custom USB2514B breakout)
    │
    │   JLCPCB breakout boards arrive (~day 10-14)
    │
    ├── Day 1: Solder pin headers on USB2514B breakout boards
    │          Plug into breadboard
    │          Wire: CM4 USB → Hub breakout 1 → Hub breakout 2 (cascade)
    │
    ├── Day 1: Verify hub enumerates
    │          Check `lsusb -v` — confirm VID/PID, self-powered, 4 ports per hub
    │
    ├── Day 2: Connect all 6 MIDI devices through custom hub breakouts
    │          Run full routing test
    │          Verify: identical behavior to off-the-shelf hub
    │
    └── Day 2: Run stress test — 1 hour continuous MIDI routing through custom hubs

    ✅ CHECKPOINT: Exact v2 hub circuit validated.

    WEEK 4-5 ─── Order Final v2 PCB
    │
    ├── Draw schematic in EasyEDA Pro (follow easyeda-guide.md)
    ├── Layout PCB
    ├── Run DRC/ERC
    ├── Order from JLCPCB (4-layer, SMT assembled)
    │
    └── Wait 10-14 days for delivery

    WEEK 6 ─── Final Assembly & Test
    │
    ├── Hand-solder through-hole connectors (DIN-5, USB-A, fan headers)
    ├── Plug in CM4
    ├── Power on — verify with USB power meter
    ├── Run full test sequence
    │
    └── ✅ DONE — v2 PCB validated and working
```

---

## Test-to-PCB Traceability

Every test maps directly to a v2 PCB subsystem. If a test passes, that subsystem is validated for the final board.

| Test Phase | What You Tested | v2 PCB Subsystem Validated | Confidence |
|---|---|---|---|
| CM4 on IO Board boots | CM4 + MicroSD + WiFi + GPIO | CM4 carrier circuit (schematics.md §1) | **High** |
| UART MIDI on CM4 | GPIO 14/4/8/12 UART TX | MIDI OUT (schematics.md §4) | **High** — same circuit as v1 |
| USB devices on CM4 | CM4 USB host + hub | USB hub upstream connection (schematics.md §2) | **High** |
| DSI on CM4 IO Board | DSI display passthrough | DSI connector (schematics.md §5) | **High** |
| USB gadget on CM4 | CM4 USB OTG → Mac | DAW mode USB-C (schematics.md §3) | **High** |
| STUSB4500 SparkFun board | PD negotiation, 5V output | USB-PD input (power.md) | **High** — same IC |
| Off-the-shelf USB hub | 7-port hub + 6 MIDI devices | Hub port count + software | **Medium** — different IC |
| Custom USB2514B breakout | Exact hub circuit | USB2514B cascade (schematics.md §2) | **Very high** — same circuit |
| Full integration on breadboard | All subsystems together | Power budget (power.md) | **High** |

**What's NOT tested until the final PCB:**
- Hirose DF40C connector footprint alignment (mechanical)
- USB trace impedance on 4-layer stackup (electrical)
- Component thermal performance with copper pours
- Physical board fits in enclosure

These are low-risk items. If all the above tests pass, the final PCB has a **very high** chance of working first try.

---

## Decision Tree: What If Something Fails?

```
    CM4 doesn't boot on IO Board?
    └── Check MicroSD image, try re-flash
    └── Try different CM4 module
    └── This is a CM4 hardware issue, not your design

    UARTs don't work on CM4?
    └── Check /boot/firmware/config.txt overlays
    └── CM4 uses same UART silicon as Pi 4 — should be identical
    └── If different: update device tree overlays (software fix)

    USB hub doesn't enumerate all devices?
    └── Power issue — add more bulk capacitance, use stronger supply
    └── Some MIDI devices are picky about hub latency — try different port order
    └── If USB2514B breakout fails but off-the-shelf hub works:
        your schematic has a wiring error — review pin-strap config

    STUSB4500 doesn't negotiate PD?
    └── NVM not programmed — re-program via I2C
    └── Charger doesn't support 5V PDO — try different charger
    └── CC resistors wrong — should be 5.1kΩ to GND

    System browns out under load?
    └── PD charger can't deliver enough current — use 5V/5A charger
    └── Cable too thin — use USB-C cable rated for 3A+
    └── Add more bulk capacitance (bigger electrolytic on 5V rail)

    DAW mode (USB gadget) doesn't work on CM4?
    └── IO Board USB-C port may default to host mode — check DIP switch
    └── CM4 USB OTG needs device tree config — check docs
    └── This is the one area where CM4 differs from Pi 4 — test carefully
```

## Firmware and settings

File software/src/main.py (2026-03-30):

#!/usr/bin/env python3
"""
MIDI Box - Main Entry Point

Initializes all subsystems and starts the MIDI routing engine + web UI.
Runs on both macOS (for testing) and Raspberry Pi (production).

Architecture:
  Process 1 (this process): MIDI routing engine — owns all MIDI hardware objects.
  Process 2 (Flask subprocess): Web API server — reads shared state, sends commands.
  IPC: multiprocessing.Manager shared dict + command queue.
"""

import os
import sys
import platform
import signal
from typing import Optional
import time
import logging
import logging.handlers
import argparse
import threading
import multiprocessing

import mido

# --- Targeted diagnostic logger (writes to data/midi_debug.log) ---
# Only captures transport send results and per-device send timing.
_diag_logger = logging.getLogger("midi-box.diag")
_diag_logger.setLevel(logging.DEBUG)
_diag_logger.propagate = False  # don't pollute console
_DIAG_LOG_PATH = os.path.join(
    os.path.dirname(os.path.dirname(os.path.abspath(__file__))), "data", "midi_debug.log"
)
_diag_handler = logging.handlers.RotatingFileHandler(
    _DIAG_LOG_PATH, maxBytes=512_000, backupCount=1,  # ~500 KB cap
)
_diag_handler.setFormatter(logging.Formatter("%(asctime)s  %(message)s", datefmt="%H:%M:%S"))
_diag_logger.addHandler(_diag_handler)

# Message types that must never appear in the MIDI monitor ring buffer.
# Clock (0xF8) fires 24 times per beat — logging it would flood the 500-entry
# buffer in under a second and add lock-acquisition overhead on the hot path.
_TRANSPORT_TYPES = frozenset(("clock", "start", "stop", "continue", "songpos"))

# Pre-allocated clock message — reused on every tick to avoid GC churn.
_CLOCK_MSG = mido.Message("clock")

from device_registry import DeviceRegistry
from alsa_midi import AlsaMidi
from router import MidiRouter
from preset_manager import PresetManager
from midi_logger import MidiLogger
from midi_player import MidiPlayer
from midi_looper import MidiLooper
from quick_recorder import QuickRecorder
from gpio_pedal import GpioPedal
from rtpmidi import RtpMidiServer
from clip_launcher import ClipLauncher
from clock_manager import ClockManager
from state import StateManager
from ui_web import LogBuffer, run_flask_process
from ipc import IpcBridge, STATE_UPDATE_INTERVAL

# ---------------------------------------------------------------------------
# Logging
# ---------------------------------------------------------------------------

logging.basicConfig(
    level=logging.INFO,
    format="%(asctime)s [%(name)s] %(levelname)s: %(message)s",
    datefmt="%H:%M:%S",
)
logger = logging.getLogger("midi-box")


def detect_platform() -> str:
    system = platform.system()
    if system == "Darwin":
        return "mac"
    elif system == "Linux":
        try:
            with open("/proc/device-tree/model") as f:
                if "raspberry" in f.read().lower():
                    return "pi"
        except FileNotFoundError:
            pass
        return "linux"
    return "unknown"


# ---------------------------------------------------------------------------
# MIDI Box Application
# ---------------------------------------------------------------------------

class MidiBox:
    def __init__(self, args):
        self.args = args
        self.platform = args.platform or detect_platform()
        self.registry = DeviceRegistry()
        self.alsa = AlsaMidi(
            on_device_connected=self._on_usb_device_connected,
            on_device_disconnected=self._on_usb_device_disconnected,
            on_message=self._on_usb_midi_received,
        )
        self.hw = None       # HardwareMidi, Pi only
        self.gadget = None   # GadgetMidi, Pi only
        self.router = MidiRouter()
        self.presets = PresetManager()
        self.state = StateManager()
        self.midi_logger = MidiLogger(max_entries=500)
        # ClockManager must be created before modules that depend on it
        self.clock_manager = ClockManager()
        self.player = MidiPlayer(clock_manager=self.clock_manager)
        self.looper = MidiLooper(clock_manager=self.clock_manager)
        self.launcher = ClipLauncher(clock_manager=self.clock_manager)
        self.log_buffer = LogBuffer()
        self.mode = "standalone"
        self.wifi_config = self._load_wifi_config()
        self.rtp_midi: Optional[RtpMidiServer] = None
        self._running = False
        self._web_process = None
        self.bridge = None
        self._performance_mode = False
        # Cached list of output device names for the clock broadcast loop.
        # Rebuilt once at startup and invalidated on hotplug events instead of
        # being recomputed from scratch on every 24-PPQ tick.
        self._clock_output_names: list[str] = []
        self._verbose = getattr(args, "verbose", False)
        self.recorder = QuickRecorder(recordings_dir="data/recordings",
                                      clock_manager=self.clock_manager)
        self.gpio_pedal = None

    def start(self):
        self.log_buffer.install()

        logger.info("=" * 50)
        logger.info("  MIDI Box Starting")
        logger.info(f"  Platform: {self.platform}")
        logger.info("=" * 50)

        # Restore saved state
        self.state.load()

        # Apply device overrides from saved state
        self.registry.set_device_overrides(
            self.state.state.get("device_overrides", {})
        )

        # Detect mode
        self.mode = self._detect_mode()
        logger.info(f"Mode: {self.mode.upper()}")

        # Register callbacks
        self.router.set_send_callback(self._send_midi)
        self.player._send_callback  = self._send_midi
        self.looper._send_callback  = self._send_midi
        self.launcher._send_callback = self._send_midi
        self.recorder._router_callback = self.router.process_message

        # Wire ClockManager clock callback via router:
        # router calls this for clock/start/stop/continue from the designated source
        self.router._clock_callback = self._on_external_clock_message

        # Broadcast MIDI clock (0xF8) to all output devices at 24 PPQ.
        # Works for both internal clock (generated by ClockManager thread) and
        # external clock (forwarded immediately when 0xF8 is received).
        self.clock_manager.register_midi_clock_callback(self._send_clock_to_outputs)

        # Open MIDI devices (real or mock)
        if self.args.mock:
            self._init_mock_devices()
        else:
            self._init_usb_midi()
            if self.platform == "pi":
                self._init_hardware_midi()

        # If DAW mode on Pi, set up USB gadget bridge
        if self.mode == "daw" and self.platform == "pi":
            self._init_gadget()

        # Restore routes from saved state, or fall back to preset
        self._restore_state()

        # Initialize clip launcher (restore state or auto-create layers)
        self._init_launcher()

        # Restore recorder/looper clock settings
        self._restore_clock_settings()

        # Start hotplug monitor for USB devices (skip in mock mode)
        if not self.args.mock:
            self.alsa.start_hotplug_monitor()

        # Start hardware MIDI read thread (Pi only)
        if self.hw:
            self.hw.start_reading(self._on_hw_midi_received)

        # Print status
        print()
        print(self.registry.list_devices())
        print()
        print(self.router.status())
        print()

        # Build the clock output device cache before the clock thread starts ticking.
        self._refresh_clock_outputs()

        # Start ClockManager (tick engine) then Launcher (tick subscriber)
        self.clock_manager.start()
        self.launcher.start()

        # Create IPC bridge and start web UI in a separate process
        self.bridge = IpcBridge()
        self._start_web_ui()

        # Start RTP-MIDI server (Apple MIDI over WiFi)
        self._init_rtpmidi()

        # GPIO foot pedal (Pi only)
        if self.platform == "pi":
            try:
                import yaml
                from pathlib import Path
                _cfg_path = Path(__file__).resolve().parent.parent / "config" / "midi_box.yaml"
                with open(_cfg_path) as _f:
                    _yaml = yaml.safe_load(_f) or {}
                gpio_cfg = _yaml.get("gpio_pedal", {})
            except Exception:
                gpio_cfg = {}
            self.gpio_pedal = GpioPedal(
                pin=gpio_cfg.get("pin", 17),
                pull_up=gpio_cfg.get("pull_up", True),
                debounce_ms=gpio_cfg.get("debounce_ms", 50),
                callback=self._on_pedal_press,
            )

        # Main loop
        self._running = True
        logger.info("Routing engine running. Press Ctrl+C to stop.")
        logger.info(f"Web UI: http://localhost:{self.args.port}")
        self._set_realtime_priority()
        self._main_loop()

    def stop(self):
        logger.info("Shutting down...")
        self.player.stop()
        self.looper.close()
        self.recorder.close()
        if self.gpio_pedal:
            self.gpio_pedal.close()
        self.launcher.stop()
        self.clock_manager.stop()
        if self.rtp_midi:
            self.rtp_midi.stop()
        self._save_state()
        self._running = False
        self.alsa.close_all()
        if self.hw:
            self.hw.close_all()
        if self.gadget:
            self.gadget.close()
        if self._web_process and self._web_process.is_alive():
            self._web_process.terminate()
        if self.bridge:
            self.bridge.close()
        logger.info("MIDI Box stopped.")

    # -------------------------------------------------------------------
    # Initialization
    # -------------------------------------------------------------------

    def _detect_mode(self) -> str:
        if self.args.mode:
            return self.args.mode
        # On Pi, check if Mac is connected via USB-C gadget
        if self.platform == "pi":
            try:
                from gadget import GadgetMidi
                g = GadgetMidi()
                if g.is_connected:
                    return "daw"
            except ImportError:
                pass
        return "standalone"

    def _init_usb_midi(self):
        """Open all USB MIDI devices and register them."""
        ports = self.alsa.open_all()
        for port in ports:
            device = self.registry.register_usb_device(port.port_name, port.port_name)
            if device:
                logger.info(f"  USB: {device.name} (port: {port.port_name})")
        if not ports:
            logger.info("  No USB MIDI devices found")
        # Apply any manually-saved port overrides (handles ALSA client number changes)
        self._apply_port_overrides()

    def _apply_port_overrides(self):
        """After all devices are registered, honour saved port_id overrides.

        ALSA assigns a new client number on every boot, so the full port string
        changes (e.g. "TR-8S:TR-8S MIDI 2 20:0" → "…32:0").  We store only the
        stable base name (everything before the trailing " dd:d" suffix) and
        find the matching open port at startup.
        """
        import re
        overrides = self.state.get_device_overrides()
        with self.alsa._lock:
            open_ports = list(self.alsa.ports.keys())
        for dev_name, cfg in overrides.items():
            saved_port = cfg.get("port_id", "")
            if not saved_port:
                continue
            dev = self.registry.get_device(dev_name)
            if not dev or dev.port_type != "usb":
                continue
            # Strip trailing ALSA "client:port" number to get the stable base
            base = re.sub(r'\s+\d+:\d+$', '', saved_port)
            match = next((p for p in open_ports if p.startswith(base)), None)
            if match and match != dev.port_id:
                logger.info(f"Port override: {dev_name} → {match} (was {dev.port_id})")
                dev.port_id = match

    def _load_wifi_config(self) -> dict:
        """Load WiFi AP settings from midi_box.yaml, falling back to defaults."""
        import yaml
        from pathlib import Path
        config_path = Path(__file__).resolve().parent.parent / "config" / "midi_box.yaml"
        defaults = {
            "ssid": "MIDI-BOX",
            "password": "midibox123",
            "ip": "192.168.4.1",
            "port": getattr(self.args, "port", 8080),
        }
        try:
            with open(config_path) as f:
                cfg = yaml.safe_load(f) or {}
            defaults.update(cfg.get("wifi_ap", {}))
            defaults["port"] = getattr(self.args, "port", 8080)
        except FileNotFoundError:
            pass
        return defaults

    def _init_mock_devices(self):
        """Register all devices from config as fake connected devices (no hardware needed)."""
        logger.info("Mock mode: loading all configured devices as virtual...")
        names = []

        for vendor_product, info in self.registry.usb_devices.items():
            name = info["name"]
            self.registry.register_usb_device(name, name, vendor_product)
            names.append(name)
            logger.info(f"  MOCK USB: {name}")

        for port_key in self.registry.hardware_ports:
            device = self.registry.register_hardware_device(f"/dev/{port_key}")
            if device:
                names.append(device.name)
                logger.info(f"  MOCK HW:  {device.name}")

        self.alsa.open_mock_devices(names)

    def _init_hardware_midi(self):
        """Open hardware MIDI ports (Pi only)."""
        try:
            from hw_midi import HardwareMidi
            self.hw = HardwareMidi()
            hw_config = self.registry.hardware_ports
            ports = self.hw.open_all(hw_config)
            for port in ports:
                device = self.registry.register_hardware_device(port.device_path)
                if device:
                    logger.info(f"  HW:  {device.name} ({port.device_path})")
        except ImportError:
            logger.info("  Hardware MIDI not available (not on Pi)")

    def _init_rtpmidi(self):
        """Start the RTP-MIDI (Apple MIDI) server and register it as a virtual device."""
        try:
            self.rtp_midi = RtpMidiServer(name="MIDI Box", port=5004)
            if self.rtp_midi.start():
                self.rtp_midi.set_on_message(self._on_rtpmidi_received)
                # Register as both input and output so it appears in routing
                self.registry.register_usb_device("RTP-MIDI (WiFi)", "RTP-MIDI (WiFi)")
                logger.info("RTP-MIDI (Apple MIDI over WiFi) ready")
            else:
                self.rtp_midi = None
        except Exception as exc:
            logger.warning(f"RTP-MIDI server failed to start: {exc}")
            self.rtp_midi = None

    def _init_gadget(self):
        """Set up USB gadget MIDI bridge (Pi only)."""
        try:
            from gadget import GadgetMidi
            self.gadget = GadgetMidi()
            if not self.gadget.is_configured:
                self.gadget.setup()
            if self.gadget.open_ports():
                logger.info("DAW bridge active")
            else:
                logger.warning("Could not open gadget ports")
        except ImportError:
            logger.info("  USB gadget not available (not on Pi)")

    def _restore_state(self):
        """Restore routes from saved state, or fall back to a preset."""
        saved_routes = self.state.get_routes()

        if saved_routes:
            # Drop any saved routes whose endpoints don't match real devices.
            known = set(self.registry.get_all_devices().keys())
            valid = [r for r in saved_routes if r["from"] in known and r["to"] in known]
            if len(valid) < len(saved_routes):
                dropped = [r["name"] for r in saved_routes if r not in valid]
                logger.warning(f"Dropped {len(dropped)} stale route(s) from state: {dropped}")
                self.state.set_routes(valid)
                saved_routes = valid

            logger.info(f"Restoring {len(saved_routes)} routes from saved state")
            self.router.load_routes(saved_routes)
            # Preset name (clock source is restored in _restore_clock_settings)
            self.presets.current_preset = self.state.get_preset()
        else:
            # No saved state — load from preset file
            preset_name = self.args.preset or self.state.get_preset() or "default"
            self._load_preset(preset_name)

    def _load_preset(self, name: str):
        data = self.presets.load(name)
        if not data:
            logger.warning(f"Preset '{name}' not found, running with no routes")
            return
        routes = self.presets.get_routes(data)
        self.router.load_routes(routes)
        # Preset may specify a routing clock source (device name for forwarding)
        clock = self.presets.get_clock_source(data)
        if clock:
            self.router.set_clock_source(clock)
        # Save to state
        self.state.set_preset(name)
        self.state.set_routes(self.router.dump_routes())

    def _init_launcher(self):
        """Initialize clip launcher — restore saved state or auto-create layers."""
        saved = self.state.get_launcher_state()
        if saved and saved.get("layers"):
            self.launcher.load_state(saved)
            logger.info(f"Launcher restored: {len(self.launcher.layers)} layers")
        else:
            # Auto-create one layer per output device, pre-seeding the device's
            # configured MIDI channel so the launcher doesn't need manual setup.
            for dev in self.registry.get_output_devices():
                self.launcher.add_layer(
                    name=dev.name,
                    destination=dev.name,
                    midi_channel=dev.midi_channel if dev.midi_channel else None,
                )
            logger.info(f"Launcher: auto-created {len(self.launcher.layers)} layers")

    def _on_external_clock_message(self, message) -> None:
        """
        Called by the router for every clock/start/stop/continue message from
        the designated clock source device (router already gates by source).
        """
        if message.type == "clock":
            self.clock_manager.on_midi_clock_tick()
            # 0xF8 broadcast is handled inside on_midi_clock_tick via _midi_clock_callback
        elif message.type == "start":
            self.clock_manager.on_transport_reset()
            self.launcher.on_transport_message(message)
            self._send_transport_to_outputs(message)
        elif message.type in ("stop", "continue"):
            self.launcher.on_transport_message(message)
            self._send_transport_to_outputs(message)

    def _restore_clock_settings(self):
        """Restore unified clock settings and per-module quantize from saved state."""
        # Unified clock (BPM + source)
        clock = self.state.get_clock()
        bpm = clock.get("bpm", 120.0)
        source = clock.get("source", "internal")
        self.clock_manager.set_bpm(bpm)
        self.clock_manager.set_source(source)
        if source != "internal":
            self.router.set_clock_source(source)
        logger.info(f"Clock restored: {bpm} BPM, source={source!r}")

        # Per-module quantize
        rec_clock = self.state.get_recorder_clock()
        if rec_clock:
            self.recorder.set_quantize(rec_clock.get("quantize", "free"))
            self.recorder.set_beats_per_bar(rec_clock.get("beats_per_bar", 4))

        loop_clock = self.state.get_looper_clock()
        if loop_clock:
            self.looper.set_quantize(loop_clock.get("quantize", "free"))
            self.looper.set_beats_per_bar(loop_clock.get("beats_per_bar", 4))

    def _get_output_device_names(self) -> list[str]:
        """Return list of output device names (for clock output)."""
        return [d.name for d in self.registry.get_output_devices()]

    def _persist(self):
        """Persist routes to disk."""
        self.state.set_routes(self.router.dump_routes())

    def _save_state(self):
        """Persist complete state to disk."""
        self.state.set_routes(self.router.dump_routes())
        # Unified clock state
        self.state.set_clock({
            "bpm": self.clock_manager.bpm,
            "source": self.clock_manager.source,
        })
        self.state.set_launcher_state(self.launcher.save_state())
        self.state.set_recorder_clock({
            "quantize": self.recorder._quantize,
            "beats_per_bar": self.recorder._beats_per_bar,
        })
        self.state.set_looper_clock({
            "quantize": self.looper._quantize,
            "beats_per_bar": self.looper._beats_per_bar,
        })
        logger.info("State saved")

    def _start_web_ui(self):
        """Start Flask web server in a separate process."""
        # Pre-populate shared state before Flask starts reading it
        self.bridge.state["midi_pid"] = os.getpid()
        self.bridge.state["wifi_config"] = self.wifi_config
        self.bridge.state["platform"] = self.platform
        self._update_shared_state()

        self._web_process = multiprocessing.Process(
            target=run_flask_process,
            args=(self.bridge, self.args.host, self.args.port),
            name="midi-box-web",
            daemon=True,
        )
        self._web_process.start()
        logger.info(f"Web UI process started (pid={self._web_process.pid})")

    # -------------------------------------------------------------------
    # Main Loop
    # -------------------------------------------------------------------
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

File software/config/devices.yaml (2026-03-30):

# =============================================================================
# MIDI Box - Device Configuration
# =============================================================================
# Maps USB vendor:product IDs to friendly names and default settings.
# Maps hardware serial ports to connected devices.
#
# To find your device's USB ID, run: lsusb
# To find ALSA MIDI port names, run: aconnect -l
# =============================================================================

usb_devices:
  # Arturia KeyLab mkII 88  (lsusb: 1c75:02cb)
  "1c75:02cb":
    name: "KeyLab mkII 88"
    type: controller
    ports: 2  # MIDI port + DAW port; MIDI port is registered (DAW port skipped)
    default_channel: 0  # 0 = all channels

  # Arturia KeyStep 32  (lsusb: 1c75:0288)
  "1c75:0288":
    name: "KeyStep"
    type: controller_sequencer
    ports: 1
    default_channel: 0

  # Behringer MODEL D  (lsusb: 1397:1214)
  "1397:1214":
    name: "MODEL D"
    type: synth
    ports: 1
    default_channel: 2

  # Roland Boutique JP-08  (lsusb: 0582:01b5, ALSA name: "Boutiq")
  "0582:01b5":
    name: "Boutiq"
    type: synth
    ports: 1
    default_channel: 3

  # Arturia MicroBrute  (lsusb: 1c75:0207)
  "1c75:0207":
    name: "MicroBrute"
    type: synth
    ports: 1
    default_channel: 7

  # Roland SP-404 MK2  (lsusb: 0582:01e5)
  "0582:01e5":
    name: "SP-404 MK2"
    type: sampler
    ports: 1
    default_channel: 10

  # Roland TR-8S  (lsusb: 0582:020a)
  "0582:020a":
    name: "TR-8S"
    type: drum_machine
    ports: 2
    default_channel: 10


# Hardware ports (Pi native UARTs via device tree overlays)
# Keys are the serial device basename (e.g., ttyAMA0)
#
# GPIO → UART → Device mapping:
#   GPIO 14 → UART0 → /dev/ttyAMA0  (dtoverlay=disable-bt)
#   GPIO 4  → UART3 → /dev/ttyAMA3  (dtoverlay=uart3)
#   GPIO 8  → UART4 → /dev/ttyAMA4  (dtoverlay=uart4)
#   GPIO 12 → UART5 → /dev/ttyAMA5  (dtoverlay=uart5)
hardware_ports:
  ttyAMA0:
    name: "MIDI OUT 2"
    gpio: 14
    direction: out
    type: synth
    default_channel: 1

  ttyAMA3:
    name: "MIDI OUT 1"
    gpio: 4
    direction: out
    type: synth
    default_channel: 2

  ttyAMA4:
    name: "MIDI OUT 4"
    gpio: 8
    direction: out
    type: synth
    default_channel: 3

  ttyAMA5:
    name: "MIDI OUT 3"
    gpio: 12
    direction: out
    type: synth
    default_channel: 4

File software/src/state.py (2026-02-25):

"""
State Manager - Persists application state to a JSON file.
Saves current preset, active routes, clock source, and user settings.
Auto-saves on changes, restores on startup.
"""

import json
import time
import logging
import shutil
from pathlib import Path

logger = logging.getLogger("midi-box.state")

STATE_DIR = Path(__file__).resolve().parent.parent / "data"
STATE_FILE = STATE_DIR / "state.json"
BACKUP_FILE = STATE_DIR / "state.backup.json"

DEFAULT_STATE = {
    "version": 2,
    "current_preset": "default",
    "clock": {              # unified clock — single BPM + source for whole system
        "source": "internal",
        "bpm": 120.0,
    },
    "routes": [],
    "device_overrides": {},       # {device_name: {direction, device_type, midi_channel}}
    "device_display_names": {},   # {internal_name: display_label} — cosmetic only
    "launcher": {},          # clip launcher state (layers, quantum, beats_per_bar)
    "recorder_clock": {      # per-module quantize only (BPM is in clock{})
        "quantize": "free",
        "beats_per_bar": 4,
    },
    "looper_clock": {        # per-module quantize only
        "quantize": "free",
        "beats_per_bar": 4,
    },
    "settings": {
        "mode": "standalone",
        "log_level": "INFO",
    },
    "last_saved": None,
}


class StateManager:
    def __init__(self, state_file: str = None):
        self.state_file = Path(state_file) if state_file else STATE_FILE
        self.state: dict = dict(DEFAULT_STATE)
        self._dirty = False

    def load(self) -> dict:
        """Load state from disk. Returns the state dict."""
        if not self.state_file.exists():
            logger.info("No state file found, using defaults")
            self.state = dict(DEFAULT_STATE)
            return self.state

        try:
            with open(self.state_file) as f:
                self.state = json.load(f)
            logger.info(f"State loaded: preset={self.state.get('current_preset')}, "
                        f"{len(self.state.get('routes', []))} routes")
            return self.state
        except (json.JSONDecodeError, KeyError) as e:
            logger.error(f"Corrupted state file: {e}, trying backup...")
            return self._load_backup()

    def _load_backup(self) -> dict:
        backup = self.state_file.parent / "state.backup.json"
        if backup.exists():
            try:
                with open(backup) as f:
                    self.state = json.load(f)
                logger.info("Restored from backup")
                return self.state
            except Exception:
                pass
        logger.warning("No valid backup, using defaults")
        self.state = dict(DEFAULT_STATE)
        return self.state

    def save(self):
        """Save current state to disk. Creates a backup of the previous state."""
        self.state_file.parent.mkdir(parents=True, exist_ok=True)
        self.state["last_saved"] = time.strftime("%Y-%m-%d %H:%M:%S")

        # Backup existing state file before overwriting
        if self.state_file.exists():
            backup = self.state_file.parent / "state.backup.json"
            shutil.copy2(self.state_file, backup)

        try:
            tmp = self.state_file.with_suffix(".tmp")
            with open(tmp, "w") as f:
                json.dump(self.state, f, indent=2)
            tmp.replace(self.state_file)
            self._dirty = False
            logger.debug("State saved")
        except Exception as e:
            logger.error(f"Failed to save state: {e}")

    def set_preset(self, name: str):
        self.state["current_preset"] = name
        self.save()

    def set_routes(self, routes: list[dict]):
        self.state["routes"] = routes
        self.save()

    def set_clock_source(self, source: str | None):
        # Legacy: kept for backward compat; use set_clock() for unified clock
        self.state["clock_source"] = source
        self.save()

    def get_clock(self) -> dict:
        """Return unified clock state {source, bpm}."""
        defaults = {"source": "internal", "bpm": 120.0}
        stored = self.state.get("clock", {})
        # Also migrate legacy launcher.clock.bpm if present and clock not set
        if not stored and "launcher" in self.state:
            launcher_clock = self.state["launcher"].get("clock", {})
            if launcher_clock.get("bpm"):
                defaults["bpm"] = launcher_clock["bpm"]
        return {**defaults, **stored}

    def set_clock(self, data: dict):
        """Persist unified clock state."""
        if "clock" not in self.state:
            self.state["clock"] = {}
        self.state["clock"].update(data)
        self.save()

    def get_preset(self) -> str:
        return self.state.get("current_preset", "default")

    def get_routes(self) -> list[dict]:
        return self.state.get("routes", [])

    def get_clock_source(self) -> str | None:
        return self.state.get("clock_source")

    def get_launcher_state(self) -> dict:
        return self.state.get("launcher", {})

    def set_launcher_state(self, data: dict):
        self.state["launcher"] = data
        self.save()

    def get_device_display_names(self) -> dict:
        return dict(self.state.get("device_display_names", {}))

    def set_device_display_name(self, internal_name: str, display_name: str) -> None:
        names = self.state.get("device_display_names", {})
        names[internal_name] = display_name
        self.state["device_display_names"] = names
        self.save()

    def remove_device_display_name(self, internal_name: str) -> None:
        names = self.state.get("device_display_names", {})
        if internal_name in names:
            del names[internal_name]
            self.state["device_display_names"] = names
            self.save()

    def get_device_overrides(self) -> dict:
        return self.state.get("device_overrides", {})

    def set_device_override(self, name: str, config: dict):
        if "device_overrides" not in self.state:
            self.state["device_overrides"] = {}
        self.state["device_overrides"][name] = config
        self.save()

    def get_recorder_clock(self) -> dict:
        defaults = {"quantize": "free", "beats_per_bar": 4}
        return {**defaults, **self.state.get("recorder_clock", {})}

    def set_recorder_clock(self, data: dict):
        self.state["recorder_clock"] = data
        self.save()

    def get_looper_clock(self) -> dict:
        defaults = {"quantize": "free", "beats_per_bar": 4}
        return {**defaults, **self.state.get("looper_clock", {})}

    def set_looper_clock(self, data: dict):
        self.state["looper_clock"] = data
        self.save()

    def get_settings(self) -> dict:
        return self.state.get("settings", {})

    def update_settings(self, **kwargs):
        if "settings" not in self.state:
            self.state["settings"] = {}
        self.state["settings"].update(kwargs)
        self.save()
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

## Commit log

2026-02-18 Initial commit: MIDI Box router project
    DIY MIDI router/patchbay connecting 10 synths and controllers.
    Runs on Mac (dev) and Raspberry Pi (production) with web UI.
    - Core routing engine with channel filtering and remapping
    - USB MIDI device management via ALSA/rtmidi
    - Hardware MIDI I/O via SC16IS752 (Pi only)
    - USB gadget mode for Logic Pro integration (Pi only)
    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
2026-02-18 fix: add midi control when no device found
    [alsa_midi.py]
2026-02-18 fix: player ver 1
    [alsa_midi.py, device_registry.py, main.py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]
2026-02-18 fix: change alsa and router naming same
    [main.py]
2026-02-18 fix: add multi thead
    [main.py]
2026-02-18 fix: add system performance menu
    [ui_web.py]
2026-02-18 Separate MIDI engine and web UI into independent processes
    - New ipc.py: IpcBridge using multiprocessing.Manager shared dict +
    command queue for true cross-process communication
    - main.py: Flask now runs in a daemon subprocess (Process instead of
    Thread), MIDI loop processes commands every ~1ms and pushes a full
    state snapshot to the shared dict every 200ms
    - ui_web.py: All Flask routes read from bridge.state (zero direct
    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
2026-02-18 feat: switch AP to virtual uap0 interface for dual WiFi (home + hotspot)
    wlan0 stays connected to home WiFi for SSH/internet access.
    uap0 (virtual interface on wlan0) broadcasts the MIDI-BOX hotspot.
    Adds midi-box-ap-iface.service to create uap0 on every boot.
2026-02-21 fix: couple bug
2026-02-21 fix: update wifi update feature
    [alsa_midi.py, main.py, midi_box.yaml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]
2026-02-21 feat: MIDI Panic button MIDI Looper RTP-MIDI (Apple MIDI over WiFi)
2026-02-22 fix: new version of updated
    [updater.py]
2026-02-22 fix: update some documents
    [midi_box.yaml]
2026-02-22 fix: update alsa midi and devices
    [alsa_midi.py, devices.yaml]
2026-02-22 fix: update midi clock rule for output devices
    [main.py]
2026-02-22 feat: add BPM, quantize, and beat-synced recording to recorder & looper
    - Add tick subscriber mechanism to ClipLauncher for clock sync
    - Upgrade QuickRecorder with clock source (OWN/SYNC/EXT), BPM control,
    quantize options (free, 1/16, 1/8, 1/4, bar, 2bar, 4bar), count-in
    state, and quantized loop length
    - Upgrade MidiLooper with same clock/quantize features, per-slot count-in
    - Add recorder/looper clock API endpoints and IPC commands
    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
2026-02-22 fix: update midi channel routing
    [main.py]
2026-02-22 docs: enclosure export
    [midi-box-v1.3-back.stl, midi-box-v1.3-bottom.stl, midi-box-v1.3-top.stl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]
2026-02-23 feat: add clock manager
    [midi-box.kicad_pcb, midi-box.kicad_sch]
2026-02-23 fix: bpm and clock
    [clock_manager.py, main.py, router.py]
2026-02-23 fix: update clock to bpm
    [clock_manager.py]
2026-02-23 fix: update clock manager maxlen=96
    [clock_manager.py]
2026-02-23 fix: update bpm clock manager
    [clock_manager.py]
2026-02-24 fix: update midi player and add network midi
    [midi_player.py]
2026-02-25 fix: add device finder screens
    [devices.yaml, main.py, router.py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]
2026-02-26 fix: add raw port selection on UI
    [main.py, ui_web.py]
2026-02-26 fix: filter out other devices ports on ALSA port selection UI
2026-02-28 fix: update launcher screen
    [clip_launcher.py, main.py, ui_web.py]
2026-03-18 fix: add display stutff
    [ui_web.py]
2026-03-19 fix: update couple places
    [device_registry.py, devices.yaml, hw_midi.py]
2026-03-20 fix: update couple things
    [devices.yaml, hw_midi.py, test_midi_out.py]
2026-03-20 fix: update midi player
    [midi_player.py]
2026-03-20 fix: update some bugs
    [clip_launcher.py, clock_manager.py, ipc.py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]
2026-03-29 fix: small changes on GPIO pins
    [devices.yaml, hw_midi.py]
2026-03-30 fix: many changes
    [midi-box.kicad_sch, untitled.kicad_sch]
